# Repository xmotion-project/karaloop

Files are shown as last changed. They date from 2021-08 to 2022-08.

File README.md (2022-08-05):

<p align="center">
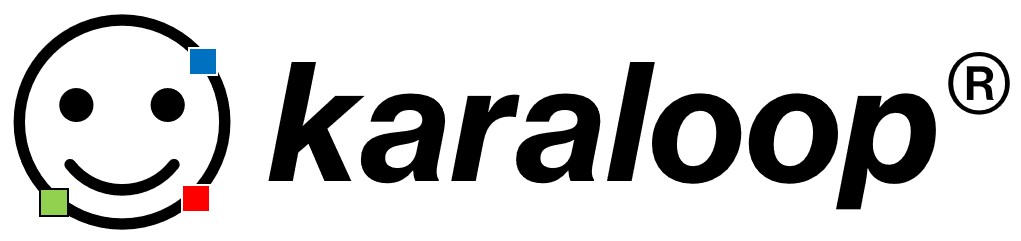
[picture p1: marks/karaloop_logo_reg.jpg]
	
</p>  

<p align="center">	
	 
</p>

Can you imagine yourself interacting with phones, tablets, computers and other devices without hands? 

***karaloop*** is an initiative to advance the development of accessible and inclusive wearable hands-free interfaces, so in the future, anyone will be able to interact with any device, from anywhere, *without hands*, simply by performing movements of the face :relaxed:

The primary goal is to enable ubiquitous human-device interaction to all, regardless of physical abilities, environmental and socioeconomical constrains.     

## Contents

This repository contains a collection of wearable prototypes which measure voluntary movements of the face and translate them 
into mouse or keyboard commands sent via Bluetooth Low Energy (BLE) to any PC, iOS or Android device.

* [***karaloop*** P1.0](https://github.com/xmotion-project/karaloop/wiki/karaloop-P1.0)
* [***karaloop*** P2.0](https://github.com/xmotion-project/karaloop/wiki/karaloop-P2.0)
* [***karaloop*** P3.0](https://github.com/xmotion-project/karaloop/wiki/karaloop-P3.0)

Each prototype incorporates/explores different contact (C) and contactless (CL) sensing technology to capture facial movements: strain gauges ([***karaloop*** P1.0](https://github.com/xmotion-project/karaloop/wiki/karaloop-P1.0), C), potentiometers and microswitches ([***karaloop*** P2.0](https://github.com/xmotion-project/karaloop/wiki/karaloop-P2.0), C), and magnetomers and optical flow sensors ([***karaloop*** P3.0](https://github.com/xmotion-project/karaloop/wiki/karaloop-P3.0), c and CL). 

The ***karaloop*** wearables are not finished products. The Technology Readiness Level ([TRL](https://en.wikipedia.org/wiki/Technology_readiness_level)) varies across prototypes. While [***karaloop*** P1.0](https://github.com/xmotion-project/karaloop/wiki/karaloop-P1.0) and [P2.0](https://github.com/xmotion-project/karaloop/wiki/karaloop-P2.0) are still in feasibility evaluation and development phases (TRL 3-5), [***karaloop*** P3.0](https://github.com/xmotion-project/karaloop/wiki/karaloop-P3.0) has been preliminary evaluated in operational environments (TRL 7).       

[***karaloop*** P1.0](https://github.com/xmotion-project/karaloop/wiki/karaloop-P1.0), [P2.0](https://github.com/xmotion-project/karaloop/wiki/karaloop-P2.0) and [P3.0](https://github.com/xmotion-project/karaloop/wiki/karaloop-P3.0) use the [Adafruit Feather nRF52 Bluefruit](https://learn.adafruit.com/bluefruit-nrf52-feather-learning-guide?view=all). 

## Licenses

We believe that the open source movement can foster mass technological inclusivity, accessibility and education. 

All (i.e. software, firmware, circuit schematics, CAD designs, assembly guides) source and documentation files in this repository are licensed under open source licenses [approved by the Open Source Initiative (OSI)](https://opensource.org/licenses/alphabetical). Software and firmware are licensed under [Apache License, Version 2.0](https://www.apache.org/licenses/LICENSE-2.0) or [GNU General Public License version 3 (GPLv3)](https://www.gnu.org/licenses/gpl-3.0.en.html), hardware schematics and design files under [CERN Open Hardware Licence Version 2 - Permissive (CERN OHL-P-V2)](https://ohwr.org/cern_ohl_p_v2.pdf), and contents in README, /src, wiki and assembly guides under [Creative Commons Attribution 4.0 International (CC BY 4.0)](https://creativecommons.org/licenses/by/4.0/).

[***karaloop*** P1.0](https://github.com/xmotion-project/karaloop/wiki/karaloop-P1.0) [CH000014], [P2.0](https://github.com/xmotion-project/karaloop/wiki/karaloop-P2.0) [CH000015] and [P3.0](https://github.com/xmotion-project/karaloop/wiki/karaloop-P3.0) [CH000016] are [certified](https://certification.oshwa.org/) open source hardware by the [Open Source Hardware Association (OSHWA)](https://www.oshwa.org/). 

<p align="left">
	
	
	
</p> 

## Trademark

***karaloop*** is a registered trademark. Find the ***karaloop*** trademark guidelines [here](https://github.com/xmotion-project/karaloop/blob/main/karaloop%20TRADEMARK%20GUIDELINES.md).

## Contributing to ***karaloop***

:relaxed::+1::tada: First of all, thank you for taking the time to contribute! :tada::+1::relaxed:

This repository and everyone participating in it is governed by the [***karaloop*** Code of Conduct](CODE_OF_CONDUCT.md). By participating, you are expected to uphold this code. 

#### **Do you have questions?**

We have the *Q&A message board* where *karaloopers* will do their best to address any questions that you may have:

* [***karaloop*** Discussions: Q&A](https://github.com/xmotion-project/karaloop/discussions/categories/q-a)

#### **Do you have ideas about new features on existing prototypes or new designs?**

Let's discuss your ideas in the *Ideas message board*. Please do not open an issue on GitHub until you and the *maintainers* come up with a roadmap.

* [***karaloop*** Discussions: Ideas](https://github.com/xmotion-project/karaloop/discussions/categories/ideas)

#### **Do you want to contribute improving the documentation, wiki or the project workflows/tooling?**

Tell us what do you want to improve in the *Improvements message board*. Please do not open an issue on GitHub until you and the *maintainers* come up with a roadmap.

* [***karaloop*** Discussions: Improvements](https://github.com/xmotion-project/karaloop/discussions/categories/improvements-documentation-wiki-workflow-tooling)

#### **Do you want to share or showcase your work?**

Leave your messages at the *General message board*: 

* [***karaloop*** Discussions: General](https://github.com/xmotion-project/karaloop/discussions/categories/general)

## Credits

The karaloop initiative was inspired by [Ferran Galán](https://scholar.google.com/citations?user=XTcJiLwAAAAJ)'s previous work [ChinMotion](https://arxiv.org/abs/1606.02711). 

The prototype development work of [***karaloop*** P1.0](https://github.com/xmotion-project/karaloop/wiki/karaloop-P1.0), [P2.0](https://github.com/xmotion-project/karaloop/wiki/karaloop-P2.0) and [P3.0](https://github.com/xmotion-project/karaloop/wiki/karaloop-P3.0) was partially sponsored by [Fondation Privée des HUG](https://www.fondationhug.org/) and [Wyss Center](https://wysscenter.ch/) through grants/support awarded to Ferran Galán at [University of Geneva](https://www.unige.ch/en/university/presentation/).

Quentin Praz, Ahmad Jaafar, Spiros Schoinas and Philippe Passeraub from [HEPIA](https://www.hesge.ch/hepia/), and Ferran Galán from [University of Geneva](https://www.unige.ch/en/university/presentation/) contributed to the conception and development of [***karaloop*** P1.0](https://github.com/xmotion-project/karaloop/wiki/karaloop-P1.0), [P2.0](https://github.com/xmotion-project/karaloop/wiki/karaloop-P2.0) and [P3.0](https://github.com/xmotion-project/karaloop/wiki/karaloop-P3.0).

## Contact

For any other inquiries beyond the topics covered in [***karaloop*** Discussions](https://github.com/xmotion-project/karaloop/discussions/categories), please reach to us at [karaloop@protonmail.com](mailto:karaloop@protonmail.com).

<p align="center">
		
</p>

<a rel="license" href="http://creativecommons.org/licenses/by/4.0/">

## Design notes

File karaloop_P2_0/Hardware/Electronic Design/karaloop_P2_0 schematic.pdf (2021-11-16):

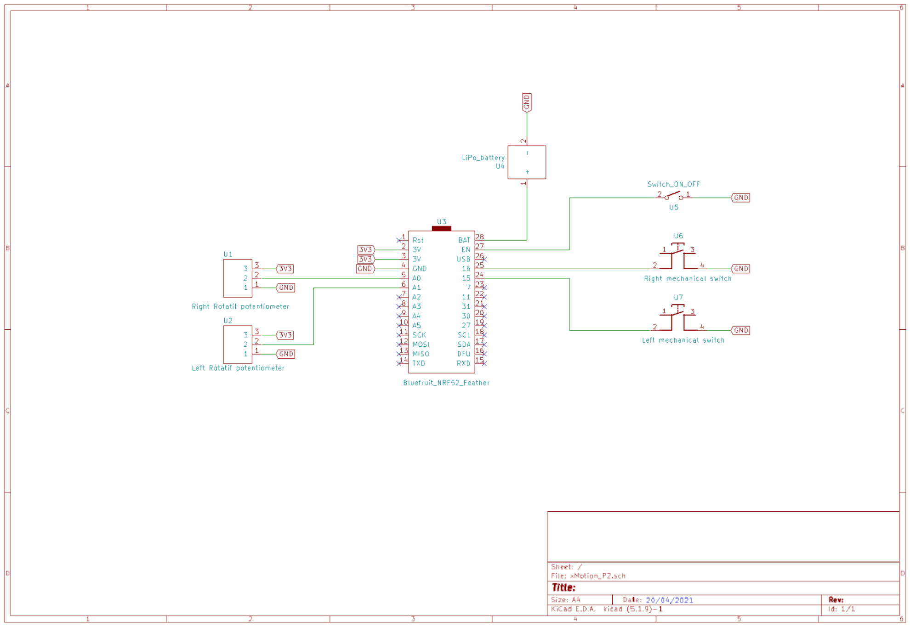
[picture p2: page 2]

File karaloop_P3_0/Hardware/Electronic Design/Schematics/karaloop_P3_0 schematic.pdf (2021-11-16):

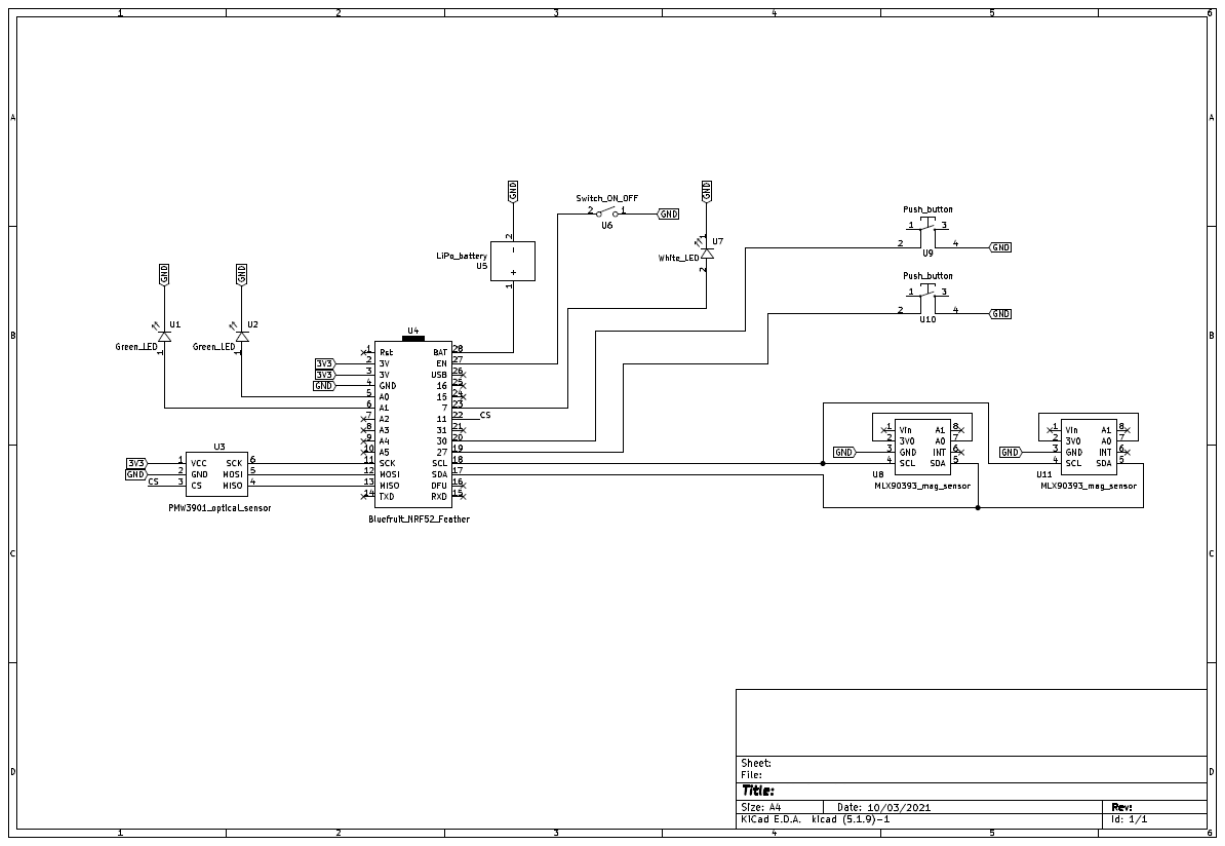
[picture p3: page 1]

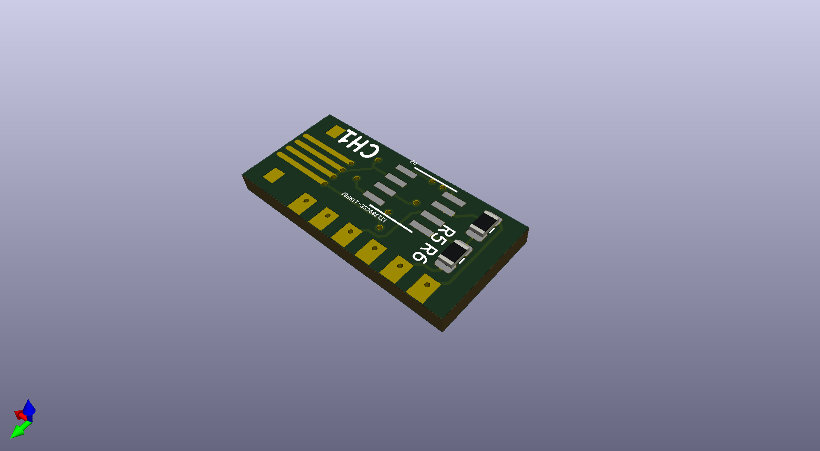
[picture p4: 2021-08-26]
karaloop_P1_0/Hardware/Electronic Design/PCBs/PCB channel 1/first_channel_half_bridge.png

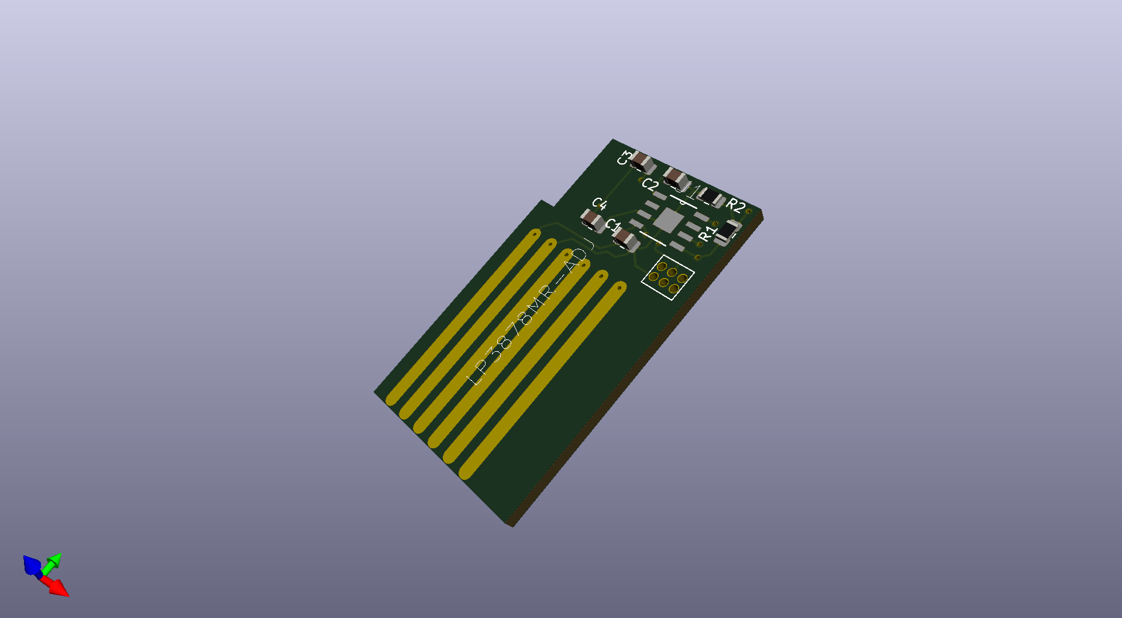
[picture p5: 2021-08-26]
karaloop_P1_0/Hardware/Electronic Design/PCBs/Perpendicular PCB/perpendicular_pcb_2.png

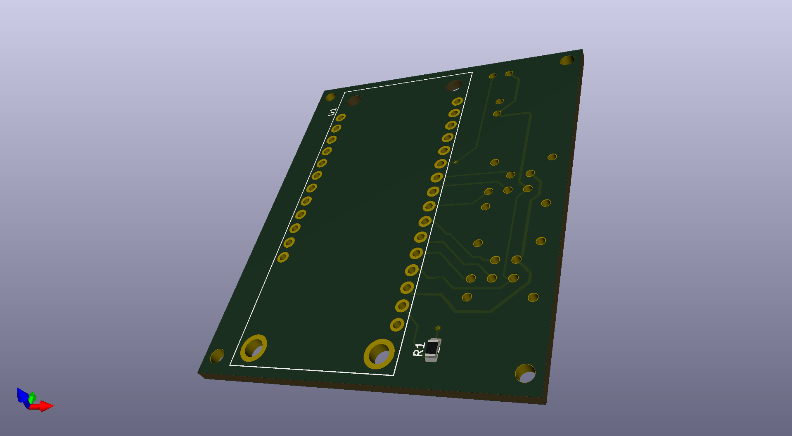
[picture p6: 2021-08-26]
karaloop_P1_0/Hardware/Electronic Design/PCBs/Main PCB/main_PCB_3.png

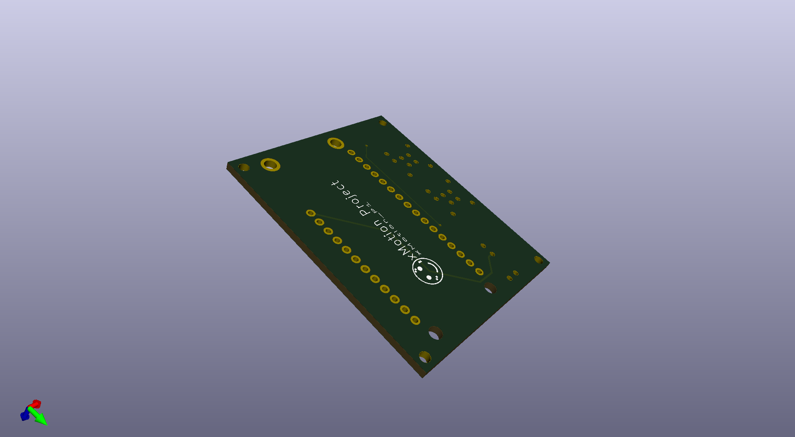
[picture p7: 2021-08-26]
karaloop_P1_0/Hardware/Electronic Design/PCBs/Main PCB/main_PCB_3_dessous.png

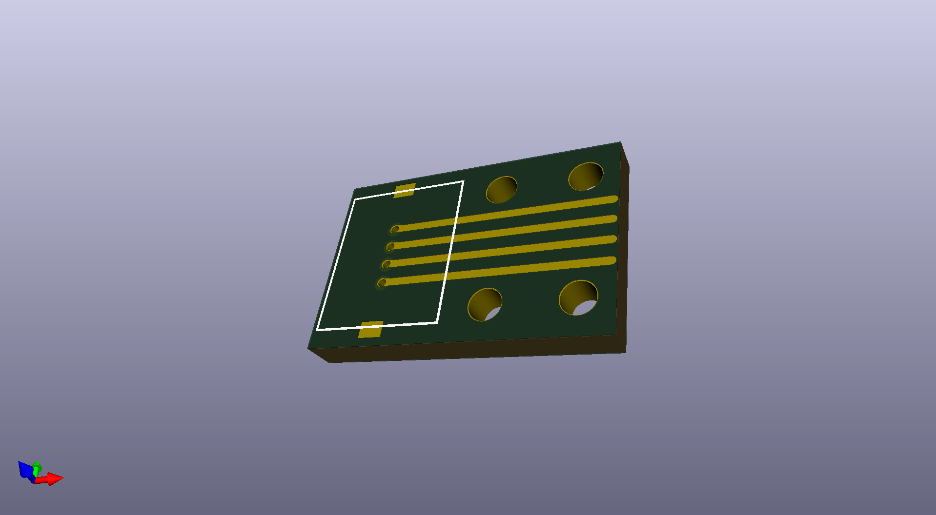
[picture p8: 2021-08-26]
karaloop_P1_0/Hardware/Electronic Design/PCBs/PCB probe connection/pcb connexion_3.png

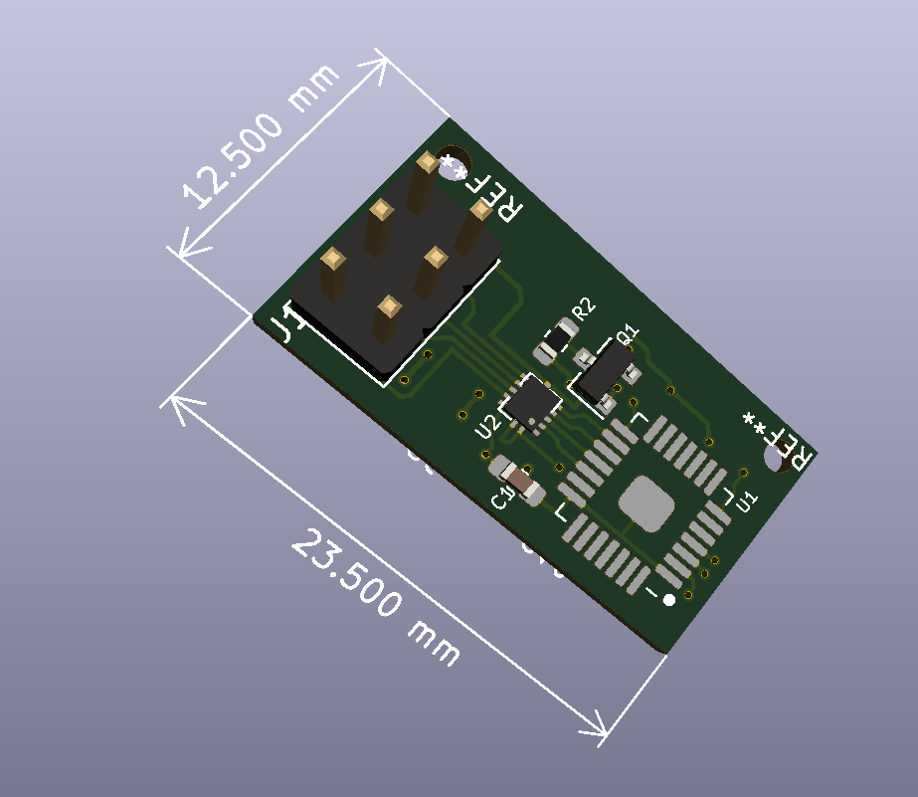
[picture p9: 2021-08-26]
karaloop_P3_0/Hardware/Electronic Design/PCB/PCB_optical_sensors_2_PMW/Capture.PNG

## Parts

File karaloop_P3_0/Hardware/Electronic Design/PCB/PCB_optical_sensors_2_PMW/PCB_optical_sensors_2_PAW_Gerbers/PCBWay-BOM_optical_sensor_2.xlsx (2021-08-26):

 |  |  | xxxx xxxx xxxxx xxPCS BOM (Sample Bill of Materials)
Item # | *Designator | *Qty | Manufacturer | *Mfg Part # | Description / Value | *Package/Footprint | Type | Your Instructions / Notes
1 | C1 | 1 | KEMET | C0603C105K9RAC7411 | Multilayer Ceramic Capacitors MLCC - SMD/SMT 6.3V 1uF X7R 0603 0.1 | 0603 | SMD | ok
2 | C2 | 1 | KEMET | C0603C104K5RECAUTO7411 | Multilayer Ceramic Capacitors MLCC - SMD/SMT 50V 0.1uF 0603 X7R 10% AEC-Q200 | 0603 | SMD | ok
3 | C3 | 1 | KEMET | C0603C106M8PACTU | Multilayer Ceramic Capacitors MLCC - SMD/SMT 10V 10uF 0603 X5R 20% | 0603 | SMD | ok
4 | C4 | 1 | KEMET | C0603C104K5RECAUTO7411 | Multilayer Ceramic Capacitors MLCC - SMD/SMT 50V 0.1uF 0603 X7R 10% AEC-Q200 | 0603 | SMD | ok
5 | C5 | 1 | KEMET | C0603C475M9PAC7411 | Multilayer Ceramic Capacitors MLCC - SMD/SMT 6.3V 4.7uF 0603 X5R 20% | 0603 | SMD | ok
6 | C6 | 1 | KEMET | C0603C105K9RAC7411 | Multilayer Ceramic Capacitors MLCC - SMD/SMT 6.3V 1uF X7R 0603 0.1 | 0603 | SMD | ok
7 | C7 | 1 | KEMET | C0603C104K5RECAUTO7411 | Multilayer Ceramic Capacitors MLCC - SMD/SMT 50V 0.1uF 0603 X7R 10% AEC-Q200 | 0603 | SMD | ok
8 | C8 | 1 | KEMET | C0603C105K9RAC7411 | Multilayer Ceramic Capacitors MLCC - SMD/SMT 6.3V 1uF X7R 0603 0.1 | 0603 | SMD | ok
9 | C9 | 1 | KEMET | C0603C105K9RAC7411 | Multilayer Ceramic Capacitors MLCC - SMD/SMT 6.3V 1uF X7R 0603 0.1 | 0603 | SMD | ok
10 | C10 | 1 | KEMET | C0603C104K5RECAUTO7411 | Multilayer Ceramic Capacitors MLCC - SMD/SMT 50V 0.1uF 0603 X7R 10% AEC-Q200 | 0603 | SMD | ok
11 | C11 | 1 | KEMET | C0603C104K5RECAUTO7411 | Multilayer Ceramic Capacitors MLCC - SMD/SMT 50V 0.1uF 0603 X7R 10% AEC-Q200 | 0603 | SMD | ok
12 | Q1 | 1 | ON Semiconductor / Fairchild | BSS138 | LOGIQUE MOSFET SOT-23 N-CH | SOT-23-3 | SMD | ok
13 | Q2 | 1 | ON Semiconductor / Fairchild | BSS138 | LOGIQUE MOSFET SOT-23 N-CH | SOT-23-3 | SMD | ok
14 | R1 | 1 | Semi-conducteur ROHM | SFR03EZPJ472 | Thick Film Resistors - SMD 0603 4.7Kohms 5% Anti-Sulfur AEC-Q200 | 0603 | SMD | ok
15 | R2 | 1 | Semi-conducteur ROHM | SFR03EZPJ472 | Thick Film Resistors - SMD 0603 4.7Kohms 5% Anti-Sulfur AEC-Q200 | 0603 | SMD | ok
16 | R3 | 1 | Semi-conducteur ROHM | SFR03EZPJ472 | Thick Film Resistors - SMD 0603 4.7Kohms 5% Anti-Sulfur AEC-Q200 | 0603 | SMD | ok
17 | R4 | 1 | Semi-conducteur ROHM | SFR03EZPJ472 | Thick Film Resistors - SMD 0603 4.7Kohms 5% Anti-Sulfur AEC-Q200 | 0603 | SMD | ok
18 | U1 | 1 | PixArt Imaging Inc. | PAW3903E1-TXQT | Optical Motion Tracking Chip | 28-pin COB | COB | ok
19 | U2 | 1 | Texas Instruments | TXB0104RUTR | Translation - Voltage Levels 4B Bidir Vltg-Level Translator | UQFN-12 | SMD | ok
20 | U3 | 1 | Texas Instruments | TLV70218DBVR | LDO 1.8V Voltage Regulators 300mALow IQLDO Reg | SOT-23-5 | SMD | ok
21 | U4 | 1 | Texas Instruments | TLV70228DBVR | LDO 2.8V Voltage Regulators 300mALow IQLDO Reg | SOT-23-5 | SMD | ok
 |  |  |  |  |  |  |  |  | 24-SSOP
 |  |  |  |  |  |  |  |  | 8-SOIC
 |  |  |  |  |  |  |  |  | DPAK
 |  |  |  |  |  |  |  |  | 20SSOP
 |  |  |  |  |  |  |  |  | GBJ
Need a quick and accurante quote? Need an efficient production? Please read SMT Ordering Necessary Files & Info in 1 minute. Thank you very much! (https://www.pcbway.com/smt_ordering_guide.html) |  |  |  |  |  |  |  |  | 0805
 |  |  |  |  |  |  |  |  | 0815
Click for Instructions on How to Create a BOM (https://www.pcbway.com/blog/PCB_Assembly/How_to_Build_a_BOM__Bill_Of_Materials_.html) |  |  |  |  |  |  |  |  | 0805
 |  |  |  |  |  |  |  |  | 0805
 |  |  |  |  |  |  |  |  | 0805
 |  |  |  |  |  |  |  |  | 0805
 |  |  |  |  |  |  |  |  | SMT 6P
 |  |  |  |  |  |  |  |  | SMD
 |  |  |  |  |  |  |  |  | SMD
 |  |  |  |  |  |  |  |  | 5POS
 |  |  |  |  |  |  |  |  | 5POS
 |  |  |  |  |  |  |  |  | 5POS
 |  |  |  |  |  |  |  |  | 5POS
 |  |  |  |  |  |  |  |  | 5POS
 |  |  |  |  |  |  |  |  | 5POS
 |  |  |  |  |  |  |  |  | 5POS

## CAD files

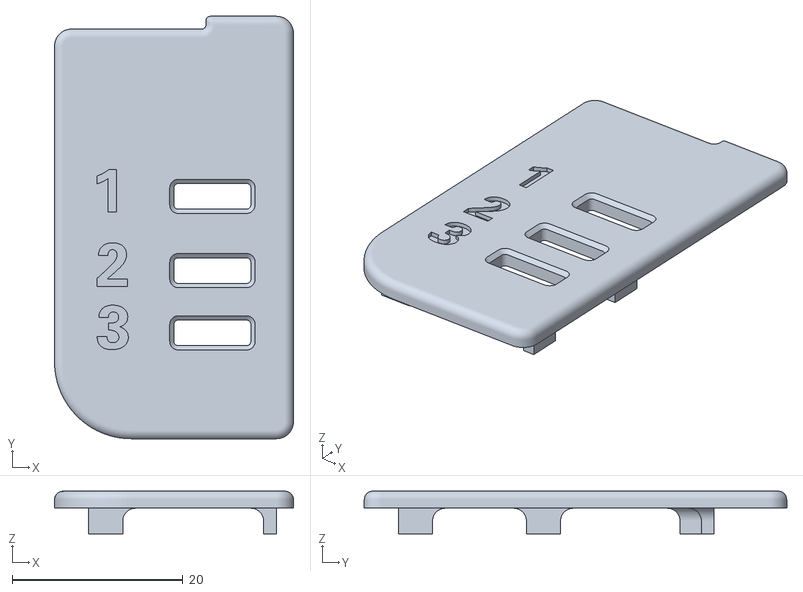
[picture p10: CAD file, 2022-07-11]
karaloop_P1_0/Hardware/Mechanical Design/STL/hub_cover_box_left.stl
28.0 x 49.5 x 5.00

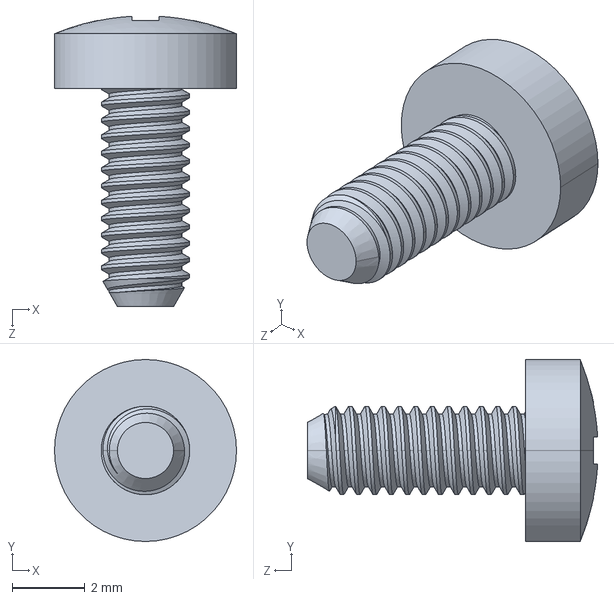
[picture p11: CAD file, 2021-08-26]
karaloop_P2_0/Hardware/Mechanical Design/Sub-assembly/Headset band/STEP/Philips_head_m2_5_6mm.step
5.00 x 5.00 x 7.98 mm

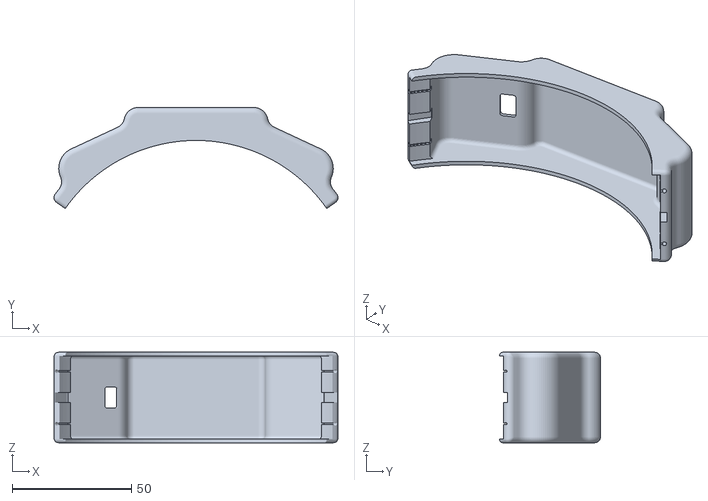
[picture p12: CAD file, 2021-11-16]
karaloop_P2_0/Hardware/Mechanical Design/Sub-assembly/Headset band/STL/flexible_top_cover.stl
119.2 x 42.4 x 38.0

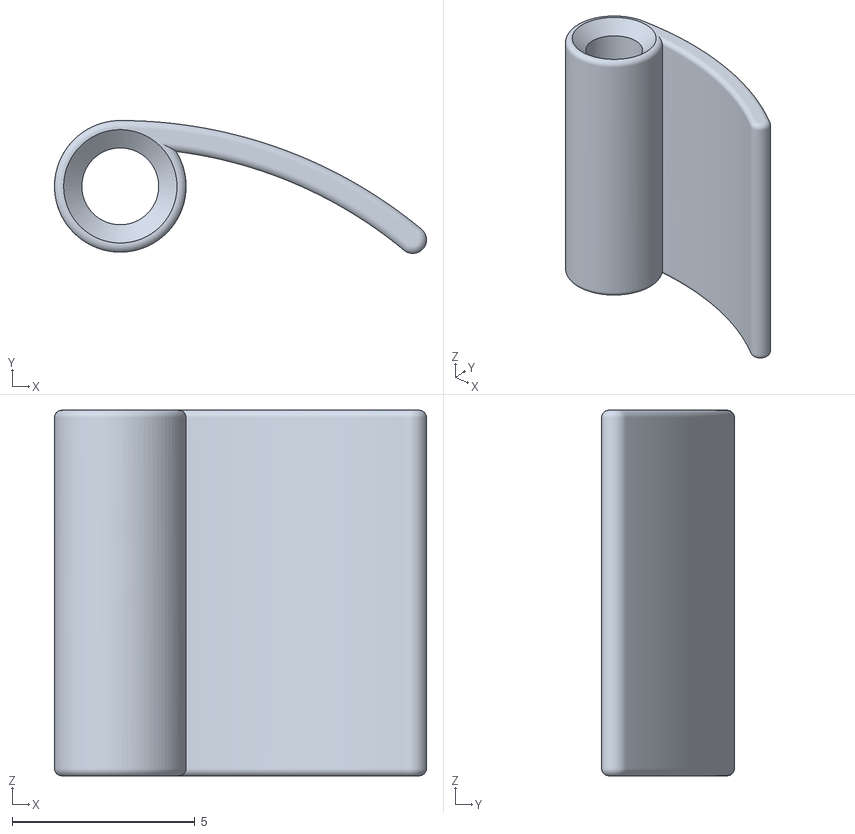
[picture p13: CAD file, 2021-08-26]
karaloop_P2_0/Hardware/Mechanical Design/Sub-assembly/Potentiometric probes/STL/flexible_torsion_spring.stl
10.2 x 3.64 x 10.0

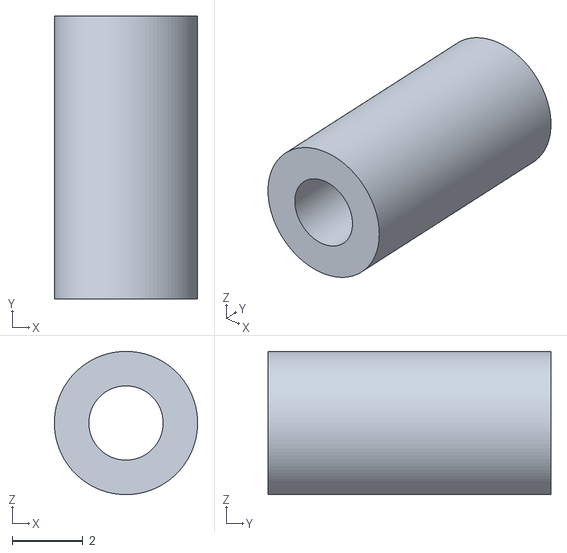
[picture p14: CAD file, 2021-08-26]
karaloop_P2_0/Hardware/Mechanical Design/Sub-assembly/Switch probe/STL/switch_housing_axe.stl
4.05 x 8.00 x 4.05

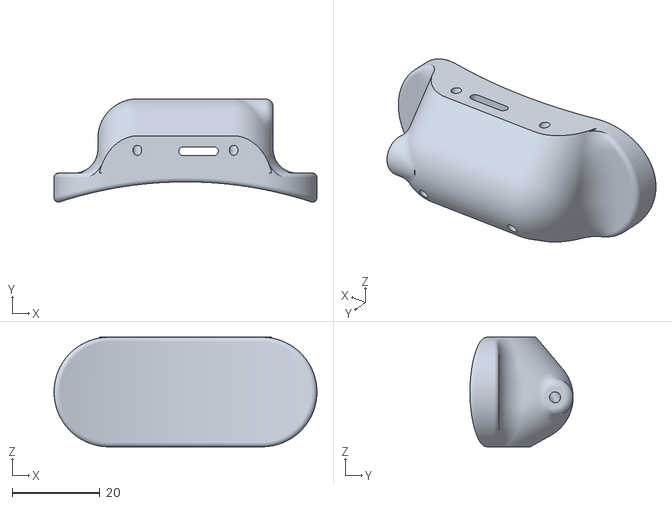
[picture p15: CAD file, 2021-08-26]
karaloop_P3_0/Hardware/Mechanical Design/Sub-assembly/Headset band/STL/left_side_node.stl
60.0 x 23.6 x 25.0

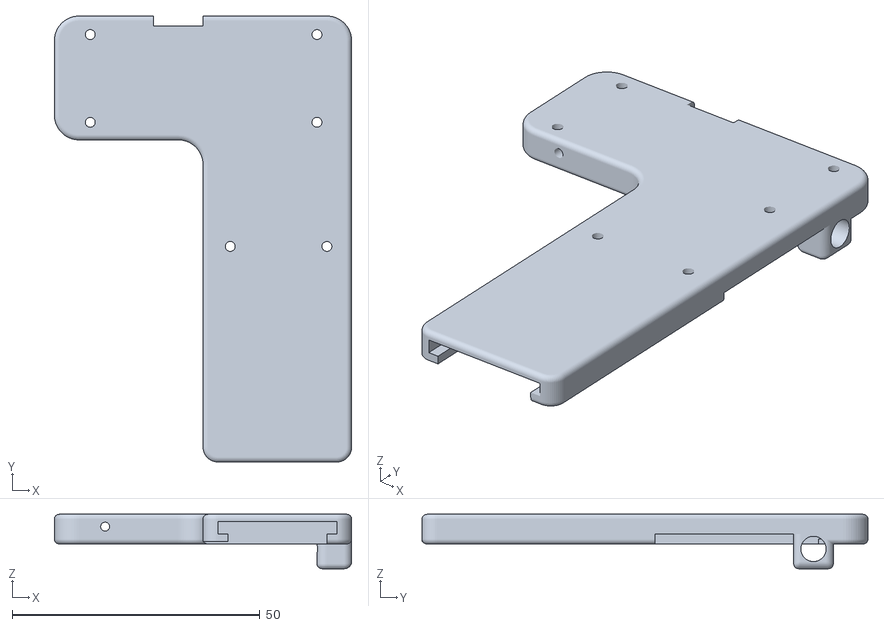
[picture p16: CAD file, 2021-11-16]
karaloop_P3_0/Hardware/Mechanical Design/Sub-assembly/Left hub/STL/left_hub_holder.stl
60.0 x 90.0 x 11.0

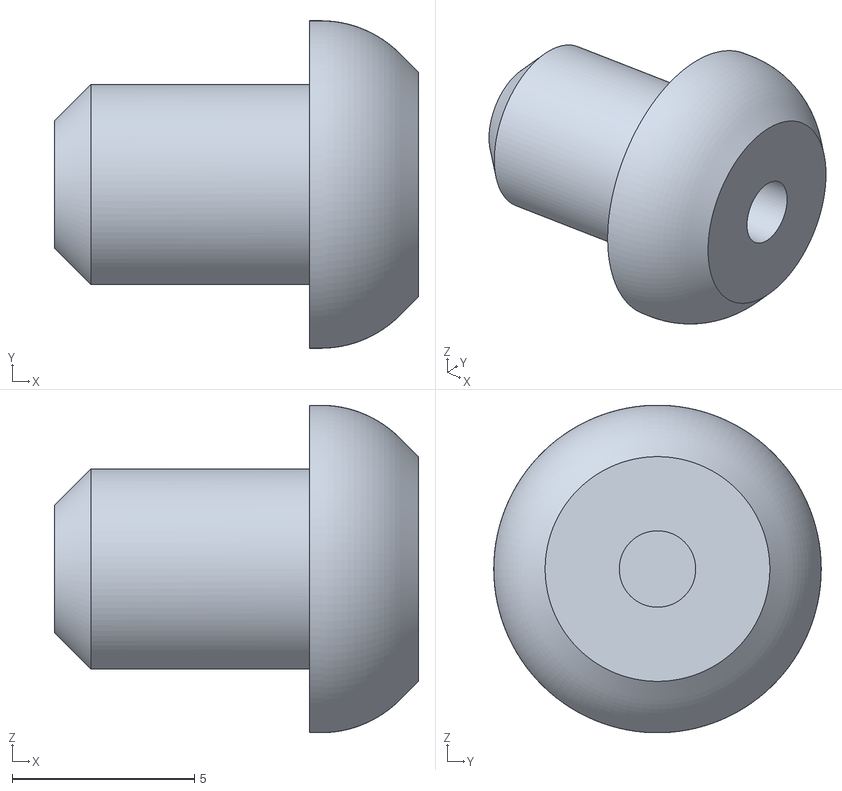
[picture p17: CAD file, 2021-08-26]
karaloop_P3_0/Hardware/Mechanical Design/Sub-assembly/Magnetic probe/STL/end_part_holder.stl
10.0 x 9.00 x 9.00

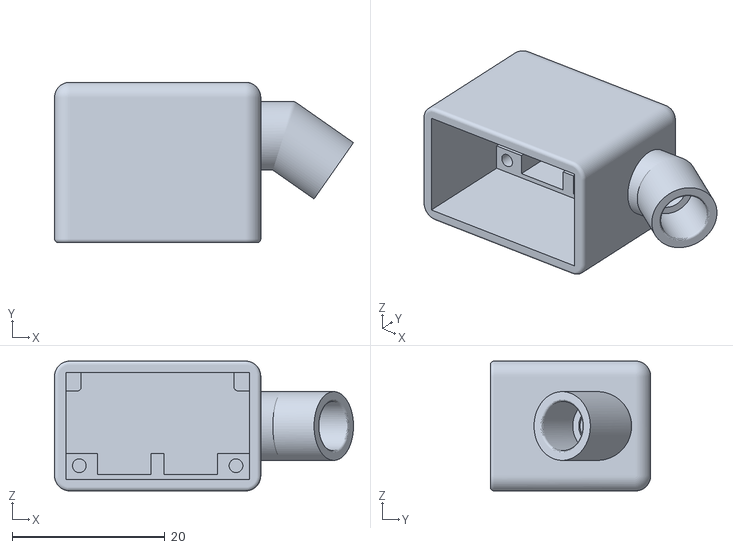
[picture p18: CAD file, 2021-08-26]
karaloop_P3_0/Hardware/Mechanical Design/Sub-assembly/Optical probe/STL/optical_sensor_case.stl
39.1 x 21.0 x 17.0

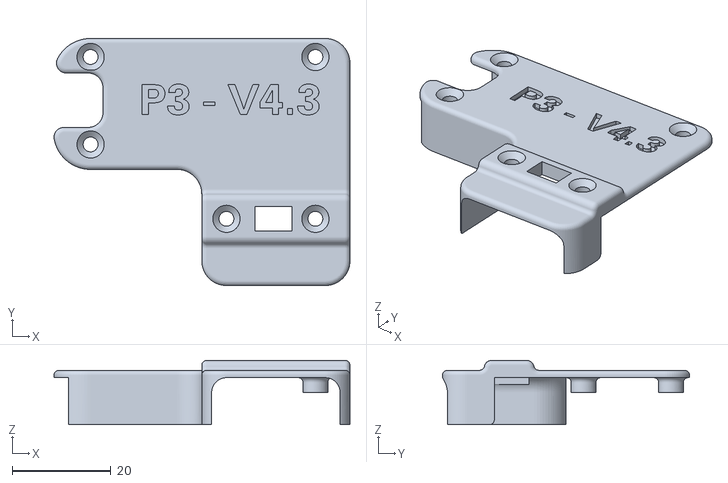
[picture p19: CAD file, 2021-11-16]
karaloop_P3_0/Hardware/Mechanical Design/Sub-assembly/Right hub/STL/right_hub_cover.stl
59.9 x 50.0 x 13.0

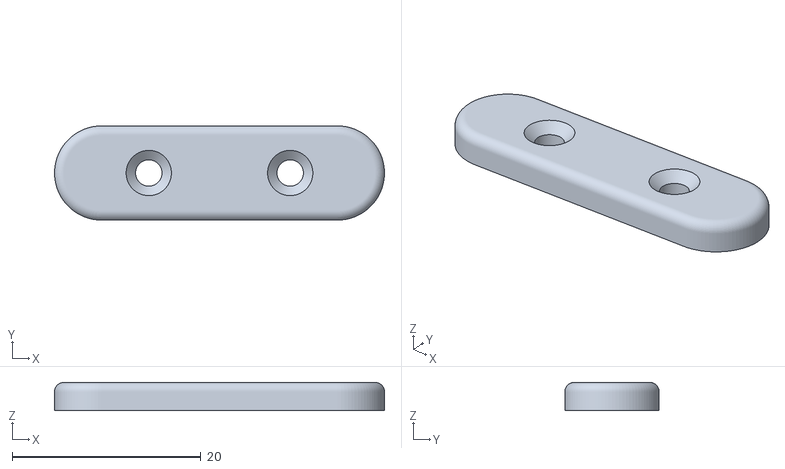
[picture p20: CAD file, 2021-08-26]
karaloop_P2_0/Hardware/Mechanical Design/Sub-assembly/Headset band/STL/top_flex_side_pad.stl
35.0 x 10.0 x 3.00

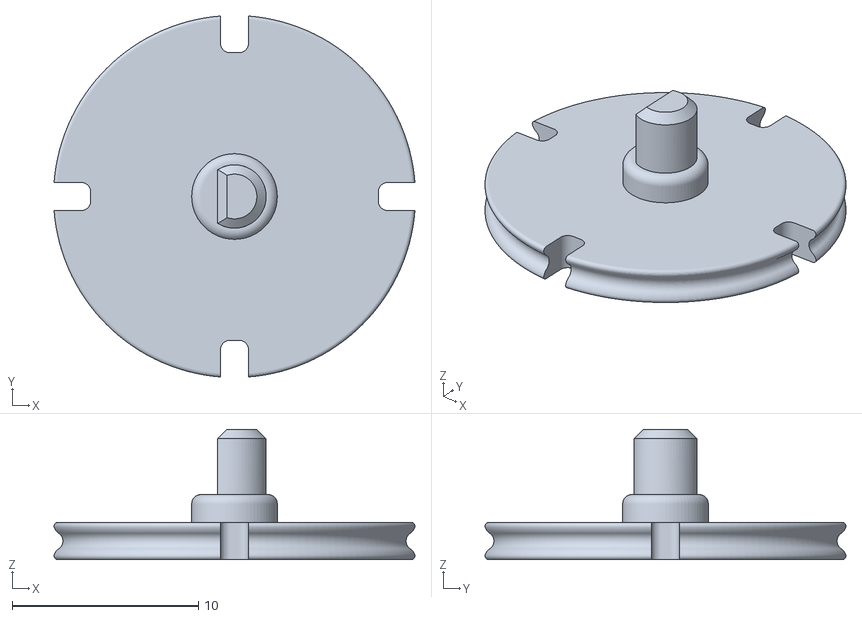
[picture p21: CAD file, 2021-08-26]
karaloop_P2_0/Hardware/Mechanical Design/Sub-assembly/Potentiometric probes/STL/potentiometer_wheel.stl
19.4 x 19.4 x 7.00

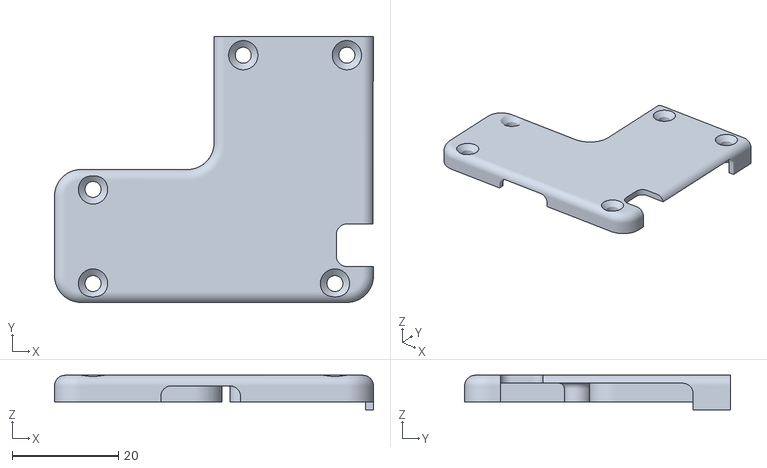
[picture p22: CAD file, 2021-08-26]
karaloop_P3_0/Hardware/Mechanical Design/Sub-assembly/Left hub/STL/left_hub_cover.stl
60.0 x 50.0 x 6.50

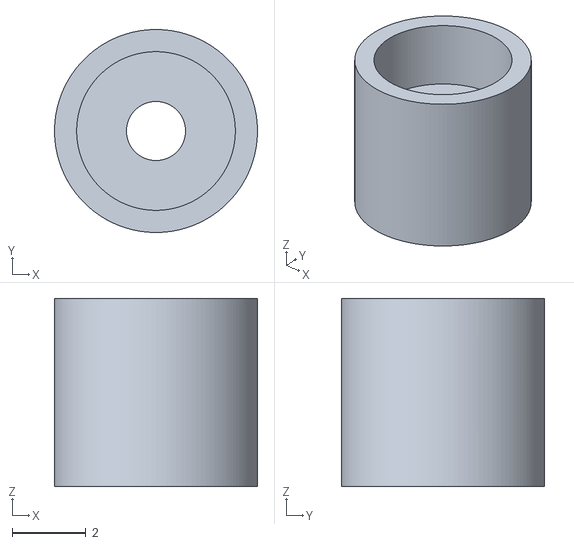
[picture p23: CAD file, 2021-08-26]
karaloop_P3_0/Hardware/Mechanical Design/Sub-assembly/Magnetic probe/STL/magnet_holder.stl
5.50 x 5.50 x 5.10

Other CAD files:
karaloop_P1_0/Hardware/Mechanical Design/STL/hub_cover_box_right.stl
karaloop_P3_0/Hardware/Mechanical Design/Sub-assembly/Headset band/STL/right_side_node.stl
karaloop_P3_0/Hardware/Mechanical Design/Sub-assembly/Optical probe/STL/sliding_join_female.stl
karaloop_P1_0/Hardware/Mechanical Design/STL/ball_joint_connector_12.stl
karaloop_P1_0/Hardware/Mechanical Design/STL/ball_joint_connector_3.stl
karaloop_P1_0/Hardware/Mechanical Design/STL/ball_joints.stl
karaloop_P1_0/Hardware/Mechanical Design/STL/ball_joints_left.stl
karaloop_P1_0/Hardware/Mechanical Design/STL/ball_joints_right.stl
karaloop_P1_0/Hardware/Mechanical Design/STL/bottom_cover_control_box.stl
karaloop_P1_0/Hardware/Mechanical Design/STL/hub_box_left.stl
karaloop_P1_0/Hardware/Mechanical Design/STL/hub_box_right.stl
karaloop_P1_0/Hardware/Mechanical Design/STL/hub_support_cover_left.stl
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

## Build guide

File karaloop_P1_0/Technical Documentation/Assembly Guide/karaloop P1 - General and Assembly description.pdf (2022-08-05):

# GENERAL DESCRIPTION

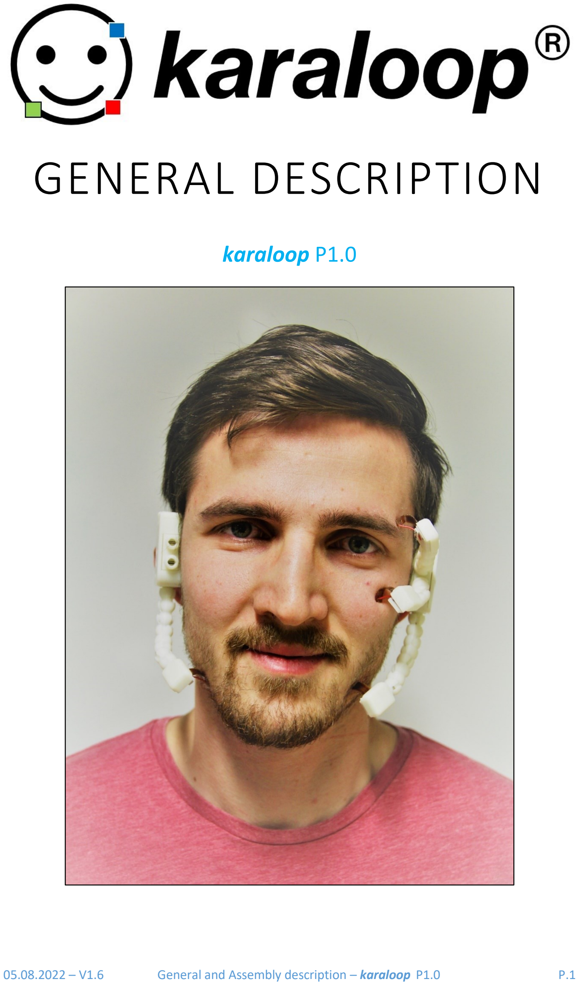
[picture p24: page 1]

05.08.2022 – V1.6 | General and Assembly description – karaloop P1.0 | P.1

# karaloop P1.0

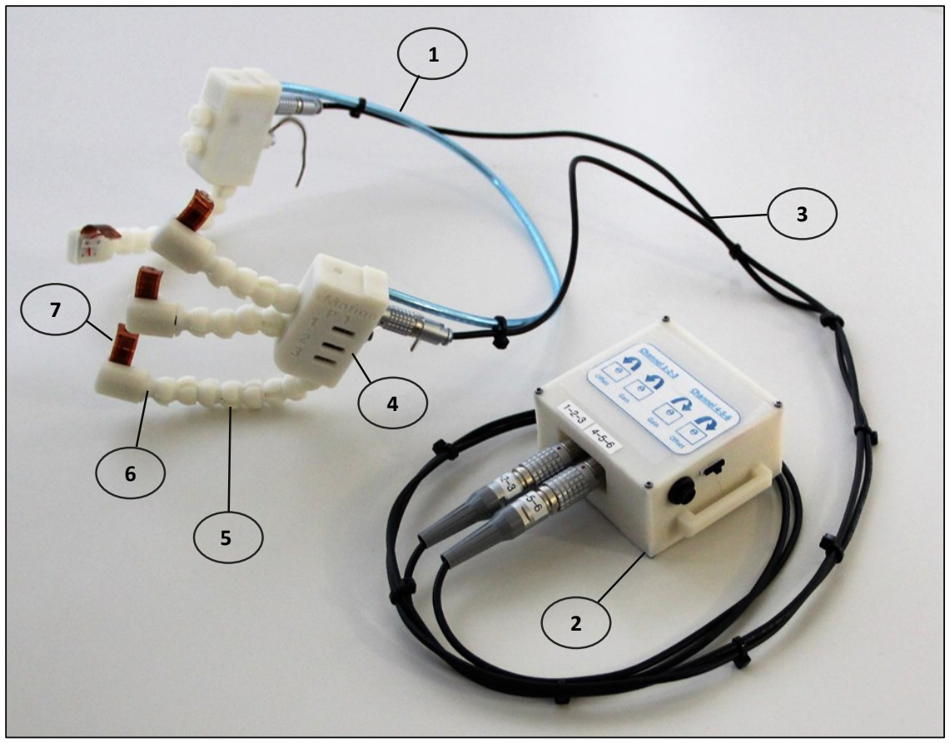
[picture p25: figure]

05.08.2022 – V1.6 | General and Assembly description – karaloop P1.0 | P.2

karaloop – Prototype 1.0 (P1.0)

P1.0 measures voluntary movements of the face and translates them into mouse or keyboard commands sent via Bluetooth Low Energy (BLE) to wirelessly communicate with any PC, iOS or Android device.
P1.0 consists of a light headset which incorporates up-to six articulated legs (three legs per side) that can conform the contour of any face and capture voluntary movements from any muscle, and a control box housing an open-source Arduino-compatible Bluefruit nRF52 Feather board that is automatically recognized as a human-interface device (HID). P1.0 transmits wirelessly preprogramed keyboard or mouse HID commands to any PC, iOS or Android device via BLE. The headset and the control box are connected via two cables relaying sensor signals from both sides of the face to the Bluefruit nR52 board.
The articulated headset legs are made of 3D printed modular Lego-like pieces with ball joints allowing the required adjustments of length and direction to fit any face contour. The modular design further facilitates replacements if needed. At the end of each leg, a probe incorporates a flexible sensorthat, when in contact with the face, captures voluntary movements. The signals from the probes are relayed to an electronic hub (one per side) which amplifies and conditions the signals before sending them to the controller box.

P1.0 components. (1) Headset; (2) Control box; (3) Cables connecting headset and control box (two, left and right); (4) Electronic hubs (two, left - right); (5) Legs (up-to six, three left - three right); (6) Probes (up-to six); (7) Flexible sensors (up-to six).

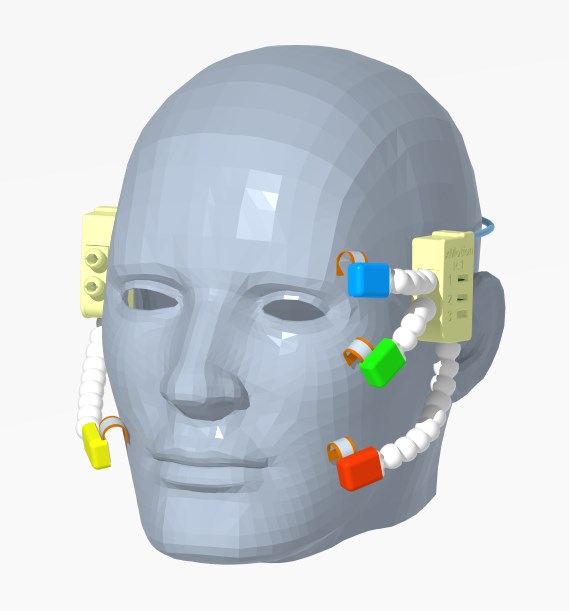
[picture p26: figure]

05.08.2022 – V1.6 | General and Assembly description – karaloop P1.0 | P.3

# ASSEMBLY DESCRIPTION

# karaloop P1.0

05.08.2022 – V1.6 | General and Assembly description – karaloop P1.0 | P.4

# CONTENTS

# General assembly

1

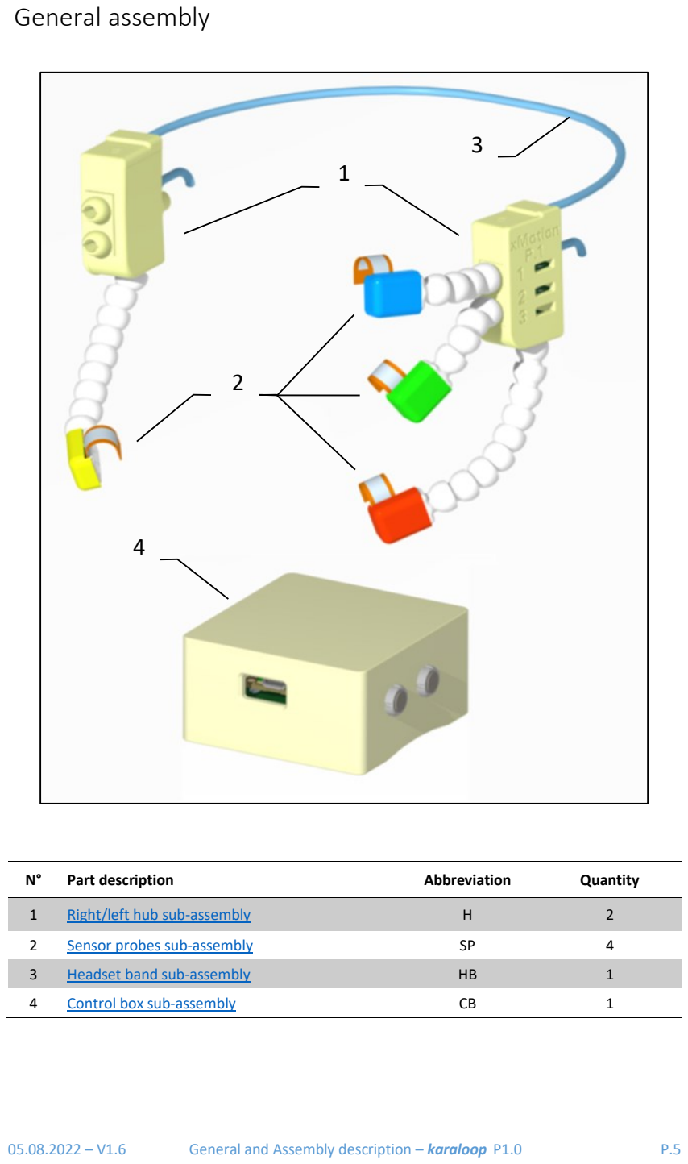
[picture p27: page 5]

05.08.2022 – V1.6 | General and Assembly description – karaloop P1.0 | P.5
N° | Part description | Abbreviation | Quantity
1 | Right/left hub sub-assembly | H | 2
2 | Sensor probes sub-assembly | SP | 4
3 | Headset band sub-assembly | HB | 1
4 | Control box sub-assembly | CB | 1

4

2

3

# 1. Right/left hub sub-assembly

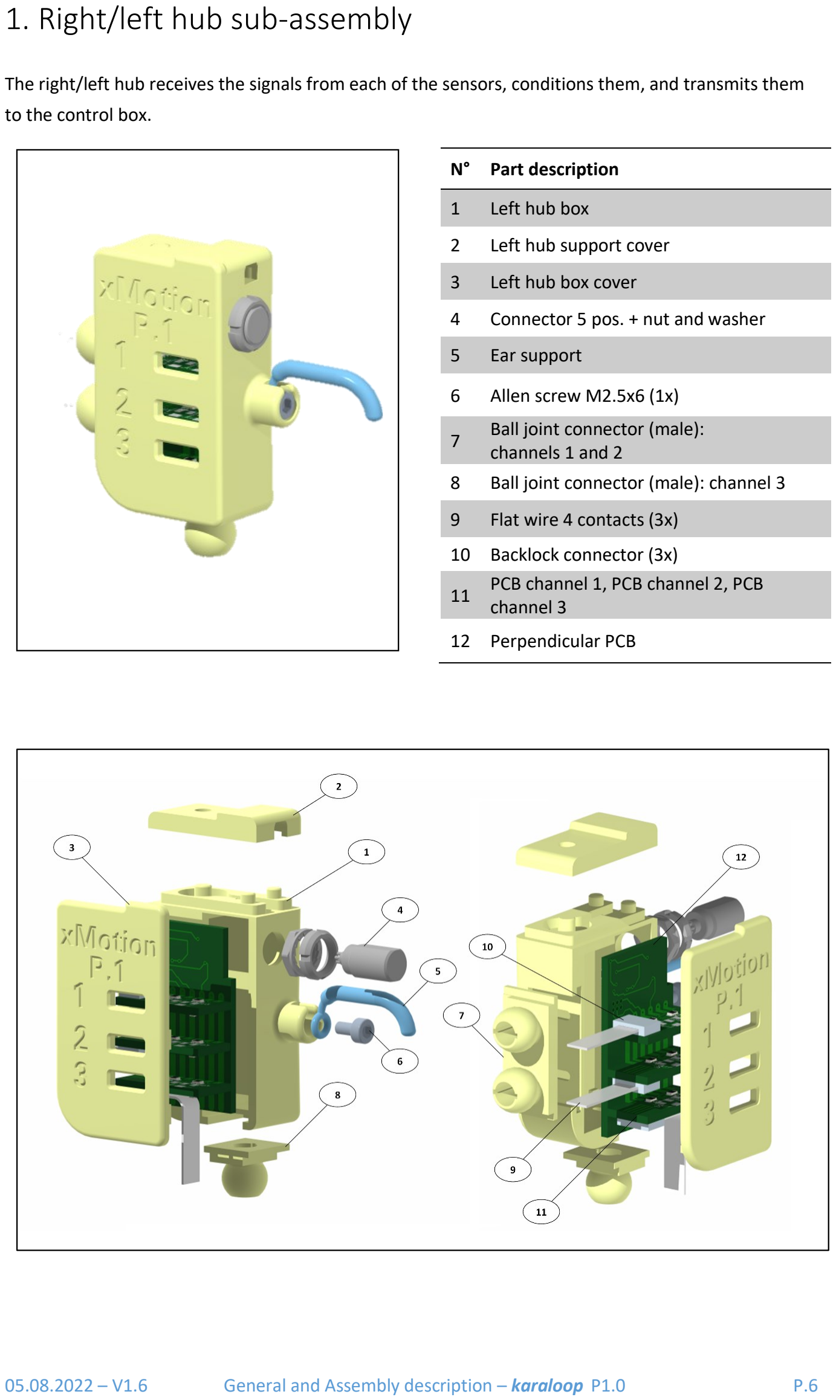
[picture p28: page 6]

05.08.2022 – V1.6 | General and Assembly description – karaloop P1.0 | P.6

The right/left hub receives the signals from each of the sensors, conditions them, and transmits them to the control box.

N° Part description

1 | Left hub box
2 | Left hub support cover
3 | Left hub box cover
4 | Connector 5 pos. + nut and washer
5 | Ear support
6 | Allen screw M2.5x6 (1x)
7 | Ball joint connector (male): channels 1 and 2
8 | Ball joint connector (male): channel 3
9 | Flat wire 4 contacts (3x)

10 Backlock connector (3x)
11 PCB channel 1, PCB channel 2, PCB channel 3

12 Perpendicular PCB

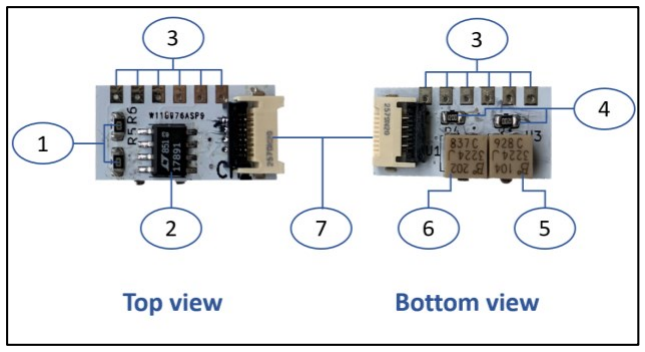
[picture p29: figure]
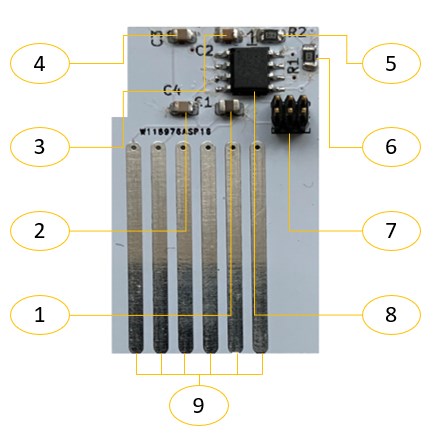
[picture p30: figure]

05.08.2022 – V1.6 | General and Assembly description – karaloop P1.0 | P.7

N° 11: PCB channels 1 – 3

N° | Part description
1 | 10kΩ resistors (2x)
2 | Operational amplifier
3 | Welding tracks
4 | 120Ω resistors (2x)
5 | Trimmer 100 kΩ 250 mW
6 | Trimmer 2 kΩ 250 mW
7 | Backlock connector

N° 12: Perpendicular PCB

N° | Part description
1 | 4.7µF capacitor
2 | 0.15µF capacitor
3 | 10nF capacitor
4 | 0.15µF Capacitor
5 | 100kΩ resistor
6 | 1kΩ resistor
7 | Headers 1.27x1.27mm
8 | Linear voltage regulator 1-5.5 V SOIC-8
9 | Welding tracks

# 2. Sensor probes sub-assembly

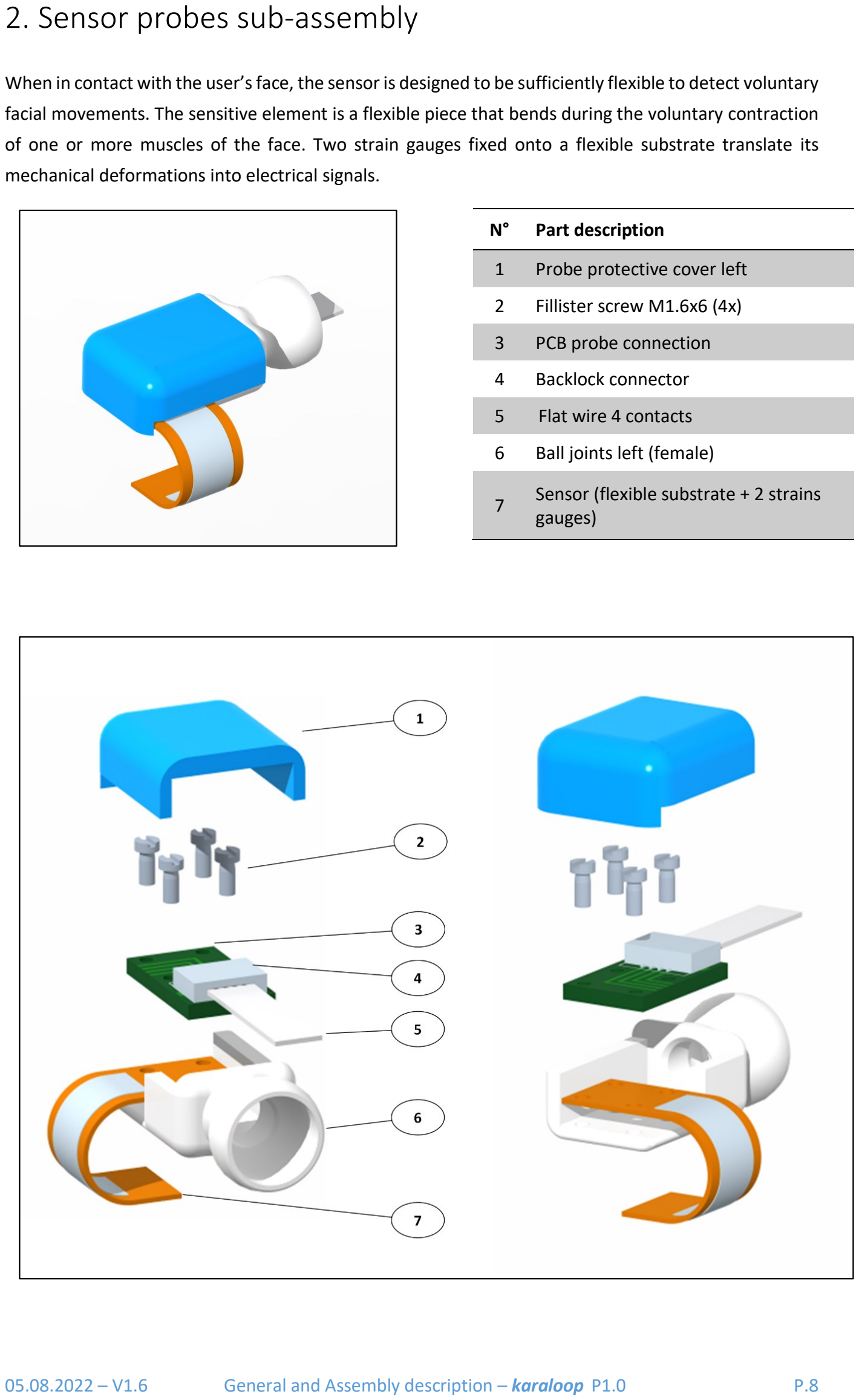
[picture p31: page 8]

05.08.2022 – V1.6 | General and Assembly description – karaloop P1.0 | P.8

When in contact with the user’s face, the sensor is designed to be sufficiently flexible to detect voluntary facial movements. The sensitive element is a flexible piece that bends during the voluntary contraction of one or more muscles of the face. Two strain gauges fixed onto a flexible substrate translate its mechanical deformations into electrical signals.

N° | Part description
1 | Probe protective cover left
2 | Fillister screw M1.6x6 (4x)
3 | PCB probe connection
4 | Backlock connector
5 | Flat wire 4 contacts
6 | Ball joints left (female)
7 | Sensor (flexible substrate + 2 strains gauges)

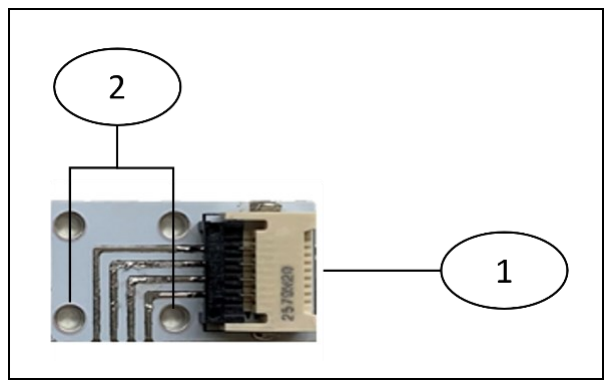
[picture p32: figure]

05.08.2022 – V1.6 | General and Assembly description – karaloop P1.0 | P.9

N° 3: Probe connection

N° | Part description
1 | Backlock connector
2 | Fillister screw M1.6x6 (4x)

## FABRICATION PROCESS

MATERIALS NEEDED can be found in Mechanical Part List (MPL, page 15), Printed Parts List (PPL, page 17) and Electronical part list (EPL, page 16)

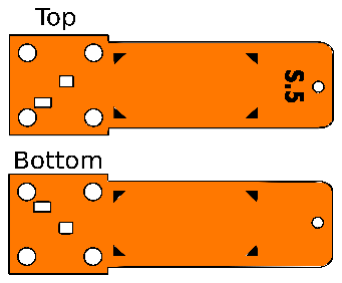
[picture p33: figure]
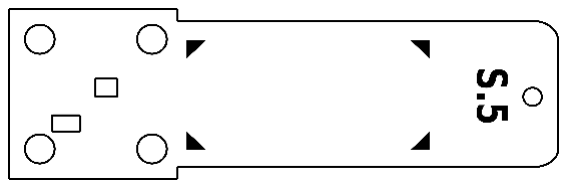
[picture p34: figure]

Step | Description | Materials needed

### 1 Cutting the substrate

| Laser cutting the Kapton substrate design. | • Laser cutter machine • Kapton sheet of 125 µm thickness (MPL

N°10)
| | • Substrate’s design (MPL N°17)

### 2 Cleaning-up the substrate

Sand the surface with at least a P400 micro-grain sandpaper from step 2.1. Clean both sides of the substrate with Isopropanol.

- P400 sandpaper (MPL N°12)
- Bottle of Isopropanol

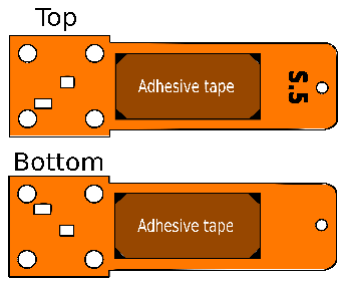
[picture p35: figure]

### 3 Placing the adhesive double-tape

Place the adhesive double-sided tape on each side of the substrate from step 2.2 in the designated rectangle below.

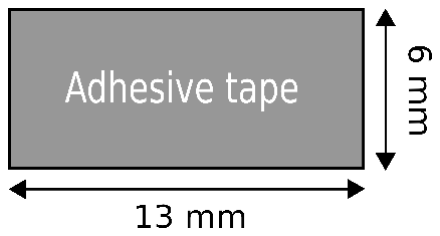
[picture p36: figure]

- Double tape Spandex of 50 µm thickness (MPL N°13)
- Scalpel or fine cutter

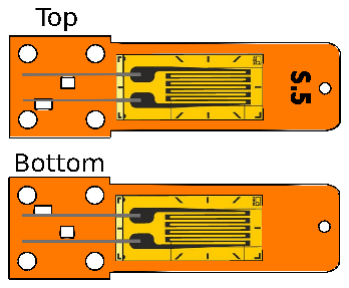
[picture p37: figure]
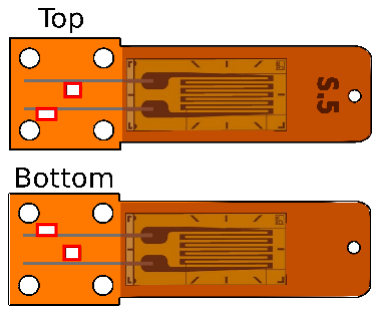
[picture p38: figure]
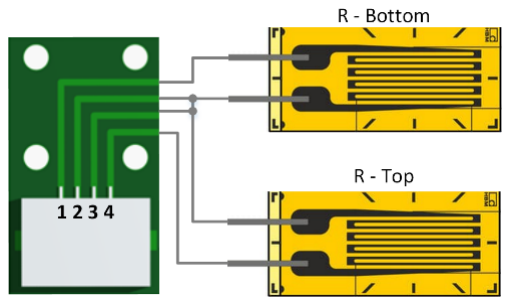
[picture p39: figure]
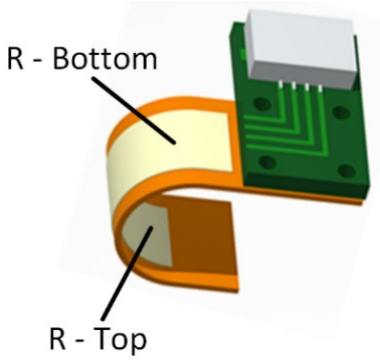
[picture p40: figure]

05.08.2022 – V1.6 | General and Assembly description – karaloop P1.0 | P.10
4 | Bonding of gauges Attach the strain gauges on top of the two adhesive tapes from step 2.3 and put a weight on it, for at least 1 hour, until the adhesive has bonded well.
- 2 Strain gauges HBM of 120 Ω (EPL N°16)
- A tweezer to manipulate the strain gauges
- Weight of ≥ 5 Kg

### 5 Electrical and mechanical protection

Recover each side of the substrate and strain gauges from step 2.4 with Kapton tape as shown below:

- Kapton tape of 25 µm thickness (MPL N°11)
- Scalpel or fine cutter

### 6 Electrical wiring

Place the substrate from step 2.5 on the bottom of the PCB probe connection. Route the strain gauges contacts through the substrate two little rectangular openings, which are highlighted in red in step 2.5. Then, solder the contacts as illustrated below:

- PCB probe connection with the zero-force connector mounted (Part N°2.3)
- Soldering station with tin wire
- A tweezer to manipulate the strain gauges

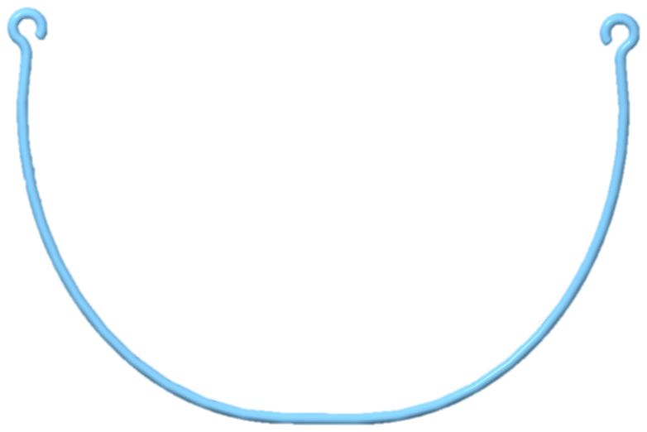
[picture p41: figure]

05.08.2022 – V1.6 | General and Assembly description – karaloop P1.0 | P.11

# 3. Headband sub-assembly

The headband is made of steel wire of 2 mm diameter. The steel wire is shaped using pliers to adapt to the head contour. Then, the steel wire is inserted into a flexible silicone-based tubing to improve the comfort of the wearable headset.

## FABRICATION PROCESS

MATERIALS NEEDED can be found in Mechanical Part List (MPL, page 15), Printed Parts List (PPL, page 17) and Electronical part list (EPL, page 16)

Step | Description | Materials needed

### 1 Curve the wire

| Curve the 30 cm long wire so that it follows the contour of
the head.
| | • Wires of Ø1.6 mm (MPL N°14)

### 2 Assembly with the silicone tube

Slide the curved wire from step 3.1 into the silicone tube.

- Silicone tube of Ø2 mm (MPL N°15)

### 3 Curve both ends of the wire and assembly with right/left

hub (Part N°1)
Curve each end of the wire from step 3.2, so that it can be attached to the left/right hubs (Part N°1).
- Right/left hub sub-assembly (Part N°1)

# 4. Control box sub-assembly

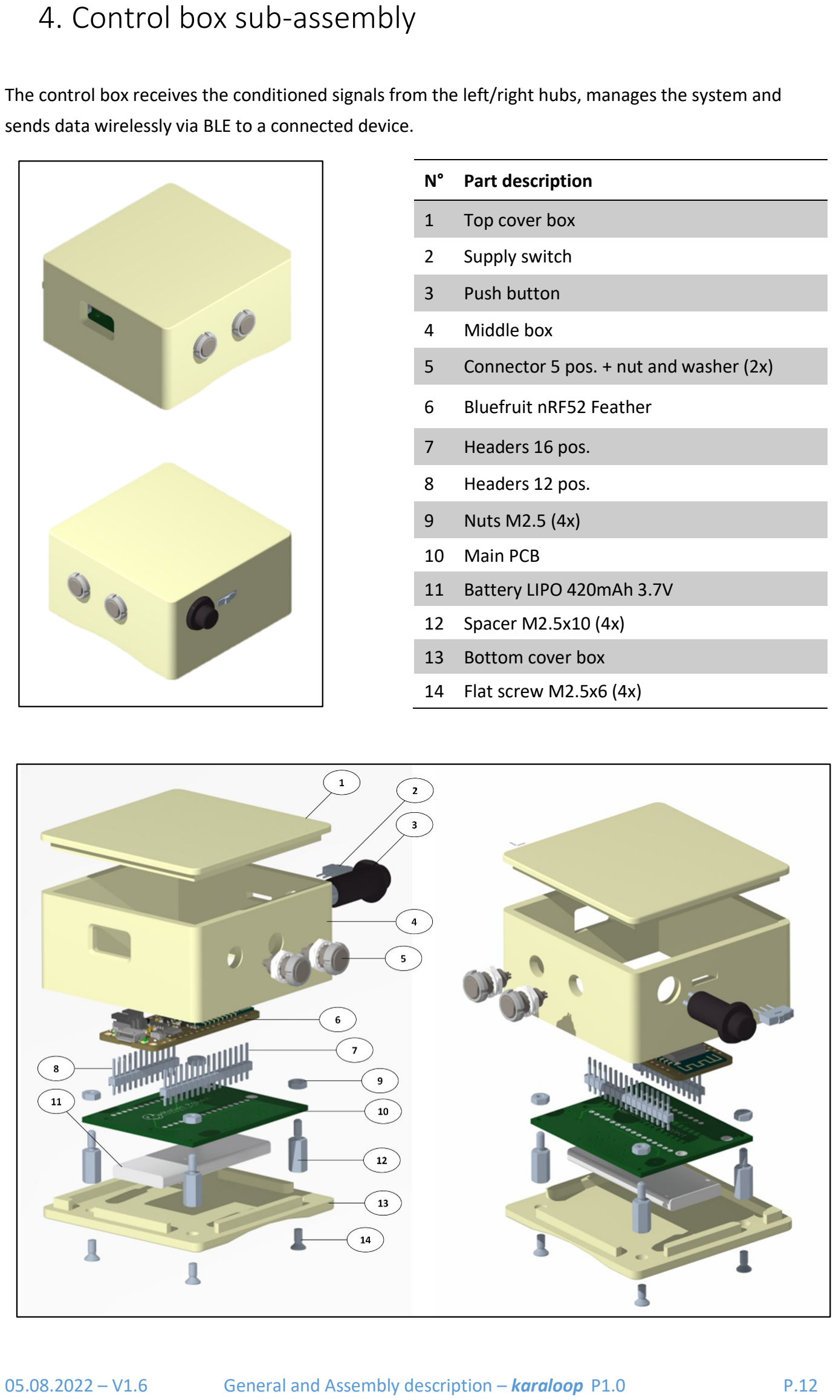
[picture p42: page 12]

05.08.2022 – V1.6 | General and Assembly description – karaloop P1.0 | P.12

The control box receives the conditioned signals from the left/right hubs, manages the system and sends data wirelessly via BLE to a connected device.

N° Part description

1 | Top cover box
2 | Supply switch
3 | Push button
4 | Middle box
5 | Connector 5 pos. + nut and washer (2x)
6 | Bluefruit nRF52 Feather
7 | Headers 16 pos.
8 | Headers 12 pos.
9 | Nuts M2.5 (4x)

10 Main PCB
11 Battery LIPO 420mAh 3.7V 12 Spacer M2.5x10 (4x)
13 Bottom cover box
14 Flat screw M2.5x6 (4x)

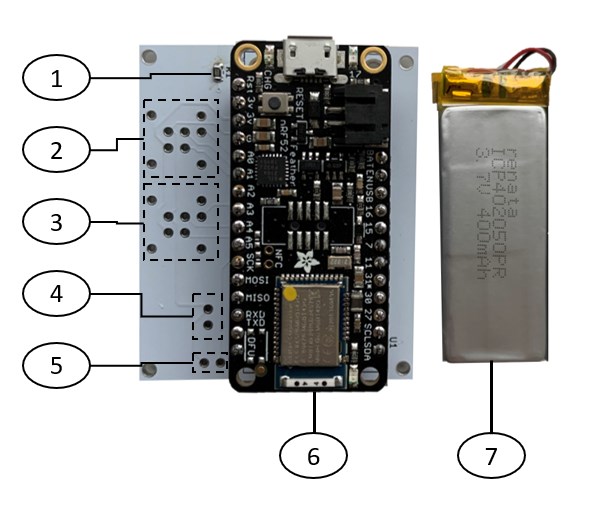
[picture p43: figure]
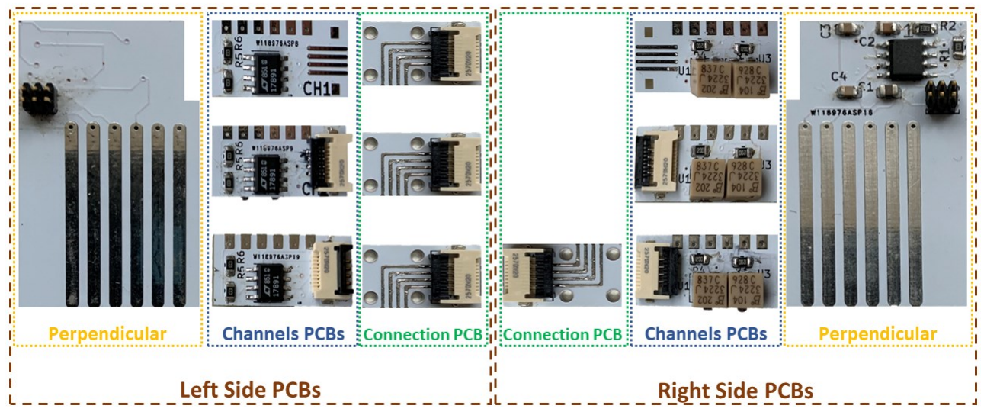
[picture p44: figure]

05.08.2022 – V1.6 | General and Assembly description – karaloop P1.0 | P.13

N° 10: Main PCB

N° | Part description
1 | 10kΩ resistor
2 | Connector pins for right side
3 | Connector pins for left side
4 | Connector pins for battery
5 | Connector pins for push button
6 | Bluefruit nRF52 Feather
7 | Battery LIPO 420mAh 3.7V

# PCBs Overview

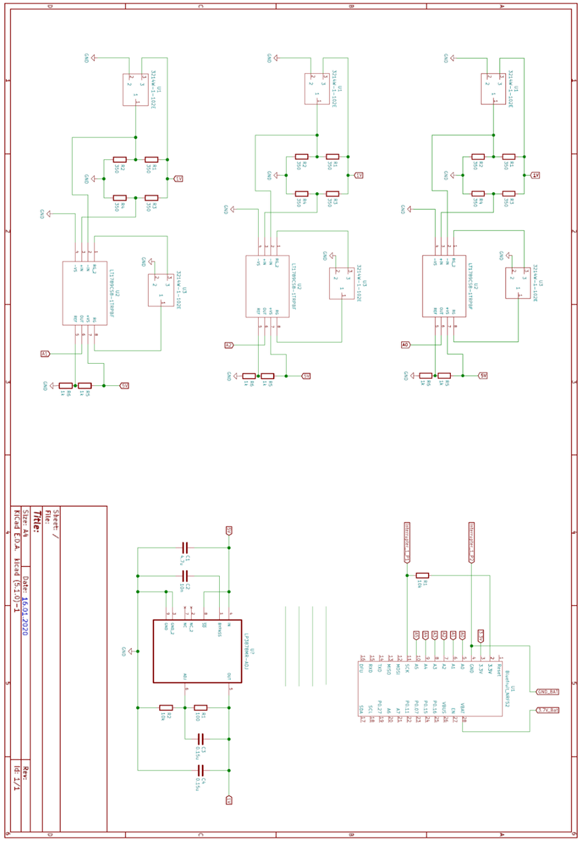
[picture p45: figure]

05.08.2022 – V1.6 | General and Assembly description – karaloop P1.0 | P.14

# Control box circuit schematic

05.08.2022 – V1.6 | General and Assembly description – karaloop P1.0 | P.15

# Electronic parts list (EPL)

N° | Part description | PCB | Quantity | Link
1 | Operational amplifier | PCB channel 1,2 and 3 | 3 | LT1789-1 (https://www.analog.com/media/en/technical-documentation/data-sheets/1789fc.pdf)
2 | Trimmer 2 kΩ 250 mW | PCB channel 1,2 and 3 | 3 | 3224J-1-202E (https://www.distrelec.ch/Web/Downloads/_t/ds/3224-series_eng_tds.pdf?pid=16400642)
3 | Trimmer 100 kΩ 250
| mW | PCB channel 1,2 and 3 | 3 | 3224J-1-104E (https://www.distrelec.ch/Web/Downloads/_t/ds/3224-series_eng_tds.pdf?pid=16400641)
4 | 10 kΩ resistors | PCB channel 1,2 and 3 | 6 | SMD resistors (https://www.distrelec.ch/Web/Downloads/_t/ds/rnd_smd_resistors_eng_tds.pdf?pid=30069020)
5 | 120 Ω resistors | PCB channel 1,2 and 3 | 6 | SMD resistors (https://www.distrelec.ch/Web/Downloads/_t/ds/rnd_smd_resistors_eng_tds.pdf?pid=30069020)
6 | Backlock Connector
| (1.0 pitch, 4 pins, Dual
| Contact) | PCB channel 1,2 and 3+
| | PCB probe connection | 12 | XF3M (https://www.mouser.ch/datasheet/2/307/XF3M_0813-1190174.pdf)
7 | Linear voltage regulator
| 1-5.5 V SOIC-8 | Perpendicular PCB | 1 | LP3878MR-ADJ/NOPB (http://www.ti.com/lit/ds/symlink/lp3878-adj.pdf)
8 | 0.15 µF Capacitors | Perpendicular PCB | 2 | SMD capacitors (https://www.distrelec.ch/Web/Downloads/_t/ds/CER_ENG_KIT_30_eng_tds.pdf?pid=30016803)
9 | 10 nF capacitor | Perpendicular PCB | 1 | SMD capacitor (https://www.distrelec.ch/Web/Downloads/_t/ds/CER_ENG_KIT_30_eng_tds.pdf?pid=30016803)
10 | 4.7 µF capacitor | Perpendicular PCB | 1 | SMD capacitor (https://www.distrelec.ch/Web/Downloads/_t/ds/CER_ENG_KIT_30_eng_tds.pdf?pid=30016803)
11 | 1 kΩ resistor | Perpendicular PCB | 1 | SMD resistors (https://www.distrelec.ch/Web/Downloads/_t/ds/rnd_smd_resistors_eng_tds.pdf?pid=30069020)
12 | 100 kΩ resistor | Perpendicular PCB | 1 | SMD resistors (https://www.distrelec.ch/Web/Downloads/_t/ds/rnd_smd_resistors_eng_tds.pdf?pid=30069020)
13 | Headers 1.27x1.27mm | Perpendicular PCB | 1 | 20021111-00006T4LF (https://www.farnell.com/cad/2562126.pdf)
14 | Wire housings
| 1.27x1.27mm | Perpendicular PCB | 1 | 20021311-00006T4LF (http://www.farnell.com/datasheets/2374175.pdf)
15 | Bluefruit nRF52 Feather | Main PCB | 1 | nRF52 (https://www.adafruit.com/product/3406)
16 | 10 kΩ resistors | Main PCB | 1 | SMD resistors (https://www.distrelec.ch/Web/Downloads/_t/ds/rnd_smd_resistors_eng_tds.pdf?pid=30069020)
17 | Batteries LIPO 420mAh
| 3.7V | Main PCB | 1 | Rechargable battery (https://www.distrelec.ch/Web/Downloads/_t/ds/ICP402050PR_eng_tds.pdf?pid=30158711)
18 | Push button opaque | Main PCB | 1 | Push button (https://www.distrelec.ch/Web/Downloads/he/et/110107_eng_datasheet.pdf?pid=13552218)
19 | Supply switch | Main PCB | 1 | NK236 (https://www.mouser.ch/datasheet/2/26/APPM_S_A0000239063_1-2538228.pdf)

05.08.2022 – V1.6 | General and Assembly description – karaloop P1.0 | P.16

# Mechanical parts list (MPL)

N° | Part description | Assembly | Quantity | Link
1 | Fillister screw M1.6x6 | SP | 24 | M1.6x6 (https://www.tme.eu/mt/en/details/b1.6x6_bn384/bolts/bossard/1945130/)
2 | Flat wire 4 contacts - 30 mm | SP | 4 | 98267-0701 (https://www.mouser.fr/ProductDetail/Molex/98267-0701)
3 | Flat wire 4 contacts - 50 mm | SP | 4 | 686704050001 (https://www.mouser.fr/ProductDetail/Wurth-Elektronik/686704050001)
4 | Flat wire 4 contacts - 76 mm | SP | 2 | 15167-0704 (https://www.mouser.fr/ProductDetail/Molex/15167-0704)
5 | Allen screw M2.5x6 | H | 2 | M2.5x6 (https://www.tme.eu/mt/en/details/b2.5x6_bn11/bolts/bossard/1011871/)
6 | Connector 5 pos. + nut and washer | H + CB | 4 | EGG.00.305.CLL (https://ch.farnell.com/fr-CH/lemo/egg-00-305-cll/connecteur-circulaire-embase-5pos/dp/2442842)
7 | Nuts M2.5 | CB | 4 | Nuts (https://www.tme.eu/mt/en/details/b2.5_bn124/nuts/bossard/m2-5-bn124/)
8 | Spacer M2.5x10 | CB | 4 | Spacer (https://www.tme.eu/mt/en/details/tff-m2.5x10_dr1212/metal-spacers/dremec/1212x10/)
9 | Flat screw M2.5x6 | CB | 4 | M2.5x6 (https://www.tme.eu/mt/en/details/b2.5x6_bn20/bolts/bossard/1480278/)
10 | Kapton sheet of 125 µm thickness | SP | 1 | Kapton (https://www.dupont.com/content/dam/dupont/products-and-services/membranes-and-films/polyimde-films/documents/DEC-Kapton-general-specs.pdf)
11 | Kapton tape of 25 µm thickness | SP | 1 | Kapton tape (https://fr.farnell.com/pro-power/ppc220/ruban-kapton-marron-25mmx33m/dp/2061299)
12 | P400 sandpaper | SP | 1 | A02010 (https://fr.farnell.com/3m/a02010/sheet-230x280mm-p400/dp/1495822?st=papier%20de%20verre%20p400)
13 | Double tape Spandex of 50 µm
| thickness | SP | 1 | Spandex (https://shop.spandex.com/fr_CH/outils-de-masquage-et-accessoires-adhesive-tapes-fasteners-rubans-adhesifs-double-face-rubans-adhesifs-double-face/scotch-8132-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)
14 | Steel wire – 2 mm of diameter | HB | 30 cm | Steel wire (https://www.jumbo.ch/fr/fil-de-fer-galvanise-15597?sku=1344551)
15 | Silicone pipe – 2.5 mm of internal
| diameter and 4 mm of outside
| diameter | HB | 30 cm | Silicone pipe (https://www.amazon.in/SLB-Works-Resistant-Silicone-Rubber/dp/B07G81HRD3)
16 | Strain gauges HBM of 120 Ω | SP | 4 | Strain gauges (https://www.hbm.com/fr/4550/jauges-pre-cablees-rapides-sures-et-pratiques/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)
17 | Substrate’s design | SP | - | Substrate’s design (https://github.com/xmotion-project/karaloop/blob/main/karaloop_P1_0/Hardware/Mechanical%20Design/Sub-assembly/Sensor%20probes/Probe%20substrate.svg)

05.08.2022 – V1.6 | General and Assembly description – karaloop P1.0 | P.17

# Printed parts list (PPL)

Each piece has been printed with ABS or tough PLA

N° | Part description | Assembly | Quantity | Part name
1 | Ball joints | SP | min. 25 | ball_joints.stl (https://github.com/xmotion-project/karaloop/blob/main/karaloop_P1_0/Hardware/Mechanical%20Design/STL/ball_joints.stl)
2 | Protective cover
| probe left | SP | 4 | protective_cover_probe_left.stl (https://github.com/xmotion-project/karaloop/blob/main/karaloop_P1_0/Hardware/Mechanical%20Design/STL/ball_joints.stl)
3 | Protective cover
| probe right | SP | 4 | protective_cover_probe_right.stl
4 | Ball joints left
| (female) | SP | 3 | ball_joints_left.stl (https://github.com/xmotion-project/karaloop/blob/main/karaloop_P1_0/Hardware/Mechanical%20Design/STL/ball_joints_left.stl)
5 | Ball joints right
| (female) | SP | 3 | ball_joints_right.stl (https://github.com/xmotion-project/karaloop/blob/main/karaloop_P1_0/Hardware/Mechanical%20Design/STL/ball_joints_right.stl)
6 | Left hub box | H | 1 | hub_box_left.stl (https://github.com/xmotion-project/karaloop/blob/main/karaloop_P1_0/Hardware/Mechanical%20Design/STL/hub_box_left.stl)
7 | Left hub box cover | H | 1 | hub_cover_box_left.stl (https://github.com/xmotion-project/karaloop/blob/main/karaloop_P1_0/Hardware/Mechanical%20Design/STL/hub_cover_box_left.stl)
8 | Left hub support
| cover | H | 1 | hub_support_cover_left.stl (https://github.com/xmotion-project/karaloop/blob/main/karaloop_P1_0/Hardware/Mechanical%20Design/STL/hub_support_cover_left.stl)
9 | Right hub box | H | 1 | hub_box_right.stl (https://github.com/xmotion-project/karaloop/blob/main/karaloop_P1_0/Hardware/Mechanical%20Design/STL/hub_box_right.stl)
10 | Right hub box
| cover | H | 1 | hub_cover_box_right.stl (https://github.com/xmotion-project/karaloop/blob/main/karaloop_P1_0/Hardware/Mechanical%20Design/STL/hub_cover_box_right.stl)
11 | Right hub support
| cover | H | 1 | hub_support_cover_right.stl (https://github.com/xmotion-project/karaloop/blob/main/karaloop_P1_0/Hardware/Mechanical%20Design/STL/hub_support_cover_right.stl)
12 | Ball joint
| connector (male):
| channel 1 and 2 | H | 2 | ball_joint_connector_12.stl (https://github.com/xmotion-project/karaloop/blob/main/karaloop_P1_0/Hardware/Mechanical%20Design/STL/ball_joint_connector_12.stl)

13

Ball joint
connector (male):
channel 3
| | H | 2 | ball_joint_connector_3.stl (https://github.com/xmotion-project/karaloop/blob/main/karaloop_P1_0/Hardware/Mechanical%20Design/STL/ball_joint_connector_3.stl)
14 | Top cover box | CB | 1 | top_cover_control_box.stl (https://github.com/xmotion-project/karaloop/blob/main/karaloop_P1_0/Hardware/Mechanical%20Design/STL/top_cover_control_box.stl)
15 | Middle box | CB | 1 | middle_control_box.stl (https://github.com/xmotion-project/karaloop/blob/main/karaloop_P1_0/Hardware/Mechanical%20Design/STL/middle_control_box.stl)
16 | Bottom cover box | CB | 1 | bottom_cover_control_box.stl (https://github.com/xmotion-project/karaloop/blob/main/karaloop_P1_0/Hardware/Mechanical%20Design/STL/bottom_cover_control_box.stl)

05.08.2022 – V1.6 | General and Assembly description – karaloop P1.0 | P.18

This work was partially sponsored by Fondation Privée des HUG (https://www.fondationhug.org/) and Wyss Center (https://wysscenter.ch/) through support awarded to Ferran Galán at University of Geneva. (https://www.unige.ch/en/university/presentation/)

Quentin Praz, Ahmad Jaafar, Spiros Schoinas and Philippe Passeraub from HEPIA, (https://www.hesge.ch/hepia/) and Ferran Galán from University of Geneva (https://www.unige.ch/en/university/presentation/) contributed to the conception and development of karaloop P1.0, (https://github.com/xmotion-project/xMotion/wiki/karaloop-P1.0) P2.0 (https://github.com/xmotion-project/xMotion/wiki/karaloop-P2.0) and P3.0. (https://github.com/xmotion-project/xMotion/wiki/karaloop-P3.0)

karaloop P1.0 (https://github.com/xmotion-project/xMotion/wiki/karaloop-P1.0) is OSHWA-certified (https://certification.oshwa.org/) open source hardware [CH00014]. (https://certification.oshwa.org/list.html)

This document is licensed under Creative Commons Attribution 4.0 International (CC BY 4.0). (https://creativecommons.org/licenses/by/4.0/)

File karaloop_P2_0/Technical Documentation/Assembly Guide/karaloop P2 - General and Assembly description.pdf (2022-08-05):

# GENERAL DESCRIPTION

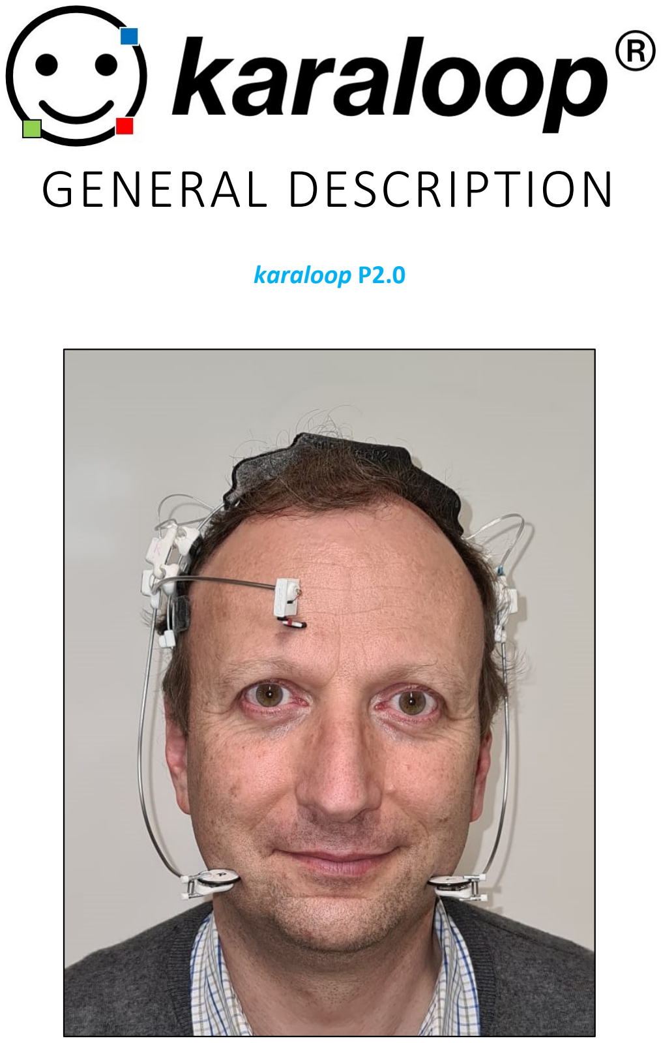
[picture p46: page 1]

# karaloop P2.0

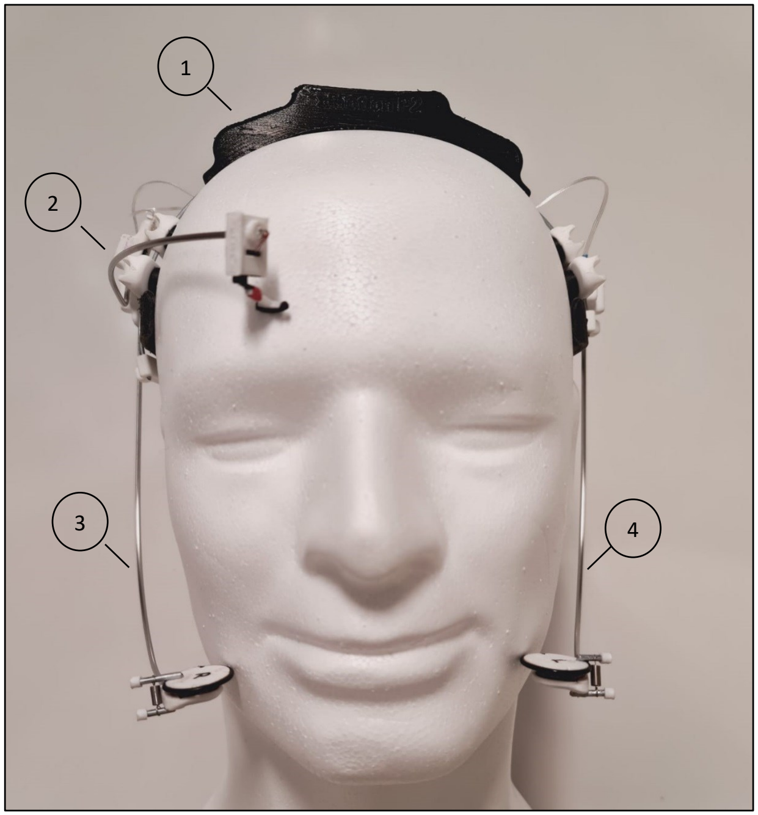
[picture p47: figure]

05.08.2022 – V1.3 | General and Assembly description – karaloop P2.0 | P.2

karaloop – Prototype 2.0 (P2.0)

P2.0 is a light headset that measures voluntary movements of the face and translates them into mouse or keyboard commands sent via Bluetooth Low Energy (BLE) to wirelessly communicate with any PC, iOS or Android device. Unlike P1.0, P2.0 integrates headset and control box in a single unit.
P2.0 incorporates a headset band (1) that houses a rechargeable built-in battery and an Arduino-compatible Bluefruit nRF52 Feather board which is automatically recognized via BLE as a human-interface device (HID) by any PC, iOS or Android device. The headset further integrates three mechanical contact probes (2, 3, 4) that detect voluntary movements of the face; a switch-based probe
(2) that captures forehead movements, and two potentiometric probes (3, 4) that capture orofacial movements bilaterally. Several headset probe holders (5) allow the adjustment of the mechanical contact probes (2, 3, 4) to fit different face contours. P2.0’s modular design further facilitates the easy replacement of probes and the rapid testing of new probe designs.

5

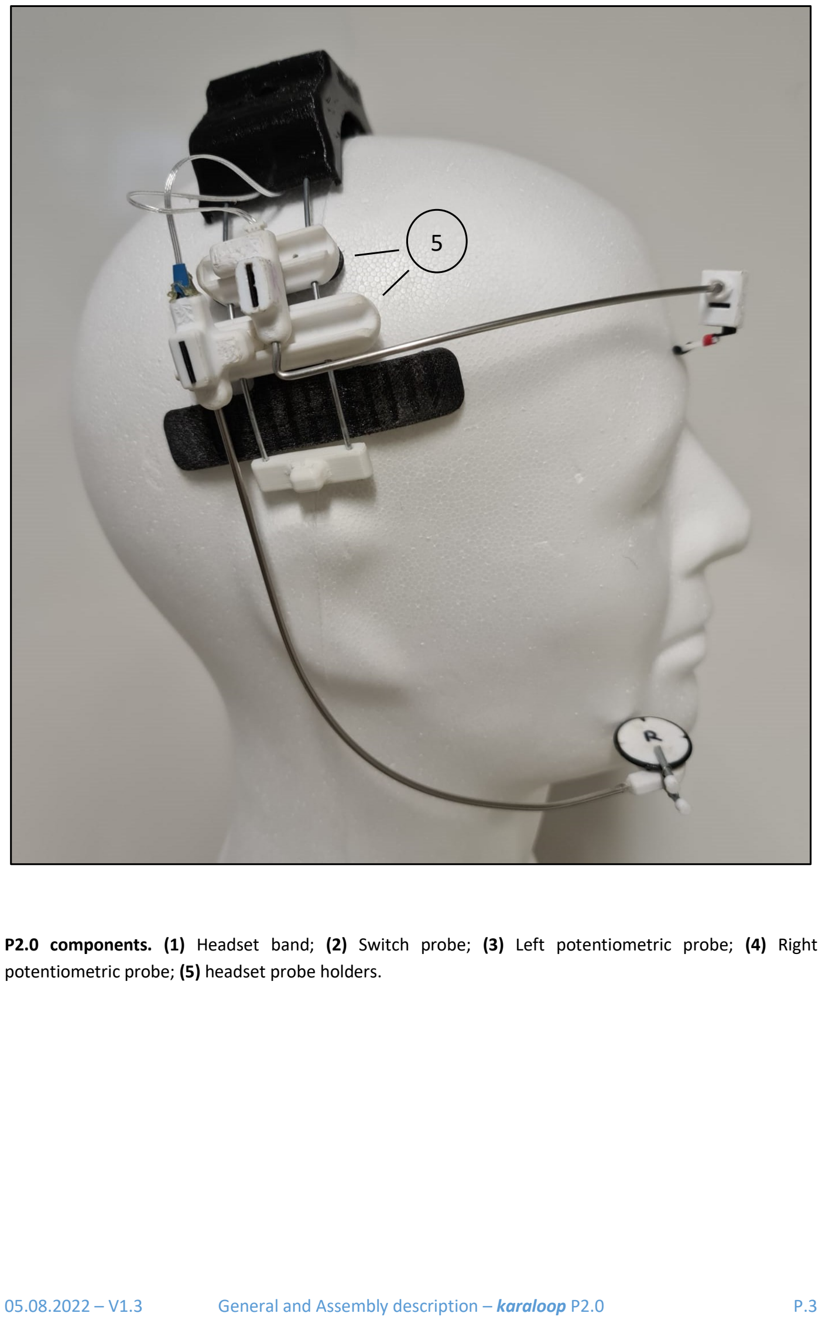
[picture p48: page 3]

05.08.2022 – V1.3 | General and Assembly description – karaloop P2.0 | P.3

P2.0 components. (1) Headset band; (2) Switch probe; (3) Left potentiometric probe; (4) Right potentiometric probe; (5) headset probe holders.

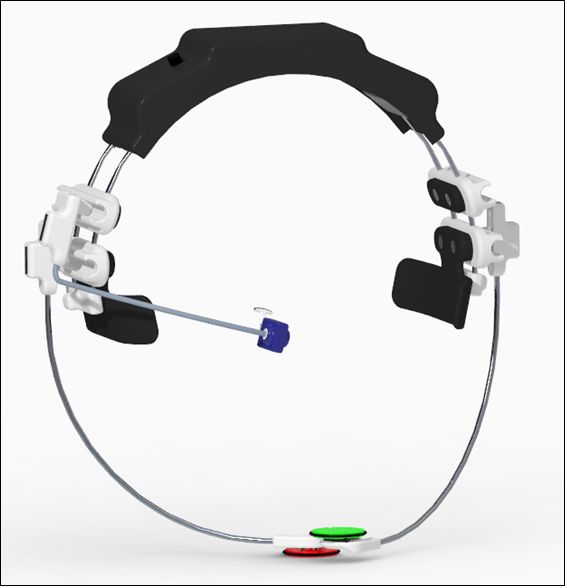
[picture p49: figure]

05.08.2022 – V1.3 | General and Assembly description – karaloop P2.0 | P.4

# ASSEMBLY DESCRIPTION

# karaloop P2.0

05.08.2022 – V1.3 | General and Assembly description – karaloop P2.0 | P.5

# CONTENTS

# General assembly

1

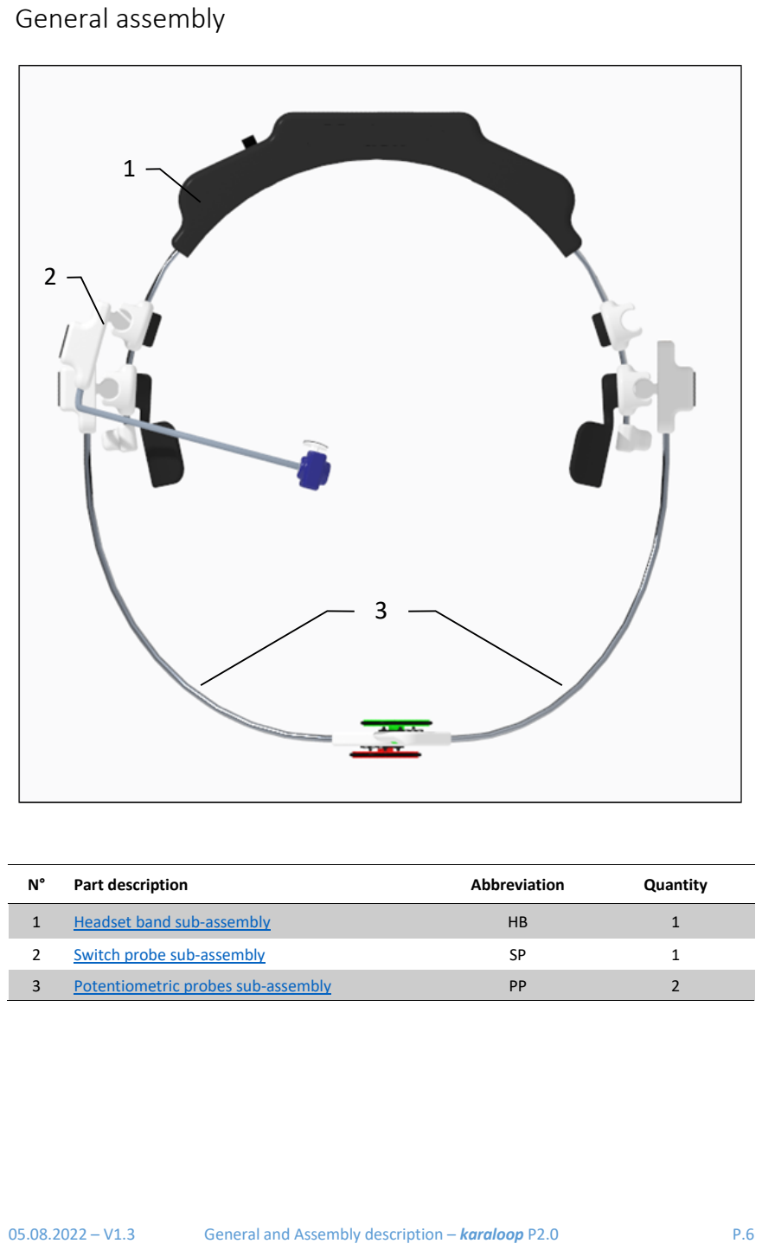
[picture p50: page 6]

05.08.2022 – V1.3 | General and Assembly description – karaloop P2.0 | P.6
N° | Part description | Abbreviation | Quantity
1 | Headset band sub-assembly | HB | 1
2 | Switch probe sub-assembly | SP | 1
3 | Potentiometric probes sub-assembly | PP | 2

2

3

# 1. Headset band sub-assembly

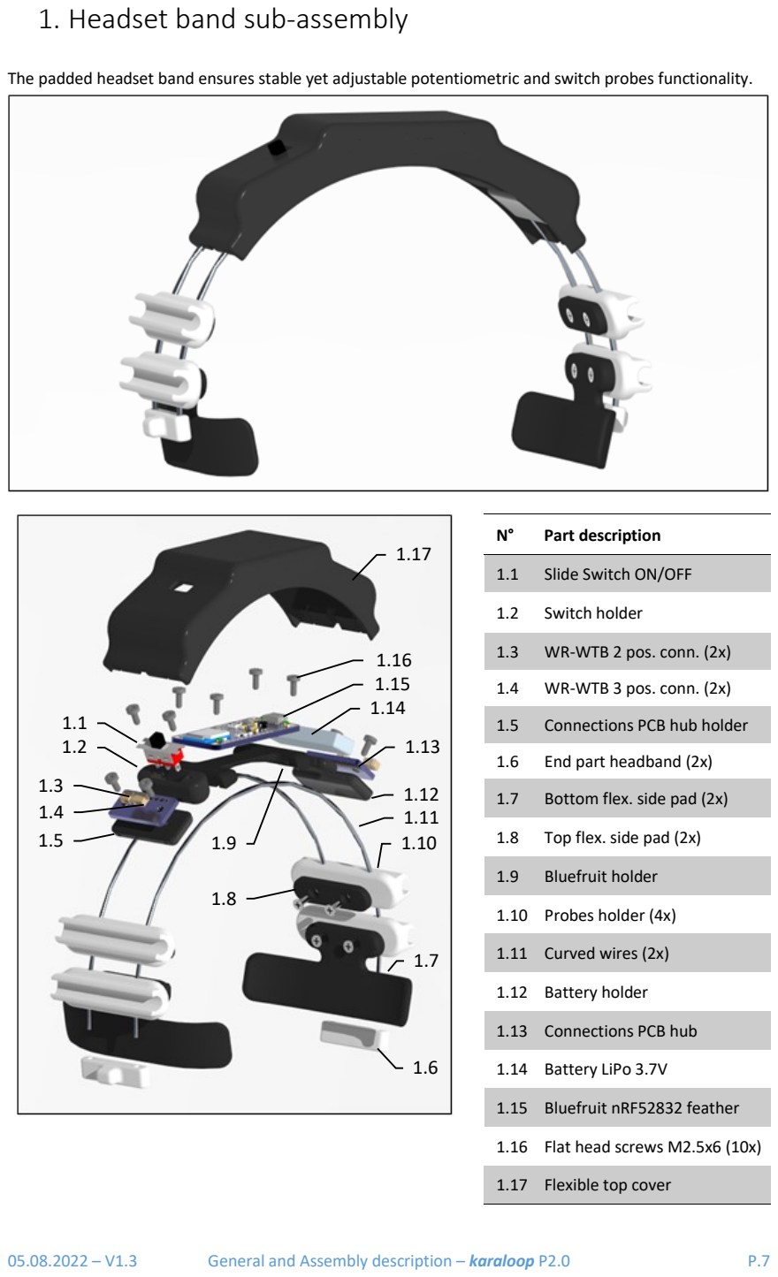
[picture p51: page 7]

05.08.2022 – V1.3 | General and Assembly description – karaloop P2.0 | P.7

The padded headset band ensures stable yet adjustable potentiometric and switch probes functionality.

N° | Part description
1.1 | Slide Switch ON/OFF
1.2 | Switch holder
1.3 | WR-WTB 2 pos. conn. (2x)
1.4 | WR-WTB 3 pos. conn. (2x)
1.5 | Connections PCB hub holder
1.6 | End part headband (2x)
1.7 | Bottom flex. side pad (2x)
1.8 | Top flex. side pad (2x)
1.9 | Bluefruit holder

1.10 Probes holder (4x)

1.11 Curved wires (2x)

1.12 Battery holder

1.13 Connections PCB hub

1.14 Battery LiPo 3.7V

1.15 Bluefruit nRF52832 feather

1.16 Flat head screws M2.5x6 (10x)

1.17 Flexible top cover

1.17

1.16
1.15

1.1
1.13

1.10

1.14

1.7

1.6

1.3
1.4
1.5

1.12

1.2

1.8

1.9

1.11

05.08.2022 – V1.3 | General and Assembly description – karaloop P2.0 | P.8

## FABRICATION PROCESS

MATERIALS NEEDED can be found in Electronical part list (EPL, page 15), Mechanical Part List (MPL, page 17) and Printed Parts List (PPL, page 18).

Step | Description | Materials needed

### 1.1 Curved wires (Part N°1.11)

| Bend two wires as illustrated with a bending radius of 80 mm and cut them to an angle of 140°. | • Wires of Ø1.6 mm (MPL N°2) • Pattern for each curved wire:

### 1.2 Connections PCB Hub (Parts N°1.3, 1.4, 1.13)

1. Shorten (2x) the Connections PCB hub (Part N°1.13) to a length of 30 mm.
2. Solder (2x) the two connectors (Parts N°1.3, 1.4) to the Connections PCB hub (Part N°1.13) following the Connections PCB
3. hub pinout on the right.
- WR-WTB 2 pos. conn (EPL N°8)
- WR-WTB 3 pos. conn (EPL N°5)
- Connections PCB hub (EPL N°4)
- Connections PCB hub pinout:

1.3 Headset band assembly (Parts N°1.1, 1.2, 1.5, 1.6, 1.7, 1.8, 1.9, 1.10, 1.12, 1.15, 1.16 – Step N°1.1, 1.2)
1. Slide the Bluefruit holder (Part N°1.9), the switch holder (Part N°1.2) and the battery holder (Part N°1.12) through the two curved wires (Part N°1.11; Step N°1.1).
2. Slide the two PCB conn. holders (Part N°1.5; 1x side), the four probe holders (Part N°1.10; 2x side) and the two-end parts headband (Part N°1.6; 1x side) through the two curved wires.
3. Screw with flat head screws (Part N°1.16):
- the connections PCB hubs (Part N°1.13; Step N°1.2; 1x side) to the PCB conn. holders (Part N°1.5; 1x side).
- the slide switch (Part N°1.1) to the switch holder (Part N°1.2).
- the Bluefruit nRF52832 feather (Part N°1.15) to the bluefruit holder (Part N°1.9).
- the top flex. side pads (Part N°1.8; 1x side) to the top probe holders (Part N°1.10; 1x side).
- bottom flex. side pad (Part N°1.7; 1x side) to the bottom probes holders (Part N°1.10; 1x side).
4. Attach the LiPo battery 3.7V (Part N°1.14) to the battery holder (Part N°1.12) with double tape.
- Bluefruit holder (PPL N°7)
- Switch holder (PPL N°3)
- Battery holder (PPL N°9)
- PCB conn. holder (PPL N°4)
- Probe holder (PPL N°8)
- Top flex. side pad (PPL N°6)
- Bottom flex. side pad (PPL N°5)
- End part headband (PPL N°2)
- Bluefruit nRF52832 feather (EPL N°1)
- Slide Switch ON/OFF (EPL N°3)
- Battery LiPo 3.7V (EPL N°2)
- Flat head screws M2.5x6 (MPL N°1)
- Connections PCB hub (EPL N°4)
- Double tape

30 mm

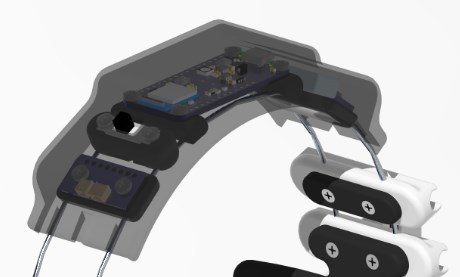
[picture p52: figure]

05.08.2022 – V1.3 | General and Assembly description – karaloop P2.0 | P.9

### 1.4 Electrical wiring (Parts N°1.1, 1.13, 1.14, 1.15 – Step

N°1.2)
Connect the slide switch (Part N°1.1), the Connections PCB hubs (Part N°1.13; Step N°1.2), and the battery (Part N°1.14) with the Bluefruit nRF52832 feather (Part N°1.15) following the electrical schematic (Pag. 16).

Use electrical wires within the range of 16 to 28 AWG.

- Bluefruit nRF52832 feather (EPL N°1)
- Slide Switch ON/OFF (EPL N°3)
- Battery LiPo 3.7V (EPL N°2)
- Connections PCB hub (EPL N°4)
- Electrical wires (from 16 to 28 AWG)

### 1.5 Top cover assembly (Parts N°1.17)

Cover everything up attaching the flexible top cover (Part N°1.17) to the curved wires (Part N°1.11).

- Flexible top cover (PPL N°1)

# 2. Switch probe sub-assembly

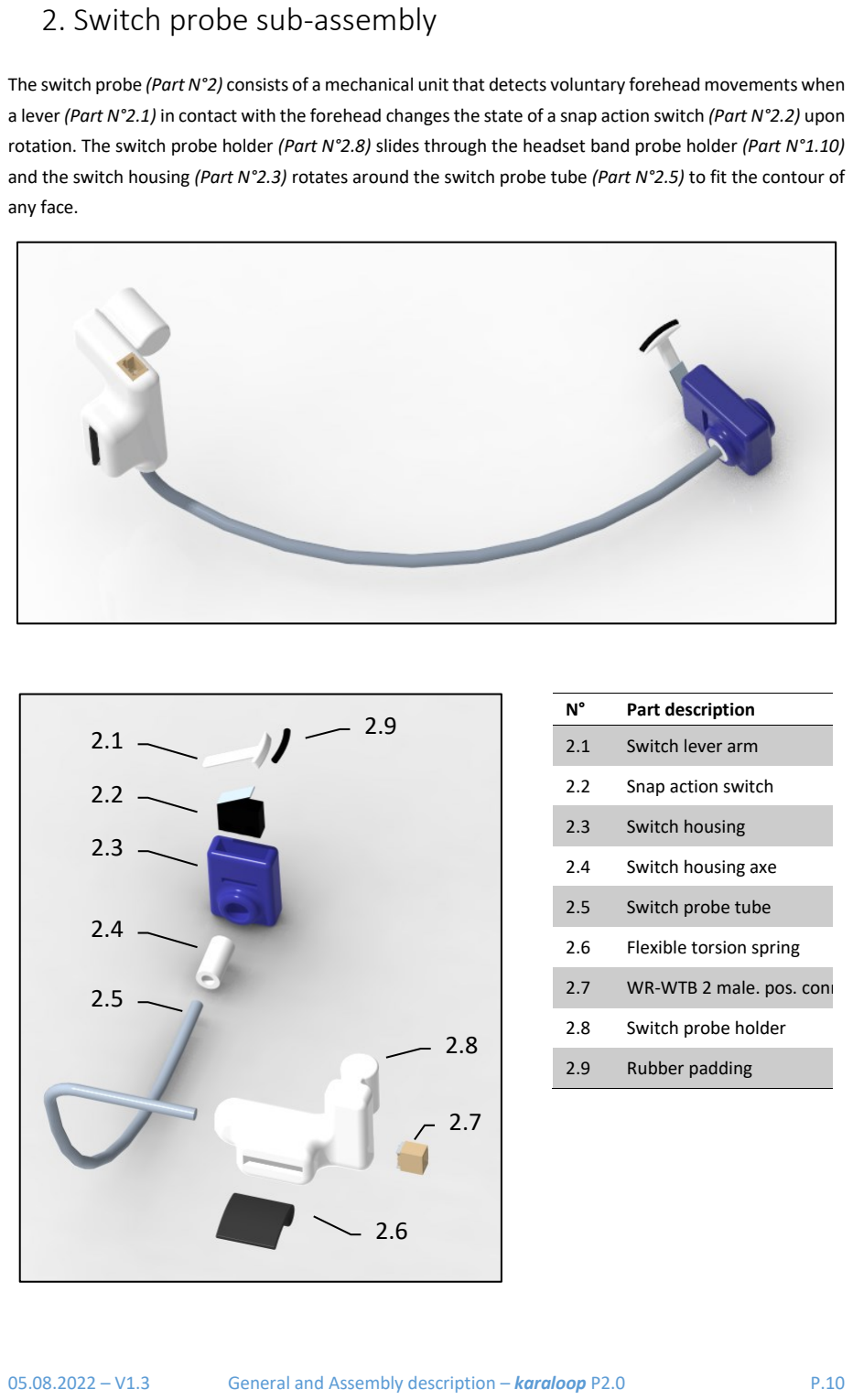
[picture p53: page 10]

05.08.2022 – V1.3 | General and Assembly description – karaloop P2.0 | P.10

The switch probe (Part N°2) consists of a mechanical unit that detects voluntary forehead movements when a lever (Part N°2.1) in contact with the forehead changesthe state of a snap action switch (Part N°2.2) upon rotation. The switch probe holder (Part N°2.8) slides through the headset band probe holder (Part N°1.10) and the switch housing (Part N°2.3) rotates around the switch probe tube (Part N°2.5) to fit the contour of any face.

N° | Part description
2.1 | Switch lever arm
2.2 | Snap action switch
2.3 | Switch housing
2.4 | Switch housing axe
2.5 | Switch probe tube
2.6 | Flexible torsion spring
2.7 | WR-WTB 2 male. pos. conn
2.8 | Switch probe holder
2.9 | Rubber padding

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
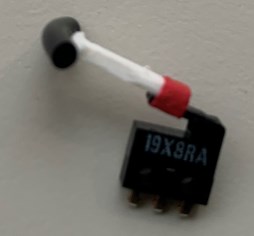
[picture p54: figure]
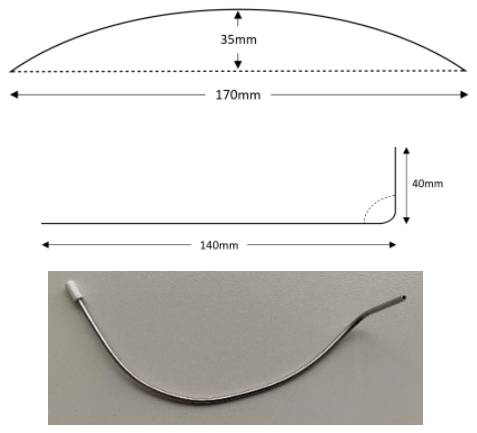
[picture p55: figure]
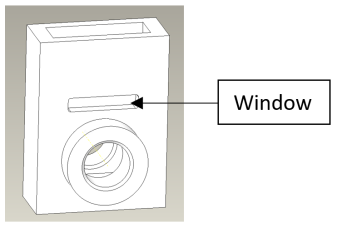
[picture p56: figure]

05.08.2022 – V1.3 | General and Assembly description – karaloop P2.0 | P.11

## FABRICATION PROCESS

MATERIALS NEEDED can be found in Electronical part list (EPL, page 15), Mechanical Part List (MPL, page 17) and Printed Parts List (PPL, page 18).

Step | Description | Materials needed

### 2.1 Switch assembly (Parts N°2.1, 2.2, 2.9)

1. Cut an 8mm piece of Ø 20 mm rubber (Part
| N°2.9) for padding the lever arm (Part N°2.1).
2. Glue the rubber padding (Part N°2.9) onto the
| switch lever arm (Part N°2.1) as indicated in the figure on the right.
3. Let the glue dry before continuing.
4. Glue the Switch lever arm (Part N°2.1) onto the
| metallic lever of the switch (Part N°2.2).
5. Let the glue dry before continuing.
6. Further secure the switch lever arm (Part
| N°2.1) onto the metallic lever of the switch (Part N°2.2) with tape as illustrated in the figure on the right (in red).
- Rubber O-ring of Ø 20 mm (MPL N°4)
- Snap action switch (EPL N°10)
- Metal glue: CYANOACRYLATE INSTANT ADHESIVES such as Ergo®5011 or Ergo®5901.
- Tape

### 2.2 Metal conduit (Parts N°2.4, 2.5)

1. Cut a 170mm piece long of the Inox tube (Part N°2.5).
2. Bend the tube in a plane as illustrated in the top figure on the right.
3. Bend the tube a second time in a plane perpendicular to the curved tube as illustrated in the mid/bottom figures on the right.
4. Insert the cut tube (Part N°2.5) into the switch housing tube (Part N°2.4) as indicated in the bottom figure on the right.
5. Secure the assembly applying metal glue at around the contours interfacing the tube (Part N°2.5) with the switch housing tube (Part N°2.4).
6. Let the glue dry before continuing.
- Switch probe tube (MPL N°3)
- Switch housing tube (PPL N°12)
- Metal glue: CYANOACRYLATE INSTANT ADHESIVES such as Ergo®5011 or Ergo®5901

### 2.3 Switch housing assembly (Parts N°2.3, 2.4, Step

N°2.2)
1. Route two 180mm long insulated wires through the metal conduit (Step N°2).
2. Insert the switch housing tube (Part N°2.4) of the metal conduit (Step N°2.2) and the wires (Step N°2.3.1) into the switch housing (Part N°2.3).
3. Route in the wires through the window above the cylindrical opening of the switch housing (Part N°2.3) as indicated in the figure on the right.
- Insulated wire of 30 AWG (EPL N°12)
- Switch housing (PPL N°11)

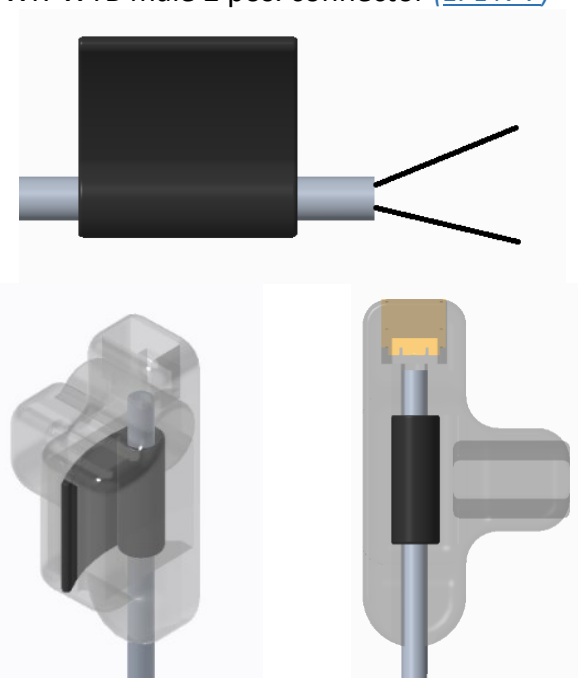
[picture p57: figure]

05.08.2022 – V1.3 | General and Assembly description – karaloop P2.0 | P.12

2.4 Switch probe holder assembly (Parts N°2.6, 2.7, 2.8)
1. Route the wires coming out from the other end of the Metal conduit through the Flexible torsion spring (Part N°2.6).
2. Insert the WR-WTB 2 male pos. connector (Part N°2.7), the Flexible torsion spring (Part N°2.6) and the switch housing assembly from Step N°2.3 into the switch probe holder part (Part N°2.8).
3. Solder the wires coming out from the metal conduit (Part N°2.5) into the WR-WTB 2 male pos. connector (Part N°2.7) following the wiring schematic (P. 15).
- Switch probe holder (PPL N°13)
- Flexible torsion spring (PPL N°14)
- WR-WTB male 2 pos. connector (EPL N°7)

### 2.5 Electrical wiring (Parts N°2.2, 2.3, 2.5, 2.7)

1. Solder the two wires routed through the window of the switch housing (Part N°2.3), from the Step N°2.3, with the pins of the switch (Part N°2.2) following the wiring schematic (P. 15).
2. Insert the switch (Part N°2.2) into the switch housing (Part N°2.3).
3. Solder the two wires coming out from the Headset band side of the Inox tube (Part N°2.5) with the with the WR-WTB 2 male 2 pos. connector (Part N°2.7) following the wiring schematic (P. 15).
- Snap action switch (EPL N°10)
- WR-WTB male 2 pos. connector (EPL N°7)
- Switch housing (PPL N°11)

### 2.6 Switch probe cable

1. Make a 3-contacts cable of 50 mm length from the 6-contacts flat cable.
2. Use a crimper tool to crimp female terminals in all contacts (3x crimped terminals in each end of the cable).
3. Insert the crimped contacts into a WR-WTB female 3 pos. connector (1x connector in each end of the cable).
- WR-WTB female 2 pos. connector (EPL N°7)
- 6-contacts flat cable (EPL N°13)
- Female crimp terminal (EPL N°11)
- Crimper for 28 to 32 AWG wires (tools)

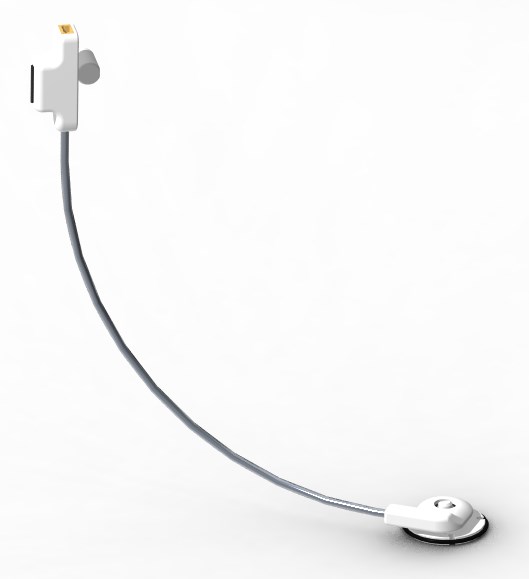
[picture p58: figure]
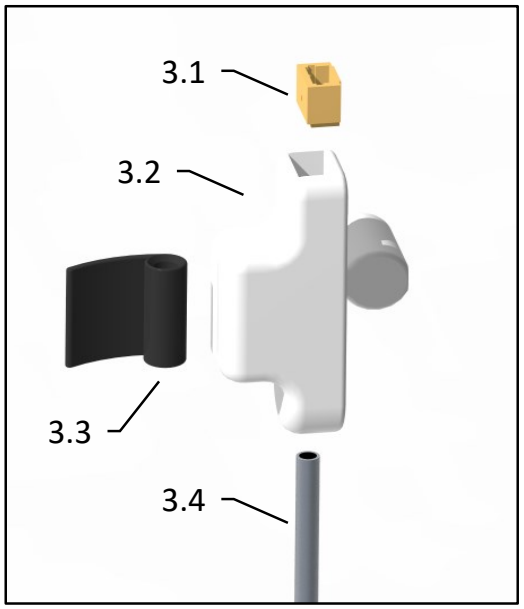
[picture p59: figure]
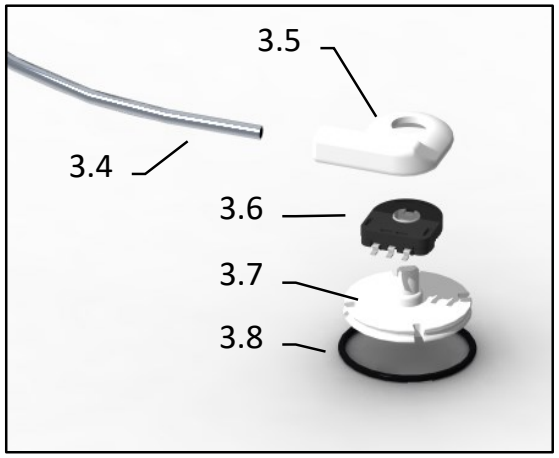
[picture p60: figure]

05.08.2022 – V1.3 | General and Assembly description – karaloop P2.0 | P.13

# 3. Potentiometric probe sub-assembly

Both potentiometric probes (Part N°3) consist of a mechanical unit that translates orofacial movements into a rotating wheel (mobile unit), and a potentiometer (Part N°3.6) sensing unit that measures the voltage corresponding to the wheel rotation. The probes slide through the headset band probe holders (Part N°1.10) to fit the contour of any face.

N° | Part description
3.1 | WR-WTB 3 pos. conn.
3.2 | Potentiometric probe holder
3.3 | Flexible torsion spring
3.4 | Potentiometric probe tube
3.5 | Potentiometer holder
3.6 | Flat shaftless potentiometer
3.7 | Potentiometric wheel
3.8 | Rubber O-ring

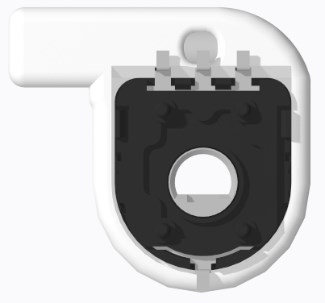
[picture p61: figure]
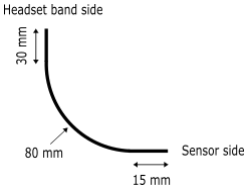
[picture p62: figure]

05.08.2022 – V1.3 | General and Assembly description – karaloop P2.0 | P.14

## FABRICATION PROCESS

Both (left/right) potentiometric probes share the same process except step 3.5 which involve different (left/right) potentiometric probe holder (Part N°3.2).

MATERIALS NEEDED can be found in Electronical part list (EPL, page 15), Mechanical Part List (MPL, page 17) and Printed Parts List (PPL, page 18).

Step | Description | Materials needed

### 3.1 Electrical wiring (Part N°3.6)

| Cut 3x 200 mm length insulated wires of 30 AWG and connect them to each pin of the flat shaftless potentiometer (Part N°3.6) | • Insulated wire of 30 AWG (EPL N°12) • Flat shaftless potentiometer (EPL

N°9)

3.2 Potentiometer housing assembly (Part N°3.5, 3.6, 3.7, 3.8)
1. Insert the flat shaftless potentiometer (Part N°3.6) into the potentiometer holder (Part N°3.5).
2. Insert the shaft of the potentiometric wheel (Part N°3.7) into the flat shaftless potentiometer (Part N°3.6).
3. Cover the potentiometric wheel (Part N°3.7) contour with the rubber O-ring (Part N°3.8).
- Flat shaftless potentiometer (EPL N°9)
- Potentiometric wheel (PPL N°17)
- Potentiometer holder (PPL N°16)
- Rubber O’ring (MPL N°4)

### 3.3 Potentiometric probe tube (Part N°3.4)

1. Shape the potentiometric probe tube (Part N°3.4, 2x) as illustrated in the pattern on the right using an inox tube of Ø2x1.5 mm.
2. Deburr and polish the ends of the tube with a hand-held milling machine.
- Inox tube of Ø2x1.5 mm (MPL N°3)
- Hand-held milling machine
- Pattern for the potentiometric probe tube:

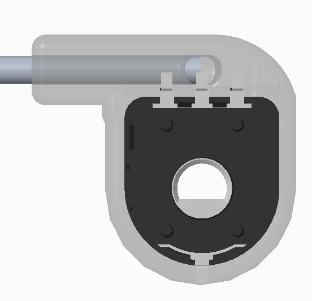
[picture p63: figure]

05.08.2022 – V1.3 | General and Assembly description – karaloop P2.0 | P.15

### 3.4 Potentiometric probe assembly – Sensor side (Part N°3.5

– Steps N°3.1, 3.3)
1. Route the potentiometer wires (Step N°3.1) inside the potentiometric probes tube (Step N°3.3) from the sensor to the headset band side.
2. Apply metal glue on the sensor side of the potentiometric probe tube (Step N°3.3) and insert the tube into the potentiometer holder (Part N°3.5).
3. Let the glue dry for 2 hours before continuing.
- Metal glue: CYANOACRYLATE INSTANT ADHESIVES such as
Ergo®5011 or Ergo®5901

### 3.5 Potentiometric probe assembly – Headset band side

(Parts N°3.1, 3.2, 3.3 – Step N°3.4)
1. Route the wires coming out from the other end of the potentiometric probe tube (Part N°3.4) through the Flexible torsion spring (Part N°3.3).
2. Insert the WR-WTB male connector (Part N°3.1), the flexible torsion spring (Part N°3.3) and the potentiometric probe assembly from Step N°3.4 into the Potentiometric probe holder (Part N°3.2).
3. Solder the wires coming out from the potentiometric probe tube (Part N°3.4) into the WR-WTB 3 male pos. connector (Part N°3.1) following the wiring schematic
(P. 15).
- Flexible torsion spring (PPL N°14)
- WR-WTB male connector (EPL N°5)
- Potentiometric probe holder (PPL N°15)

### 3.6 Electrical wiring (Part N°3.1, 3.4 – Step N°3.5)

Connect the 3 wires coming out from the headset band side of the potentiometric probe tube (Part N°3.4; Step N°3.5) with the WR-WTB male connector (Part N°3.1) following the electrical schematic (Pag. 16).

- WR-WTB male 3 pos. connector (EPL N°5)

### 3.7 Potentiometric probe cable

1. Make a 3-contacts cable of 50 mm length from the 6-contacts flat cable.
2. Use a crimper tool to crimp female terminals in all contacts (3x crimped terminals in each end of the cable).
3. Insert the crimped contacts into a WR-WTB female 3 pos. connector (1x connector in each end of the cable).
- WR-WTB female 3 pos. connector (EPL N°6)
- 6-contacts flat cable (EPL N°13)
- Female crimp terminal (EPL N°11)
- Crimper for 28 to 32 AWG wires (tools)


05.08.2022 – V1.3 | General and Assembly description – karaloop P2.0 | P.16

# Electronic parts list (EPL)

N° | Part description | Quantity | Datasheet | Supplier Link
1 | Bluefruit nRF52 feather | 1 | | Nrf52 (https://www.adafruit.com/product/3406)
2 | Rechargeable battery Li-Po 3.7V
| 350mAh | 1 | | ICP602823PA (https://www.distrelec.ch/fr/batterie-accumulateurs-rechargeable-li-po-7v-350mah-renata-icp602823pa-01/p/30158722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)
3 | Slide Switch ON/OFF | 1 | | RND 210-00581 (https://www.distrelec.ch/en/miniature-slide-switch-1co-on-on-soldering-lugs-rnd-components-rnd-210-00581/p/30152605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)
4 | Connections PCB hub | 2 | | Adafruit FPC Stick (https://www.adafruit.com/product/1325)
5 | WR-WTB male 3 pos. connector | 2 | | 665303124022 (https://www.mouser.fr/ProductDetail/Wurth-Elektronik/665303124022?qs=a9WhcLg8qCyV5ri9HU4hCQ%3D%3D)
6 | WR-WTB female 3 pos. connector | 2 | | 665003113322 (https://www.mouser.fr/ProductDetail/?qs=a9WhcLg8qCx0Aj2fgOQ3BQ%3D%3D)
7 | WR-WTB female 2 pos. connector | 2 | | 665002113322 (https://www.mouser.fr/ProductDetail/?qs=a9WhcLg8qCy4BTanb8zFpg%3D%3D)
8 | WR-WTB male 2 pos. connector | 2 | | 665302124022 (https://www.mouser.fr/ProductDetail/Wurth-Elektronik/665302124022?qs=a9WhcLg8qCx0IT99cXBqTA==)
9 | Flat shaftless potentiometer | 2 | | RDC503052A (https://www.mouser.fr/ProductDetail/Alps-Alpine/RDC503052A?qs=j%252B1pi9TdxUaVD4zRKg%252Bh9Q%3D%3D)
10 | Snap action switches | 2 | | D2MQ-4L-105-1 (https://www.mouser.fr/ProductDetail/Omron-Electronics/D2MQ-4L-105-1)
11 | Female crimp terminal | 50 | | 66510113722 (https://www.mouser.fr/ProductDetail/?qs=a9WhcLg8qCzz4scZZBnxZw%3D%3D)
12 | Insulated wire of 30 AWG | 2 m | | 5851 BK005 (https://www.alphawire.com/en/OnlineTools/~/media/Files/MasterCatalog2011/HookUpWire.pdf)
13 | 6-contacts flat cable | 30 mm | | HF625/06-30 (https://www.mouser.fr/ProductDetail/3M-Electronic-Solutions-Division/HF625-06-30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)
- Remark : The red dotted rectangle illustrates a second switch which could be added to capture voluntary forehead movements from the other side of the face.


05.08.2022 – V1.3 | General and Assembly description – karaloop P2.0 | P.17

# General circuit schematic

05.08.2022 – V1.3 | General and Assembly description – karaloop P2.0 | P.18

# Mechanical parts list (MPL)

ASSEMBLY: Headset band (HB), Switch probe (SP), Potentiometric probe (PP)

N° | Part description | Assembly | Quantity | Link
1 | Flat head screw M2.5x6 | HB | 10 | [M2.5x6] (https://www.bossard.com/eshop/fr-fr/vis-s-a-entrainement-interieur/vis-a-tete-cylindrique-a-six-pans-creux-entierement-filetees/p/3/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)
2 | Wire of Ø1.6 mm | HB | 1 (m) | [Wire] (https://www.durovis.ch/index.php/fr/shop-ressorts-normalises/fil-ressort-standard-disponible.html)
3 | Inox tube of Ø2x1.5 mm | SP, PP | 1 (m) | [Tube] (https://www.interalloy.ch/fr/produkte/lagerliste.php)
4 | Rubber O-ring of Ø 20 mm | SP, PP | 3 | [Oring] (https://www.conrad.fr/p/basetech-bt-1697192-50-pcs-assortiment-de-joints-toriques-5-20-mm-contenu-1-pcs-1697192)

05.08.2022 – V1.3 | General and Assembly description – karaloop P2.0 | P.19

# Printed parts list (PPL)

ASSEMBLY: Headset band (HB), Switch probe (SP), Potentiometric probe (PP)

N° | Part description Assembly Quantity Part name | Printing material

1

Flexible top
cover
| | HB | 1 | flexible_top_cover.stl (https://github.com/xmotion-project/karaloop/blob/main/karaloop_P2_0/Hardware/Mechanical%20Design/Sub-assembly/Headset%20band/STL/flexible_top_cover.stl) | TPU
2 | End part
| headband | HB | 2 | end_part_headband.stl (https://github.com/xmotion-project/karaloop/blob/main/karaloop_P2_0/Hardware/Mechanical%20Design/Sub-assembly/Headset%20band/STL/end_part_headband.stl) | Tough PLA or ABS
3 | Switch holder | HB | 1 | switch_holder.stl (https://github.com/xmotion-project/karaloop/blob/main/karaloop_P2_0/Hardware/Mechanical%20Design/Sub-assembly/Headset%20band/STL/switch_holder.stl) | TPU
4 | PCB conn.
| holder | HB | 2 | PCB_conn_holder.stl (https://github.com/xmotion-project/karaloop/blob/main/karaloop_P2_0/Hardware/Mechanical%20Design/Sub-assembly/Headset%20band/STL/pcb_conn_holder.stl) | TPU
5 | Bottom flex.
| side pad | HB | 2 | bottom_flex_side_pad.stl (https://github.com/xmotion-project/karaloop/blob/main/karaloop_P2_0/Hardware/Mechanical%20Design/Sub-assembly/Headset%20band/STL/bottom_flex_side_pad.stl) | TPU
6 | Top flex. side
| pad | HB | 2 | top_flex_side_pad.stl (https://github.com/xmotion-project/karaloop/blob/main/karaloop_P2_0/Hardware/Mechanical%20Design/Sub-assembly/Headset%20band/STL/top_flex_side_pad.stl) | TPU
7 | Bluefruit holder | HB | 1 | bluefruit_holder.stl (https://github.com/xmotion-project/karaloop/blob/main/karaloop_P2_0/Hardware/Mechanical%20Design/Sub-assembly/Headset%20band/STL/bluefruit_holder.stl) | TPU
8 | Probes’ holder | HB | 3 | probe_holder.stl (https://github.com/xmotion-project/karaloop/blob/main/karaloop_P2_0/Hardware/Mechanical%20Design/Sub-assembly/Headset%20band/STL/proble_holder.stl) | Tough PLA or ABS
9 | Battery holder | HB | 1 | battery_holder.stl (https://github.com/xmotion-project/karaloop/blob/main/karaloop_P2_0/Hardware/Mechanical%20Design/Sub-assembly/Headset%20band/STL/battery_holder.stl) | TPU
10 | Switch lever
| arm | SP | 1 | switch_lever_arm.stl (https://github.com/xmotion-project/karaloop/blob/main/karaloop_P2_0/Hardware/Mechanical%20Design/Sub-assembly/Switch%20probe/STL/switch_lever_arm.stl) | Tough PLA or ABS
11 | Switch housing | SP | 1 | switch_housing.stl (https://github.com/xmotion-project/karaloop/blob/main/karaloop_P2_0/Hardware/Mechanical%20Design/Sub-assembly/Switch%20probe/STL/switch_housing.stl) | Tough PLA or ABS
12 | Switch housing
| axe | SP | 1 | switch_housing_axe.stl (https://github.com/xmotion-project/karaloop/blob/main/karaloop_P2_0/Hardware/Mechanical%20Design/Sub-assembly/Switch%20probe/STL/switch_housing_axe.stl) | Tough PLA or ABS
13 | Switch probe
| holder | SP | 1 | switch_probe_holder.stl (https://github.com/xmotion-project/karaloop/blob/main/karaloop_P2_0/Hardware/Mechanical%20Design/Sub-assembly/Switch%20probe/STL/switch_probe_holder.stl) | Tough PLA or ABS
14 | Flexible torsion
| spring | SP, PP | 3 | flexible_torsion_spring.stl (https://github.com/xmotion-project/karaloop/blob/main/karaloop_P2_0/Hardware/Mechanical%20Design/Sub-assembly/Switch%20probe/STL/flexible_torsion_spring.stl) | TPU
15 | Potentiometric
| probe's holder
| right | PP | 1 | potentiometric_probe_hold
| | | | er_r.stl (https://github.com/xmotion-project/karaloop/blob/main/karaloop_P2_0/Hardware/Mechanical%20Design/Sub-assembly/Potentiometric%20probes/STL/potentiometric_probe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) | Tough PLA or ABS

16

Potentiometric
probe's holder
left
| PP | 1 | potentiometric_probe_hold
| | | er_l.stl (https://github.com/xmotion-project/karaloop/blob/main/karaloop_P2_0/Hardware/Mechanical%20Design/Sub-assembly/Potentiometric%20probes/STL/potentiometric_probe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) | Tough PLA or ABS
17 | Potentiometer
holder | PP | 2 | potentiometer_holder.stl (https://github.com/xmotion-project/karaloop/blob/main/karaloop_P2_0/Hardware/Mechanical%20Design/Sub-assembly/Potentiometric%20probes/STL/potentiometer_holder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) | Tough PLA or ABS
18 | Potentiometric
wheel | PP | 2 | potentiometric_wheel.stl (https://github.com/xmotion-project/karaloop/blob/main/karaloop_P2_0/Hardware/Mechanical%20Design/Sub-assembly/Potentiometric%20probes/STL/potentiometer_wheel.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) | Tough PLA or ABS

05.08.2022 – V1.3 | General and Assembly description – karaloop P2.0 | P.20

This work was partially sponsored by Fondation Privée des HUG (https://www.fondationhug.org/) and Wyss Center (https://wysscenter.ch/) through support awarded to Ferran Galán at University of Geneva. (https://www.unige.ch/en/university/presentation/)

Quentin Praz, Ahmad Jaafar, Spiros Schoinas and Philippe Passeraub from HEPIA, (https://www.hesge.ch/hepia/) and Ferran Galán from University of Geneva (https://www.unige.ch/en/university/presentation/) contributed to the conception and development of karaloop P1.0, (https://github.com/xmotion-project/xMotion/wiki/karaloop-P1.0) P2.0 (https://github.com/xmotion-project/xMotion/wiki/karaloop-P2.0) and P3.0. (https://github.com/xmotion-project/xMotion/wiki/karaloop-P3.0)

karaloop P2.0 (https://github.com/xmotion-project/xMotion/wiki/karaloop-P2.0) is OSHWA-certified (https://certification.oshwa.org/) open source hardware [CH00015]. (https://certification.oshwa.org/list.html)

This document is licensed under Creative Commons Attribution 4.0 International (CC BY 4.0). (https://creativecommons.org/licenses/by/4.0/)

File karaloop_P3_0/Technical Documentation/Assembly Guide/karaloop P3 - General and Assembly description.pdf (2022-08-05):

# GENERAL DESCRIPTION


# karaloop P3.0


05.08.2022 – V1.4 | General and Assembly description – karaloop P3.0 | P.2

karaloop – Prototype 3.0 (P3.0)

P3.0 is a fully adjustable light-weight wireless headset that measures voluntary movements of the face and translates them into mouse/keyboard commands sent via Bluetooth Low Energy (BLE) to any PC, iOS or Android device.
P3.0 consists of a padded headband (1) designed to provide extensive-use comfort; two hubs (2, 4) housing an Arduino-compatible Bluefruit nRF52 Feather board that is automatically recognized via BLE as a human-interface device (HID) by any PC, iOS or Android device, and a rechargeable built-in battery that delivers hours of wireless use in a single charge; and three probes (3, 4, 6) that detect voluntary movements of the face. Two mechanical contact probes (3, 4) capture orofacial movements bilaterally via magnetic-based sensing, and a contactless probe (6) captures forehead movements via optical sensing.
Designed for easy setup, P3.0 is calibration-free and only requires an initial mechanical adjustment to ensure a stable and comfortable fit for all-day use of mainstream devices without hands.

P3.0 components. (1) Head band; (2) Left hub; (3) Left magnetic probe; (4) Right magnetic probe; (5) Right hub; (6) Optical probe.


05.08.2022 – V1.4 | General and Assembly description – karaloop P3.0 | P.3

# ASSEMBLY DESCRIPTION

# karaloop P3.0

05.08.2022 – V1.4 | General and Assembly description – karaloop P3.0 | P.4

# CONTENTS

# General assembly

1


05.08.2022 – V1.4 | General and Assembly description – karaloop P3.0 | P.5
N° | Part description | Abbreviation | Quantity
1 | Headset band sub-assembly | HB | 1
2 | Right hub sub-assembly | RH | 1
3 | Left hub sub-assembly | LH | 1
4 | Magnetic probe sub-assembly | MP | 2
5 | Optical probe sub-assembly | OP | 1

3

4

2

5

# 1. Headset band sub-assembly


05.08.2022 – V1.4 | General and Assembly description – karaloop P3.0 | P.6

The padded headset band ensures stable yet adjustable (Right and Left hubs) functionality for all-day comfort.

N° | Part description
1.1 | Flexible top cover
1.2 | Curved spring wires (3x)
1.3 | Right side node
1.4 | Allen screw M3x10 (2x)
1.5 | Side padding (2x)
1.6 | Left side node
1.7 | Locking wheel (2x)
1.8 | Flexible headband
1.9 | Top padding

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
05.08.2022 – V1.4 | General and Assembly description – karaloop P3.0 | P.7

## FABRICATION PROCESS

MATERIALS NEEDED can be found in Mechanical Part List (MPL, page 24), Printed Parts List (PPL, page 25) and Electronical part list (EPL, page 22)

Step | Description | Materials needed

### 1 Curved spring wires (Part N°1.2)

| Bend the three spring wires as illustrated with a bending radius of 80 mm and cut them to an angle of 140°. | • Spring wires of Ø1.6 mm (MPL N°2) • Pattern for each wire:

### 2 Headband assembly (Parts N°1.1, 1.2, 1.3, 1.6, 1.8)

1. Insert two of the three curved spring wires (Part N°1.2) into the flexible headband.
2. Slide them into the two side nodes (right/left) (Parts N°1.3, 1.6) connecting the nodes with the flexible headband (Part N°1.7).
3. Insert the third spring wire (Part N°1.2) into each side node (Parts N°1.3, 1.6) and cover up with the flexible top cover (Part N°1.1). A pair of pliers may be helpful.
- Curved spring wires (3x) (Step 1.1)
- Flexible headband (PPL N°5)
- Flexible top cover (PPL N°1)
- Right side node (PPL N°2)
- Left side node (PPL N°3)
- Flat pliers (Tool)

### 3 Padding (Parts N°1.5, 1.9)

1. Side padding (Part N°1.5): Cut (2x) memory foam pieces of 12 mm thickness as illustrated.
2. Top padding (Part N°1.9): Cut (1x) thin foam of 3 mm thickness with the pattern of the top foam as illustrated.
3. Cover the foams from steps 1.3.1 and 1.3.2 with thin tissue using a sew machine.
4. Attach the covered foams from step 1.3.3 to the side nodes (Parts N°1.3, 1.6) and the flexible headband (Part N°1.7) with double tape.
- Memory foam (MPL N°3)
- Side padding pattern:
- Thin Foam (MPL N°4)
- Top padding pattern:
- Thin tissue for covering (MPL N°6)
- Sew machine (Tool)
- Pair of scissors/cutter (Tool)
- Headband assembly (Step 1.2)
- Double tape

### 4 Locking screws (Parts N°1.4, 1.7)

1. Assemble the locking screws (2x) by fixing the locking wheel (Part N°1.7) on the head of the Allen screw (Part N°1.4).
2. Screw them on each side node (Parts N°1.3, 1.6). When fully screwed, they will lock the sliding straight wires from the right/left hubs sub-assembly (Parts N°2, 3) into the desired position.
- Allen screw M3x10 (MPL N°1)
- Locking wheel (PPL N°4)
- Headband assembly (Step 1.2)
- Right hub (Part N°2)
- Left hub (Part N°3)

### 5 Electrical wiring

Insert and slide the flat cable through both side nodes (Parts N°1.3, 1.4) and the flexible headband (Part N°1.8). The flat cable will connect both hubs (Parts N°2, 3).

- 6-contacts flat cable (EPL N°13)
- Headband assembly (Step 1.2)

# 2. Right Hub sub-assembly


05.08.2022 – V1.4 | General and Assembly description – karaloop P3.0 | P.8

The right hub is topped with two straight spring wires (Part N°2.5) that slide within the corresponding righ side node (Part N°1.3). The sliding range allows fine adjustement for stable and comfortable fit. The right hub houses a microcontroler Bluefruit nRF52832 feather (Part N°2.4), a sliding ON/OFF switch (Part N°2.11), two push-buttons (Part N°2.7), a green LED (Part N°2.6), a QWIIC I2C (Part N°2.12) adapter and wired connections.

N° | Part description
2.1 | Right hub cover
2.2 | Flat head screw M2.5x8 (5x)
2.3 | Hub end part
2.4 | Bluefruit nRF52832 feather
2.5 | Straight spring wire (2x)
2.6 | Green LED
2.7 | Push-button (2x)
2.8 | Right hub holder
2.9 | Bottom padding

2.10 Top padding

2.11 Slide switch ON/OFF

2.12 QWIIC I2C ADAPTER

2.3

2.1 2.2

2.4

2.6

2.8 2.7

2.9

2.1 | 2.5

2.11
2.10


05.08.2022 – V1.4 | General and Assembly description – karaloop P3.0 | P.9

## FABRICATION PROCESS

MATERIALS NEEDED can be found in Mechanical Part List (MPL, page 24), Printed Parts List (PPL, page 25) and Electronical part list (EPL, page 22)

Step | Description | Materials needed

### 1 Straight spring wires (Part N°2.5)

1. Cut (4x) 90 mm long straight spring wires
| (Another pair for the left hub).
2. Insert (2x) the bottom end of the straight
| spring wires (Part N°2.5) into the right hub holder (Part N°2.8).
| A pair of pliers may be helpful. | • Spring wire of Ø1.6 mm (MPL N°2) • Right hub holder (PPL N°6) • Flat pliers (Tool)

### 2 Padding (Parts N°2.9, 2.10)

1. Top padding (Part N°2.10):
Cut (2x) memory foam of 12 mm thickness as illustrated (one for the Left hub).
2. Bottom padding (Part N°2.9):
Cut (2x) memory foam of 12 mm thickness as illustrated aside (one for the Left hub).
3. Cover the foams from step 2.2.1 and 2.2.2 with thin tissue using a sew machine.
4. Attach one pair of the covered foams from
step 2.2.3 to the back side of the right hub holder (Part N°2.8) with double tape within the specified areas.
- Memory foam (MPL N°3)
- Top padding pattern:
- Bottom padding pattern:
- Thin tissue for covering (MPL N°6)
- Sew machine (Tool)
- Pair of scissors or cutter (Tool)
- Double tape

3 Electrical wiring (Parts N°1, 2.4, 2.6, 2.7, 2.11, 2.12)
1. Connect the Green LED (Part N°2.6), the two Push-button (Part N°2.7), the ON/OFF switch (Part N°2.11) and the QWIIC I2C ADAPTER (Part N°2.12) with the Bluefruit nRF52832 feather (Part N°2.4) following the electrical schematic (Pag. 23).
2. Connect the right hub (Part N°2) with the headband’s flat cable (Part N°1) following the flat cable’s pinout.
- Green LED (EPL N°8)
- Push-button (EPL N°6)
- QWIIC I2C ADAPTER (EPL N°9)
- Slide Switch ON/OFF (EPL N°5)
- Bluefruit nRF52832 feather (EPL N°1)
- Headset band (Part N°1)
- Flat cable pinout (right side):

05.08.2022 – V1.4 | General and Assembly description – karaloop P3.0 | P.10

4 Assembly with the Right hub cover (Part N°2.1, 2.2 – Step 2.3)
Attach the right hub cover (Part N°2.1) to the assembly from step 2.3 by adding (5x) Flat head screw M2.5x8 (Part N°2.2).
- Flat head screw M2.5x8 (MPL N°5)
- Right hub cover (PPL N°6)

### 5 Assembly with headset band (Parts N°1, 2)

1. Slide the top end of the straight spring wires (Part N°2.5) through the right node (Part N°1.3).
2. Insert the top end of the straight spring wires (Part N°2.5) into the hub end-part (Part N°2.3).
3. Use the locking screw (Step 1.4) to lock both together into the desired sliding position.
- Straight spring wires (Step 2.1)
- Headset band (Part N°1)
- Hub end-part (PPL N°7)

# 3. Left Hub sub-assembly


05.08.2022 – V1.4 | General and Assembly description – karaloop P3.0 | P.11

Like the right hub, the left hub is topped with two straight spring wires that slide within the corresponding (left) side node (Part N°1.3). The sliding range allows fine adjustement for stable and comfortable fit. The left hub houses a QWIIC I2C adapter (Part N°3.3), a green LED (Part N°3.7), a battery (Part N°3.8) and wired connections.

N° | Part description
3.1 | Flat head screw M2.5x8 (5x)
3.2 | Left hub cover
3.3 | QWIIC I2C ADAPTER
3.4 | Left hub holder
3.5 | Top padding
3.6 | Bottom padding
3.7 | Green LED
3.8 | Battery Li-Po 3.7V – 350mA
3.9 | Straight spring wire (2x)

3.10 Hub end-part

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
3.10


05.08.2022 – V1.4 | General and Assembly description – karaloop P3.0 | P.12

## FABRICATION PROCESS

MATERIALS NEEDED can be found in Mechanical Part List (MPL, page 24), Printed Parts List (PPL, page 25) and Electronical part list (EPL, page 22)

Step | Description | Materials needed

### 1 Straight spring wires (Part N°3.9)

| Insert (2x) the bottom end of the straight spring wires (Step 2.1) into the left hub holder (Part N°3. 4).
| A pair of pliers may be helpful. | • Straight spring wires (Step 2.1) • Left hub holder (PPL N°9) • Flat pliers (Tool)

### 2 Padding (Parts N°3.5, 3-6)

Attach the top and bottom padding (Step
2.2) covered foams to the back side of the left hub holder (Part N°3.4) with double tape within the specified areas.
- Top padding (1x) (Step 2.2)
- Bottom padding (1x) (Step 2.2)
- Double tape

### 3 Electrical wiring (Parts N°1, 3.3, 3.7, 3.8)

Connect the battery (Part N°3.8), the Green LED (Part N°3.7) and the QWIIC I2C ADAPTER (Part N°3.3) with the headband’s flat cable (Part N°1) following the flat cable‘s pinout and the electrical schematic (Pag. 23).

- Green LED (EPL N°8)
- Battery Li-Po 3.7V – 350mA (EPL N°2)
- QWIIC I2C ADAPTER (EPL N°9)
- Headset band (Part N°1)
- Flat cable pinout (left side):

4 Assembly with the Left hub cover (Part N°3.1, 3.2 – Step 3.3) Attach the left hub cover (Part N°3.2) to the assembly from step 2.3 by adding (5x) Flat head screw M2.5x8 (Part N°3.1).

- Flat head screw M2.5x8 (MPL N°5)
- Left hub cover (PPL N°10)

### 5 Assembly with headset band (Parts N°1, 3)

1. Slide the top end of the straight spring wires (Part N°3.9) through the left node (Part N°1.6).
2. Insert the top end of the straight spring wires (Part N°3.9) into the hub end-part (Part N°3.10).
3. Use the locking screw (Step 1.4) to lock both together into the desired sliding position.
- Straight spring wires (Step 2.1)
- Headset band (Part N°1)
- Hub end-part (PPL N°7)

# 4. Magnetic probe sub-assembly


05.08.2022 – V1.4 | General and Assembly description – karaloop P3.0 | P.13

Both magnetic probes (Part N°4) consist of a mechanical unit that translates orofacial movements into a moving magnet (mobile unit), and a magnetometer Adafruit MLX90393 (Part N°4.4) sensing unit that measures the magnet’s magnetic field (fixed unit). The probes slide vertically through the corresponding (right/left) hub (Parts N° 2, 3) to fit the contour of any face.

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
4.10 4.11 | 4.12
| 4.13

4.14

4.15

4.1

Step; Description; Materials needed; • Steel wire of Ø2 mm (MPL N°10) • Pattern for the top beam:; • Pattern for the bottom beam:

05.08.2022 – V1.4 | General and Assembly description – karaloop P3.0 | P.14

## FABRICATION PROCESS

Both (left/right) probes share the same process except step 4.5 which involve different (left/right) tubes (Part N°4.8).

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

### 1 Top and bottom Beams (Parts N°4.7, 4.13)

Make the top (Part N°4.7) and bottom (Part N°4.13) beams as illustrated with a steel wire of

N° | Mechanical part description
4.1 | Magnetometer top cover
4.2 | Cylindrical head screw M2.5x6 (2x)
4.3 | Magnetometer support
4.4 | Adafruit MLX90393
4.5 | Axial disc magnet
4.6 | Magnet holder
4.7 | Top beam
4.8 | Right or Left tube
4.9 | Spring holder part 1
4.10 | Traction spring of 13 mm long
4.11 | Spring holder part 2
4.12 | Spherical socket
4.13 | Bottom beam
4.14 | End part holder
4.15 | Rubber end part

05.08.2022 – V1.4 | General and Assembly description – karaloop P3.0 | P.15

2 Elastic coupling assembly (Parts N°4.9, 4.10, 4.11)
1. Cut the traction spring of 1m long to have (2x) a 13 mm piece (Part N°4.10).
2. Apply metal glue inside of each spring holder (Part N°4.9, 4.11) and fix them to each side of the 13mm long traction spring (Part N°4.10).
3. Let the glue dry during 2 hours before continuing.
- Traction spring of 1m long (MPL N°11)
- Spring holder part 1 (PPL N°18)
- Spring holder part 2 (PPL N°19)
- Metal glue: CYANOACRYLATE INSTANT ADHESIVES such as
Ergo®5011 or Ergo®5901

### 3 Top beam and elastic coupling assembly (Part

N°4.7 – Step 4.2)

1. Fill the central hole in the spring holder part 2 (Part N°4.11) with metal glue.
2. Insert the spring side of the top beam (Part N°4.7) into the elastic coupling (Step 4.2) and guide it through the glued central hole (step 4.3.1) in the spring holder part.
- Top beam (Step 4.1)
- Elastic coupling (Step 4.2)
- Metal glue: CYANOACRYLATE INSTANT ADHESIVES such as
Ergo®5011 or Ergo®5901

4 Bottom beam assembly (Parts N°4.13, 4.12, 4.14, 4.15)

1. Apply metal glue on both ends of the bottom beam (Part N°4.13).
2. Insert the spring side of the bottom beam (step 4.1.2) through the spherical socket central hole (Part N°4.12).
3. Insert the rubber side of the bottom beam (step 4.1.2) through the end-part holder (Part N°4.14) central hole.
4. Insert the end-part holder (Part N°4.14) into the rubber end-part (Part N°4.15).
5. Let the glue dry before continuing.
- Bottom beam (Step 4.1)
- Spherical socket (PPL N°20)
- End-part holder (PPL N°21)
- Rubber end-part (MPL N°13)
- Metal glue: CYANOACRYLATE INSTANT ADHESIVES such as
Ergo®5011 or Ergo®5901

### 5 Mobile unit assembly (Parts N°4.5, 4.6 – Step

4.3, 4.4)
1. Assemble the resulting parts from steps 4.3 and 4.4 by inserting the spring holder part 2 (Part N°4.11) into the spherical socket (Part N°4.12).
2. Insert the resulting part from step 4.5.1 through the tube (left/right) (Part N°4.8).
3. Insert the magnet side of the top beam (step
4.1.1) into the magnet holder.
4. Place the axial disc magnet into the magnet holder (Part N°4.6).
- Top beam and elastic coupling assembly (Step 4.3)
- Bottom beam assembly (Step 4.4)
- Magnet holder (PPL N°15)
- Axial disc magnet (MPL N°12)
- Right/left tube (PPL N°16, 17)

05.08.2022 – V1.4 | General and Assembly description – karaloop P3.0 | P.16

6 Fixed and mobile unit assembly (Parts N°4.1, 4.2, 4.3, 4.4 – Step 4.5)
1. Fix the Adafruit MLX90393 (Part N°4.4) between the magnetometer support (Part N°4.3) and the magnetometer top cover (Part N°4.1) using (2x) cylindrical head screws M2.5x6 (Part N°4.2).
2. Slide the mobile unit (Step 4.5) into the magnetometer support (Part N°4.3).
- Adafruit MLX90393 (EPL N°3)
- Magnetometer support
(PPL N°14)
- Magnetometer top cover
(PPL N°13)
- Cylindrical head screw
M2.5x6 (MPL N°9)
- Mobile unit assembly (Step 4.5)

### 7 Electrical wiring (Parts N°2, 3, 4.4)

1. Insert the JST SH 4-PIN cable (connector side) in the right side of the QWIIC I2C ADAPTER (Part N°2.12, 3.3).
2. Connect the JST SH 4-PIN cable (wires side) to the Adafruit MLX90393 (Part N°4.1) following the electrical schematic (Pag. 23).
- Adafruit MLX90393 (EPL N°3)
- JST SH 4-PIN cable (EPL N°12)
- QWIIC I2C ADAPTER (EPL N°9)

### 8 Assembly with the right or left hub (Parts N° 2, 3

– Step 4.7)
Slide the assembly from step 4.7 into the bottom part of the right/left hub following the general assembly (Pag. 5).
- Right hub (Part N°2)
- Left hub (Part N°3)


05.08.2022 – V1.4 | General and Assembly description – karaloop P3.0 | P.17

# 5. Optical probe sub-assembly

The optical probe (Part N°5) measures voluntary forehead movements. A flexible metal conduit (Part N°5.5) and a sliding join (Parts N°5.6, 5.7) allow to finely adjusting the position and orientation of the optical sensing unit (Parts N°5.1, 5.4) respect the forehead.

N° | Mechanical part description
5.1 | Optical sensor case
5.2 | White LED L3-W36N-BVW (https://www.distrelec.ch/fr/led-3mm-rond-blanc-9cd-sloan-l3-w36n-bvw/p/17524118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)
5.3 | Phillips screw M2x6 (2x)
5.4 | Optical sensor PCB
5.5 | Flexible metal conduit
5.6 | Sliding join male
5.7 | Sliding join female
5.8 | 8pos 1.27mm male connector
5.9 | 8pos 1.27mm female connector

5.10 Wires cover


05.08.2022 – V1.4 | General and Assembly description – karaloop P3.0 | P.18

## FABRICATION PROCESS

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

Step | Description | Materials needed

### 1 Flexible metal conduit (Part N°5.5)

| Cut a piece 136mm long of Interlock Type-C Conduit. | • Flexible metal Conduit of 10m (MPL N°8)

### 2 Housing assembly (Parts N°5.1, 5.5, 5.6)

1. Insert one end of the flexible metal conduit (Part N°5.5) into the optical sensor case (Part N°5.1) side opening.
2. Insert the other end of the flexible metal conduit (Part N°5.5) into the sliding join male (Part N°5.6).
3. Secure the assembly applying metal glue at around the contours interfacing the flexible metal conduit (Part N°5.5) with the optical sensor case (Part N°5.1) and the sliding join male (Part N°5.6).
4. Let the glue dry before continuing.
- Optical sensor case (PPL N°9)
- Flexible metal conduit (Step 5.1)
- Sliding join male (PPL N°10)
- Metal glue: CYANOACRYLATE INSTANT ADHESIVES such as Ergo®5011 or Ergo®5901

### 3 Sensing unit assembly (Parts N°5.2, 5.4)

1. Drill the optical sensor PCB (Part N°5.4) with 2x 1mm diameter holes as indicated in the figure in yellow.
2. Insert the white LED (Part N°5.2) pins through the drilled holes in step 5.3.1.
3. Secure the white LED (Part N°5.2) on the optical sensor PCB (Part N°5.4) with hot glue.
- White LED (EPL N°7)
- Optical sensor PCB (PCB-PL P.21, EPL N°4)
- Driller (tool)
- Silicone hot gun (tool)


05.08.2022 – V1.4 | General and Assembly description – karaloop P3.0 | P.19

### 4 Electrical wiring

1. Cut 8 wires with a length of 150 mm and solder them with the pins of the optical sensor.
2. Twist the wires and pass them through the probe created at the step 2 by the side of the optical sensor case (Part N°5.1).
3. Solder the wires coming out of the sliding join male (Part N°5.6) with the female connector (Part N°5.9) according to the figure beside.
4. Cut 8 electric wires and solder them on the Male connector (Part N°5.8).
5. Insert the Male connector (Part N° 5.8) with the soldered wires inside the housing located on the Sliding join female (Part N°5.7).
6. Secure the Male connector (Part N°5.8) on the Sliding join female (Part N°5.7) with hot glue.
7. Assemble the Sliding join female (Part N°5.7) above the right hub.
8. Solder the wires coming out of the Sliding join female (Part N°5.7) with the Bluefruit NRF52 Feather (Part N°2.4) according to the electrical schematic (Pag. 23).
- 28AWG wires or 30AWG wires
- Silicone hot gun (tool)
- Sliding join female (PPL N°11)


05.08.2022 – V1.4 | General and Assembly description – karaloop P3.0 | P.20

# Optical sensor circuit schematic


05.08.2022 – V1.4 | General and Assembly description – karaloop P3.0 | P.21

# PCB optical sensor Layout

# PCB optical sensor parts list (PCB-PL)

N° PCB part description | Quantity | Datasheet | Supplier link

1

Motion tracking sensor
PMW3901 | 1 | PMW3901MB-TXQT (https://www.codico.com/de/pmk3903is-sample-kit-cdc)

2

Translation Bidirectional 4-
channel voltage levels | 1 | TXB0104RUTR (https://www.mouser.ch/ProductDetail/595-TXB0104RUTR)

3

MOSFET SOT-23 N-CH LOGIC
BSS138 | 2 | BSS138 (https://www.mouser.ch/ProductDetail/512-BSS138)
4 | SMD resistors 0603 4.7KΩ 5% | 4 | SFR03EZPJ472 (https://www.mouser.ch/ProductDetail/755-SFR03EZPJ472)

5

TLV70218 Voltage regulators
1.8V, LDO, 300mA | 1 | TLV70218DBVR (https://www.mouser.ch/ProductDetail/Texas-Instruments/TLV70218DBVR)

6

TLV70228 Voltage regulators
2.8V, LDO, 300mA | 1 | TLV70228DBVR (https://www.mouser.ch/ProductDetail/595-TLV70228DBVR)

7

Ceramic Capacitors SMD 6.3V
0.1uF 0603 10% | 3 | 0603C104K5RECAUTO7411 (https://www.mouser.ch/ProductDetail/80-C0603C104K5REAULR)

8

Ceramic Capacitors SMD 6.3V
1uF 0603 10% | 4 | C0603C105K9RAC7411 (https://www.mouser.ch/ProductDetail/80-C0603C105K9R7411)

9

Ceramic Capacitors SMD 6.3V
4.7uF 0603 10% | 1 | GMK107BBJ475KA-T (https://www.mouser.ch/ProductDetail/963-GMK107BBJ475KA-T)

10 Ceramic Capacitors SMD 6.3V
10uF 0603 10% | 1 | C0603C106M8PACTU (https://www.mouser.ch/ProductDetail/80-C0603C106M8PACTU)
Front View | Back View


05.08.2022 – V1.4 | General and Assembly description – karaloop P3.0 | P.22

# Electronic parts list (EPL)

N° | Part description | Quantity | Datasheet | Supplier Link
1 | Bluefruit nRF52 Feather | 1 | | Nrf52 (https://www.adafruit.com/product/3574)
2 | Rechargeable battery Li-Po 3.7V
| 350mAh | 1 | | ICP602823PA (https://www.distrelec.ch/fr/batterie-accumulateurs-rechargeable-li-po-7v-350mah-renata-icp602823pa-01/p/30158722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)
3 | Triple-axis Magnetic sensor | 2 | | MLX90393 (https://www.adafruit.com/product/4022)
4 | Motion tracking optical sensor | 1 | | PMW3901
5 | Slide Switch ON/OFF | 1 | | RND 210-00581 (https://www.distrelec.ch/en/miniature-slide-switch-1co-on-on-soldering-lugs-rnd-components-rnd-210-00581/p/30152605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)
6 | Push button | 2 | | PTS647SK70 (https://www.digikey.ch/product-detail/de/c-k/PTS-647-SK70-SMTR2-LFS/PTS647SK70SMTR2LFSTR-ND/9649856)
7 | White LED | 1 | | L3-W36N-BVW (https://www.distrelec.ch/fr/led-3mm-rond-blanc-9cd-sloan-l3-w36n-bvw/p/17524118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)
8 | Green LED | 2 | | WP7113LGD (https://www.digikey.com/en/products/detail/kingbright/WP7113LGD/1747664)
9 | QWIIC I2C ADAPTER | 2 | | DEV-14495 (https://www.sparkfun.com/products/14495)
10 | 8pos 1.27mm female connector | 1 | | 200213 (https://www.digikey.ch/product-detail/fr/amphenol-icc-fci/20021311-00008T4LF/609-3753-ND/2209076)
11 | 8pos 1.27mm male connector | 1 | | 20021111 (https://www.digikey.ch/product-detail/fr/amphenol-icc-fci/20021111-00008T4LF/609-3711-ND/2209071)
12 | JST SH 4-PIN cable | 2 | | 4209 (https://www.digikey.fr/product-detail/fr/4209/1528-4209-ND/10230003/?itemSeq=357957125)
13 | 6-contacts flat cable | 300 mm | | flat cable (https://www.molex.com/molex/products/part-detail/cable/1000570030)


05.08.2022 – V1.4 | General and Assembly description – karaloop P3.0 | P.23

# General circuit schematic

05.08.2022 – V1.4 | General and Assembly description – karaloop P3.0 | P.24

# Mechanical parts list (MPL)

ASSEMBLY: Headset band (HB), Right hub (RH), Left hub (LH), Magnetic probe (MP), Optical probe (OP)

N° | Part description | Assembly | Quantity | Link
1 | Allen screw M3x10 | HB | 2 | [M3x10] (https://www.bossard.com/eshop/fr-fr/vis-s-a-entrainement-interieur/vis-a-tete-cylindrique-a-six-pans-creux-entierement-filetees/p/3/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)
2 | Spring wire of Ø1.6 mm | HB, RH, LH | 1 (m) | [Spring wire] (https://www.durovis.ch/index.php/fr/shop-ressorts-normalises/fil-ressort-standard-disponible.html)
3 | Memory foam of 12mm
| thickness | HB, RH | A4 (210 x 297 mm) | [Foam 1] (https://www.digikey.fr/product-detail/fr/CFNT-EGS+12MM+A4/EAR1041-ND/6226691/?itemSeq=355418852)
4 | Thin foam of 3 mm thickness | HB | A4 (210 x 297 mm) | [Foam 2] (https://www.digikey.fr/product-detail/fr/3m-aearo-technologies-llc/CF45EG-3MM-A4/EAR1025-ND/6226675)
5 | Flat head screw M2.5x8 | RH, RL | 10 | [M2.5x8] (https://www.bossard.com/eshop/fr-fr/vis-s-a-entrainement-interieur/vis-a-tete-fraisee-avec-empreinte-cruciforme-phillips-forme-h/p/661/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)
6 | Thin tissue for covering | RH, RL | 500 mm² | [tissue] (https://www.kreando.ch/fr/similicuir-qualite-souple-nappa-noir/)
7 | Philipps screw M2x6 | OP | 2 | [M2x6] (https://www.bossard.com/eshop/fr-fr/vis-s-a-entrainement-interieur/vis-a-tete-cylindrique-avec-empreinte-cruciforme-phillips-forme-h/p/380/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)
8 | Flexible metal Conduit of 10m | OP | 10 m | IS-4N (https://www.hagitec.de/index.php/en/products/flexible-metal-conduits/flexible-metal-conduits-product-list/interlock-type-c-conduit)
9 | Cylindrical head screw M2.5x6 | MP | 4 | [M2.5x6] (https://www.bossard.com/eshop/fr-fr/vis-s-a-entrainement-interieur/vis-a-tete-cylindrique-avec-empreinte-cruciforme-phillips-forme-h/p/381/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)
10 | Steel wire of Ø2mm | MP | 500 mm | [Steel wire] (https://www.jumbo.ch/fr/bobine-de-fil-de-fer-galvanise-26505?sku=1096747)
11 | Traction spring of 1m long | MP | 1 m | [Spring] (https://www.durovis.ch/index.php/fr/shop-ressorts-normalises/ressorts-de-traction-de-1-metre-disponibles.html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)
12 | Axial disc magnet | MP | 2 | [Magnet] (https://www.supermagnete.ch/fre/aimants-disques-neodyme/disque-magnetique-4mm-2mm_S-04-02-N)
13 | Rubber end-part | MP | 2 | [Rubber] (https://www.digitec.ch/en/s1/product/sennheiser-ear-adapter-headphone-spare-parts-280598)

05.08.2022 – V1.4 | General and Assembly description – karaloop P3.0 | P.25

# Printed parts list (PPL)

ASSEMBLY: Headset band (HB), Right hub (RH), Left hub (LH), Magnetic probe (MP), Optical probe (OP)

N° | Part description Assembly | Quantity | Part name | Printing material

1

Flexible top
cover
| | HB | 1 | flexible_top_cover.stl (https://github.com/xmotion-project/karaloop/blob/main/karaloop_P3_0/Hardware/Mechanical%20Design/Sub-assembly/Headset%20band/STL/flexible_top_cover.stl) | TPU
2 | Right side node | HB | 1 | right_side_node.stl (https://github.com/xmotion-project/karaloop/blob/main/karaloop_P3_0/Hardware/Mechanical%20Design/Sub-assembly/Headset%20band/STL/right_side_node.stl) | Tough PLA or ABS
3 | Left side node | HB | 1 | left_side_node.stl (https://github.com/xmotion-project/karaloop/blob/main/karaloop_P3_0/Hardware/Mechanical%20Design/Sub-assembly/Headset%20band/STL/left_side_node.stl) | Tough PLA or ABS
4 | Locking wheel | HB | 2 | locking_wheel.stl (https://github.com/xmotion-project/karaloop/blob/main/karaloop_P3_0/Hardware/Mechanical%20Design/Sub-assembly/Headset%20band/STL/locking_wheel.stl) | TPU
5 | Flexible
| headband | HB | 1 | flexible_headband.stl (https://github.com/xmotion-project/karaloop/blob/main/karaloop_P3_0/Hardware/Mechanical%20Design/Sub-assembly/Headset%20band/STL/flexible_headband.stl) | TPU
6 | Right hub cover | RH | 1 | right_hub_cover.stl (https://github.com/xmotion-project/karaloop/blob/main/karaloop_P3_0/Hardware/Mechanical%20Design/Sub-assembly/Right%20hub/STL/right_hub_cover.stl) | Tough PLA or ABS
7 | Hub end part | RH, LH | 2 | hub_end_part.stl (https://github.com/xmotion-project/karaloop/blob/main/karaloop_P3_0/Hardware/Mechanical%20Design/Sub-assembly/Right%20hub/STL/hub_end_part.stl) | Tough PLA or ABS
8 | Right hub
| holder | RH | 1 | right_hub_holder.stl (https://github.com/xmotion-project/karaloop/blob/main/karaloop_P3_0/Hardware/Mechanical%20Design/Sub-assembly/Right%20hub/STL/right_hub_holder.stl) | Tough PLA or ABS
9 | Left hub holder | LH | 1 | left_hub_holder.stl (https://github.com/xmotion-project/karaloop/blob/main/karaloop_P3_0/Hardware/Mechanical%20Design/Sub-assembly/Left%20hub/STL/left_hub_holder.stl) | Tough PLA or ABS
10 | Left hub cover | LH | 1 | left_hub_cover.stl (https://github.com/xmotion-project/karaloop/blob/main/karaloop_P3_0/Hardware/Mechanical%20Design/Sub-assembly/Left%20hub/STL/left_hub_cover.stl) | Tough PLA or ABS
9 | Optical sensor
| case | OP | 1 | optical_sensor_case.stl (https://github.com/xmotion-project/karaloop/blob/main/karaloop_P3_0/Hardware/Mechanical%20Design/Sub-assembly/Optical%20probe/STL/optical_sensor_case.stl) | Tough PLA or ABS
10 | Sliding join male | OP | 1 | sliding_join_male.stl (https://github.com/xmotion-project/karaloop/blob/main/karaloop_P3_0/Hardware/Mechanical%20Design/Sub-assembly/Optical%20probe/STL/sliding_join_male.stl) | Tough PLA or ABS
11 | Sliding join
| female | OP | 1 | sliding_join_female.stl (https://github.com/xmotion-project/karaloop/blob/main/karaloop_P3_0/Hardware/Mechanical%20Design/Sub-assembly/Optical%20probe/STL/sliding_join_female.stl) | Tough PLA or ABS
12 | Wires cover | OP | 1 | wires_cover.stl (https://github.com/xmotion-project/karaloop/blob/main/karaloop_P3_0/Hardware/Mechanical%20Design/Sub-assembly/Optical%20probe/STL/wires_cover.stl) | Tough PLA or ABS
13 | Magnetometer
| top cover | MP | 2 | magnetometer_top_co
| | | | ver.stl (https://github.com/xmotion-project/karaloop/blob/main/karaloop_P3_0/Hardware/Mechanical%20Design/Sub-assembly/Magnetic%20probe/STL/magnetometer_top_cover.stl) | Tough PLA or ABS
14 | Magnetometer
| support | MP | 2 | magnetometer_support
| | | | .stl (https://github.com/xmotion-project/karaloop/blob/main/karaloop_P3_0/Hardware/Mechanical%20Design/Sub-assembly/Magnetic%20probe/STL/magnetometer_support.stl) | Tough PLA or ABS
15 | Magnet holder | MP | 2 | magnet_holder.stl (https://github.com/xmotion-project/karaloop/blob/main/karaloop_P3_0/Hardware/Mechanical%20Design/Sub-assembly/Magnetic%20probe/STL/magnet_holder.stl) | Tough PLA or ABS
16 | Right tube | MP | 1 | right_tube.stl (https://github.com/xmotion-project/karaloop/blob/main/karaloop_P3_0/Hardware/Mechanical%20Design/Sub-assembly/Magnetic%20probe/STL/right_tube.stl) | Tough PLA or ABS
17 | Left tube | MP | 1 | left_tube.stl (https://github.com/xmotion-project/karaloop/blob/main/karaloop_P3_0/Hardware/Mechanical%20Design/Sub-assembly/Magnetic%20probe/STL/left_tube.stl) | Tough PLA or ABS
18 | Spring holder
| part 1 | MP | 2 | spring_holder_part1.stl (https://github.com/xmotion-project/karaloop/blob/main/karaloop_P3_0/Hardware/Mechanical%20Design/Sub-assembly/Magnetic%20probe/STL/spring_holder_part1.stl) | Tough PLA or ABS
19 | Spring holder
| part 2 | MP | 2 | spring_holder_part2.stl (https://github.com/xmotion-project/karaloop/blob/main/karaloop_P3_0/Hardware/Mechanical%20Design/Sub-assembly/Magnetic%20probe/STL/spring_holder_part2.stl) | Tough PLA or ABS
20 | Spherical socket | MP | 2 | spherical_socket.stl (https://github.com/xmotion-project/karaloop/blob/main/karaloop_P3_0/Hardware/Mechanical%20Design/Sub-assembly/Magnetic%20probe/STL/spherical_socket.stl) | TPU
21 | End-part holder | MP | 2 | end_part_holder.stl (https://github.com/xmotion-project/karaloop/blob/main/karaloop_P3_0/Hardware/Mechanical%20Design/Sub-assembly/Magnetic%20probe/STL/end_part_holder.stl) | Tough PLA or ABS

05.08.2022 – V1.4 | General and Assembly description – karaloop P3.0 | P.26

This work was partially sponsored by Fondation Privée des HUG (https://www.fondationhug.org/) and Wyss Center (https://wysscenter.ch/) through support awarded to Ferran Galán at University of Geneva. (https://www.unige.ch/en/university/presentation/)

Quentin Praz, Ahmad Jaafar, Spiros Schoinas and Philippe Passeraub from HEPIA, (https://www.hesge.ch/hepia/) and Ferran Galán from University of Geneva (https://www.unige.ch/en/university/presentation/) contributed to the conception and development of karaloop P1.0, (https://github.com/xmotion-project/xMotion/wiki/karaloop-P1.0) P2.0 (https://github.com/xmotion-project/xMotion/wiki/karaloop-P2.0) and P3.0. (https://github.com/xmotion-project/xMotion/wiki/karaloop-P3.0)

karaloop P3.0 (https://github.com/xmotion-project/xMotion/wiki/karaloop-P3.0) is OSHWA-certified (https://certification.oshwa.org/) open source hardware [CH00016]. (https://certification.oshwa.org/list.html)

This document is licensed under Creative Commons Attribution 4.0 International (CC BY 4.0). (https://creativecommons.org/licenses/by/4.0/)

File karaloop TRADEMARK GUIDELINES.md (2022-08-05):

## Introduction

This document, the "Policy," outlines the ***karaloop*** project's (the "Project") policy for the use of its trademarks. While the Project uses open source licenses, the copyright license does not include an implied right or license to use its trademarks. 

The role of trademarks is to provide assurance about the origin of the products or services with which the trademark is associated, enabling the public to identify the entity from which the goods or services "come from", but because an open source license allows your unrestricted modification of the copyrighted materials (the "Materials", e.g. illustrations, source files, code, designs, schematics, documentation), we cannot be sure that your modifications to the Project's Materials are ones that will not be misleading if distributed under the same name. Instead, this Policy describes the circumstances under which you may use the Project's trademarks.

Through this Policy we are not trying to limit the lawful use of the Project's trademarks, but rather describe for you what we consider the parameters of lawful use to be. Trademark law can be ambiguous, so we hope to provide enough clarity for you to understand whether or not we will consider your use licensed or non-infringing.

The sections that follow describe what trademarks are covered by this Policy, as well as uses of the trademarks that are allowed without additional permission. 
If you want to use the Project's trademarks in ways that are not described in this Policy, please send an email to karaloop@protonmail.com with *Trademark Use* in the subject. We are reasonable and can work almost anything out provided we get a request in advance. Any use that does not comply with this Policy or for which we have not separately provided written permission is not a use that we have approved, so you must decide for yourself whether the use is nevertheless lawful.

## Our commitment to open source principles

We want to encourage and facilitate the use of our trademarks by the community, but do so in a way that still ensures that the trademarks are meaningful as a source and quality indicator for our Materials and the associated goods and services and continue to embody the high reputation of the Materials and the community associated with it. This Policy therefore tries to strike the proper balance between: 1) our need to ensure that the Project's trademarks remain reliable indicators of the qualities that they are meant to preserve and 2) our community members' desire to be full participants in the Project.

## Trademarks subject to the guidelines

### The Project's trademarks

This policy covers:

1. The Project's registered word trademarks and service marks (the "Word Marks"): "KARALOOP" (whether or not in capital letters)
2. The registered logo (the "Logo"): 

<p align="center">
		
</p>

3. And the unique visual styling of our online media and packaging (the "Trade Dress").

This Policy encompasses all trademarks and service marks, whether Word Marks, Logos or Trade Dress, which are collectively referred to as the “Marks.” Some Marks may not be registered, but registration does not equal ownership of trademarks. This Policy covers our Marks whether they are registered or not.

## Universal consideration for all uses

Whenever you use one of the Marks, you must always do so in a way that does not mislead anyone, either directly or by omission, about exactly what they are getting and from whom. The law reflects this requirement in two major ways described in more detail below: it prohibits creating a "likelihood of confusion" but allows for "nominative use." For example, you cannot say you are distributing ***karaloop*** Materials when you're distributing a modified version of them, because people would be confused when they are not getting the same features and functionality they would get if they downloaded the Materials directly from us. You also cannot use our logo on your website in a way that suggests that your website is an official website or that we endorse your website. You can, though, say you like the ***karaloop*** project, that you participate in the ***karaloop*** community, that you are providing an unmodified version of ***karaloop*** Materials, or that you wrote a book describing how to make a ***karaloop*** prototype.

This fundamental requirement, that it is always clear to people what they are getting and from whom, is reflected throughout this Policy. It should also serve as your guide if you are not sure about how you are using the Marks.

In addition, for a correct use of the Project's Marks and to avoid any misuse, the below conditions are compulsory:

1. You may not use the Marks in association with the use or distribution of the ***karaloop*** Materials if you are also not in compliance with their copyright license.

2. You may not use or register, in whole or in part, the Marks as part of your own trademark, service mark, domain name, company name, trade name, product name or service name. You should never incorporate our Marks into your company's logos or designs, or in any other material, irrespective of its support, online or offline (i.e. on posters, brochures, magazines, newsletters, websites, or other marketing materials to promote your events, products or services) without our prior written consent.

3. You may not use any similar sign or denomination in any way that could give rise to confusion or association with our Marks. For the avoidance of doubt, you may not use any variation of any of our Marks or any phonetic equivalent, foreign language equivalent, take-off, or any sign that replicates the “look and feel” of our Marks. By way of example, we would consider the following denomination too similar to one of our Marks: "Any mark ending with the letters KARALOOP or CARALUP" and "Any mark beginning with the letters KARALOOP or CARALUP". We are not bound by these examples, they are only provided for clarity.

4. You may not use the Mark:
	* as a verb or noun (instead it should be used only as an adjective followed by the generic name/noun), 
	* in its plural or possessive form
	* as an abbreviation or a similar or compatible form
	* combined with any other mark
	* more prominently than the name of your own company, product or service.
	* in a way aimed to show false advertising, misleading information/ promotional materials, etc.).

5. You agree that you will not acquire any rights in the Marks and that any goodwill generated by your use of the Marks inures solely to our benefit.

We reserve all rights to act against any infringing acts, either resulting from the violation of the Policy terms as mentioned above or from the rights stipulated by the provisions of the Trademark Law, and to bring such infringing acts to the attention of the competent legal bodies in order to restore our rights and seek compensation for any damages.

## General Information
### Trademark marking and legends
The first or most prominent mention of a Mark on a webpage, document, packaging, or documentation should be accompanied by a symbol indicating whether the mark is a registered trademark ("®") or an unregistered trademark ("™"). See our Trademark List for the correct symbol to use.

### What to do when you see abuse
If you are aware of any confusing use or misuse of the Marks in any way, we would appreciate you bringing this to our attention. Please contact us as described below so that we can investigate it further.

### Where to get further information
If you have any questions about this Policy, would like to speak with us about the use of our Marks in ways not described in the Policy, or see any abuse of our Marks, please email us to karaloop@protonmail.com with *Trademark Use* in the subject.

These guidelines are based on the Model Trademark Guidelines, available at http://www.modeltrademarkguidelines.org., used under a Creative Commons Attribution 3.0 Unported license: https://creativecommons.org/licenses/by/3.0/deed.en_US

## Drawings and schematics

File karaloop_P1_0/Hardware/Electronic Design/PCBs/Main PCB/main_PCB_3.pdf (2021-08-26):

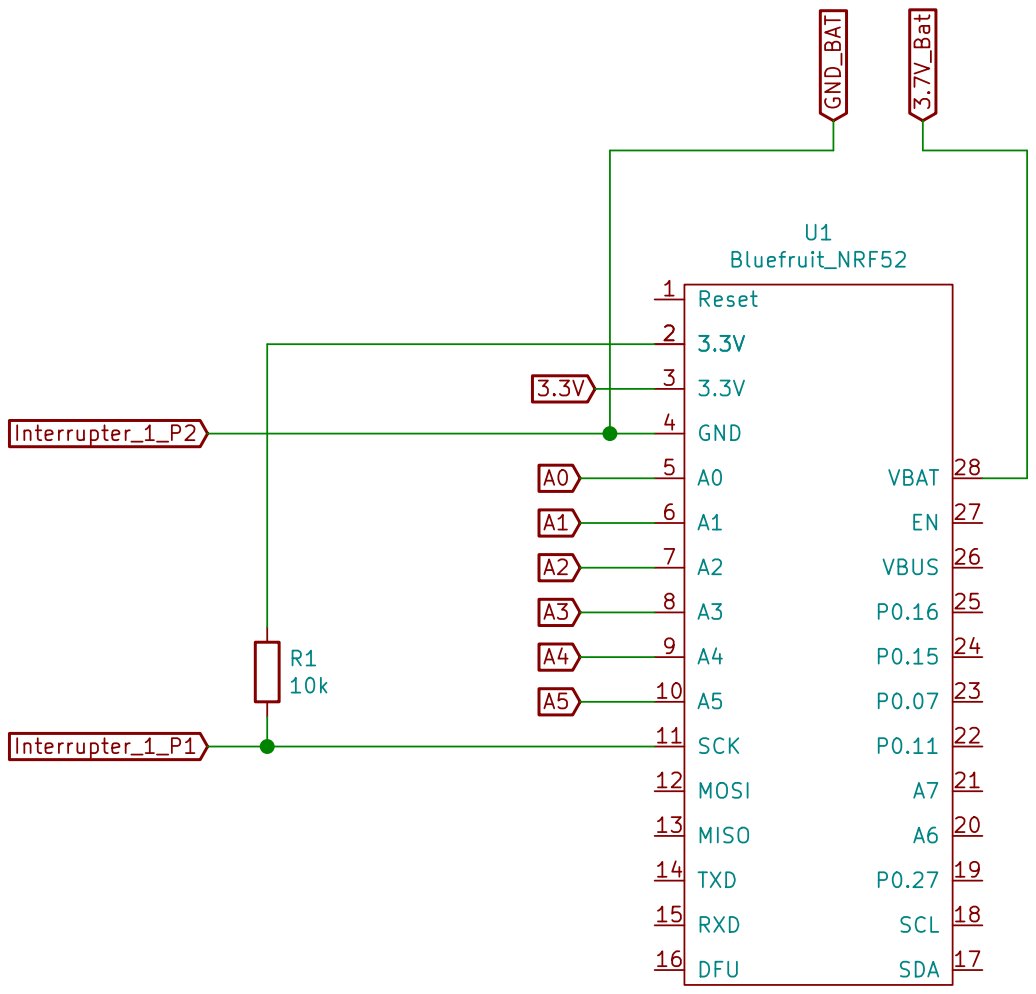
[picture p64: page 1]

Designed by Ahmad Jaafar Belt PCB - Main PCB

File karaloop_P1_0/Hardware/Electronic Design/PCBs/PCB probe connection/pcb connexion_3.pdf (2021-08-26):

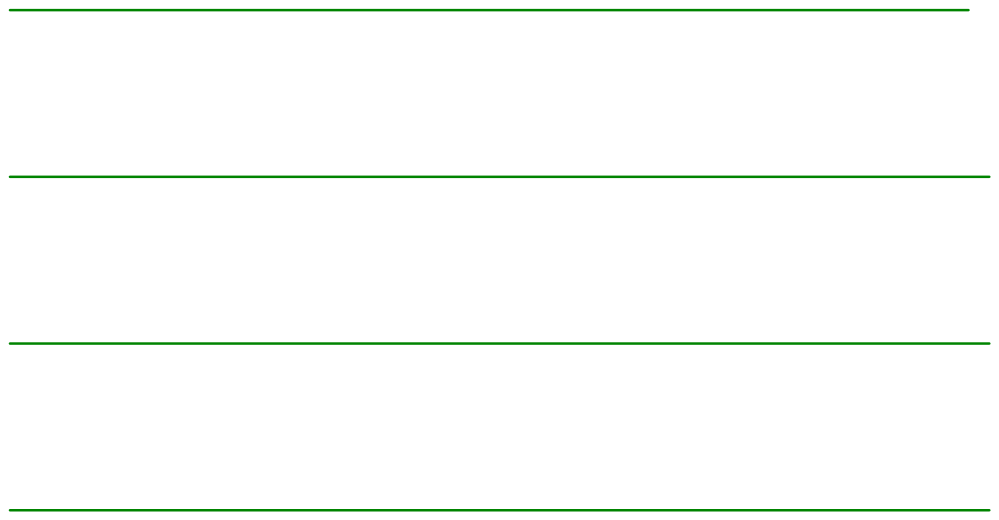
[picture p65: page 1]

File: pcb connexion_3.sch Sheet: / xMotion Project - P1

Designed by Ahmad Jaafar PCB de connexion 3

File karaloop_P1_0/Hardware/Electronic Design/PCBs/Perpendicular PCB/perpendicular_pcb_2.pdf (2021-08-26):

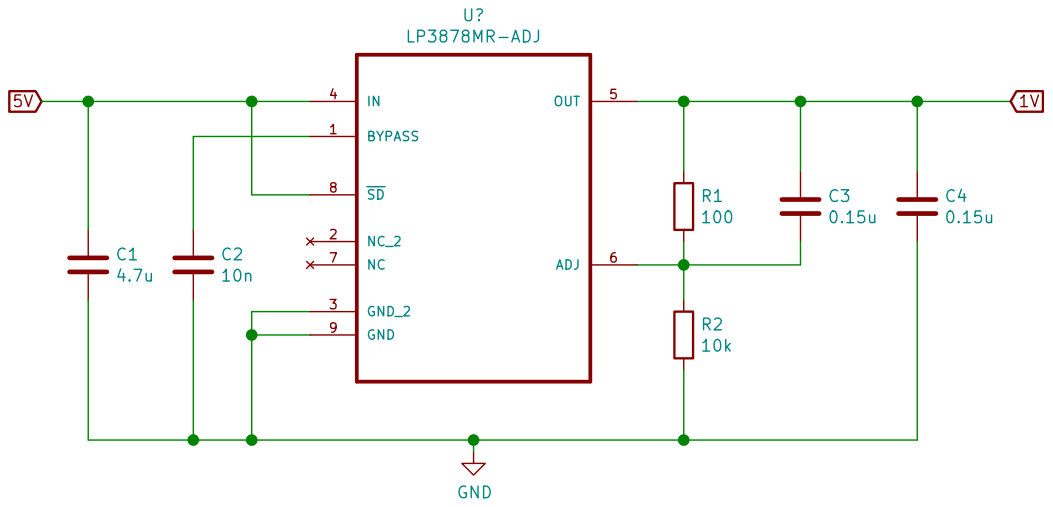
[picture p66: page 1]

Designed by Ahmad Jaafar

Perpendiculare PCB

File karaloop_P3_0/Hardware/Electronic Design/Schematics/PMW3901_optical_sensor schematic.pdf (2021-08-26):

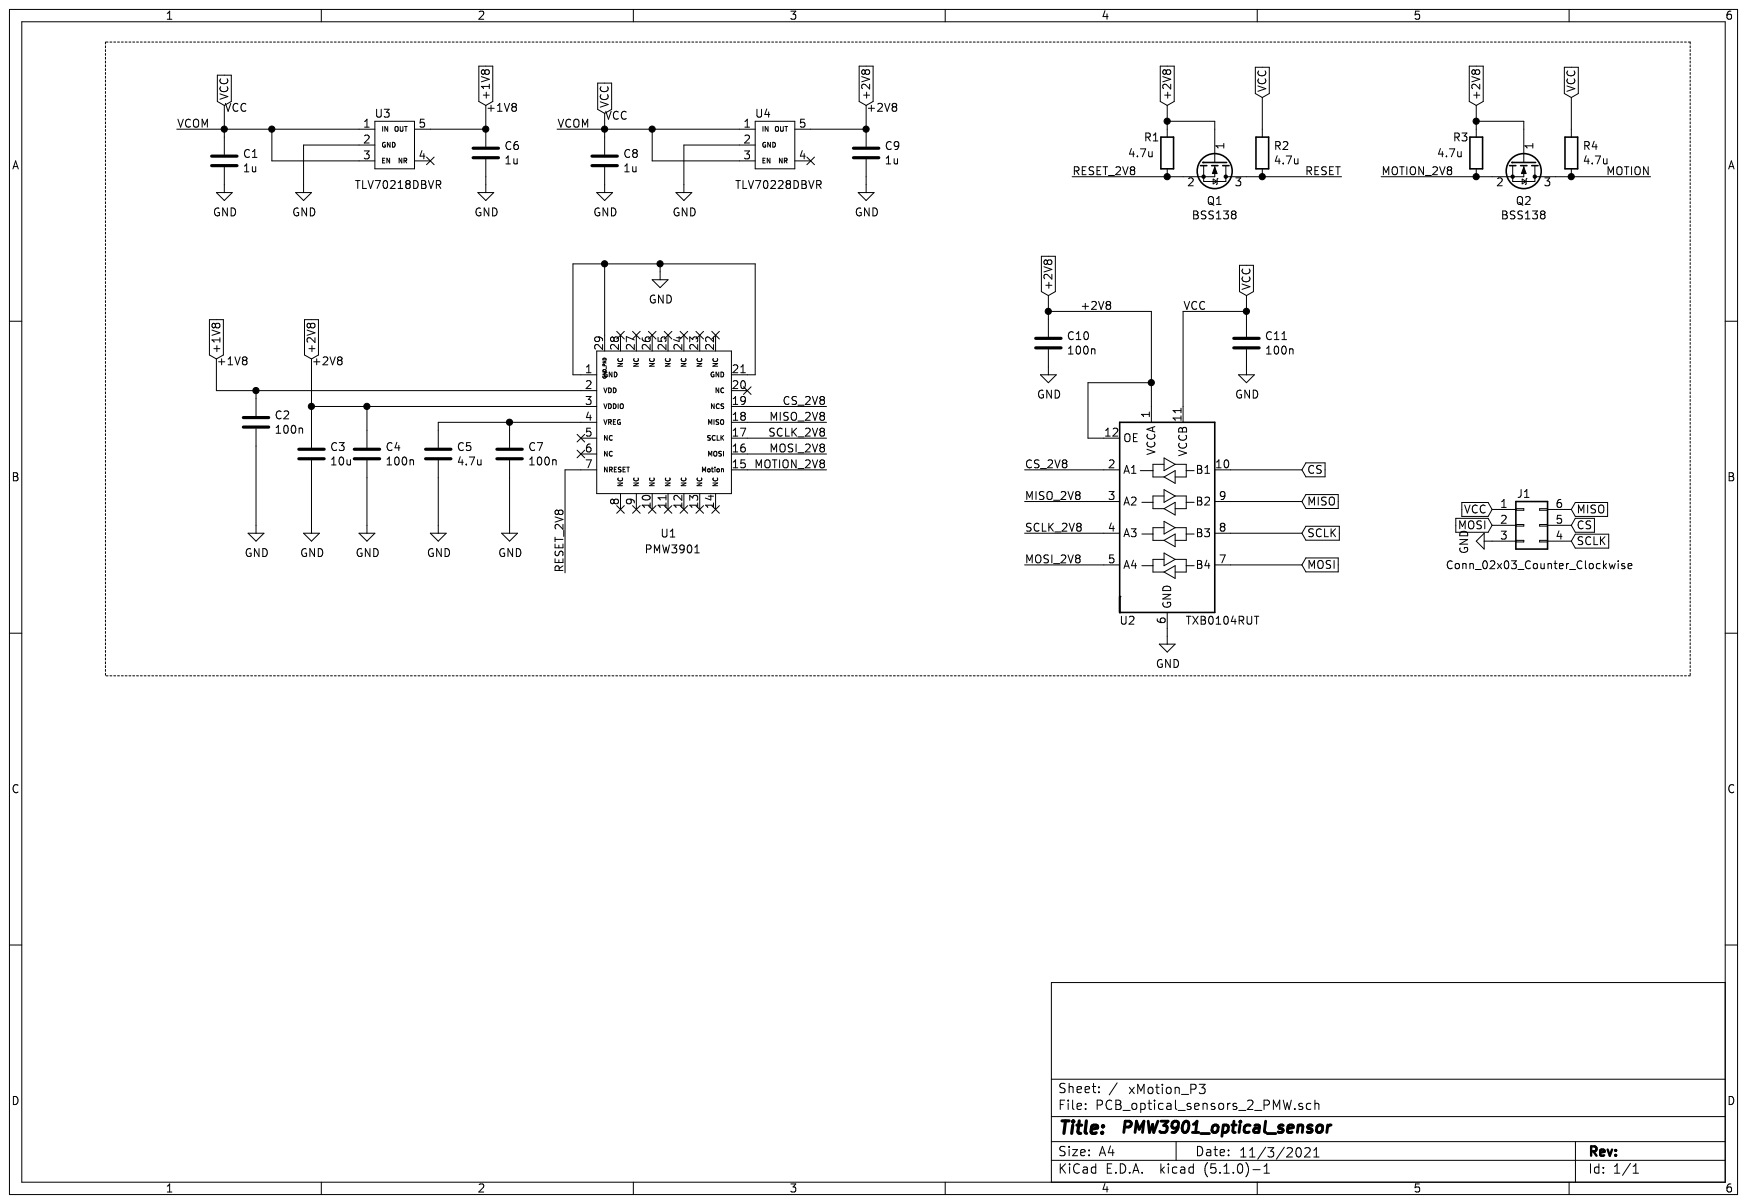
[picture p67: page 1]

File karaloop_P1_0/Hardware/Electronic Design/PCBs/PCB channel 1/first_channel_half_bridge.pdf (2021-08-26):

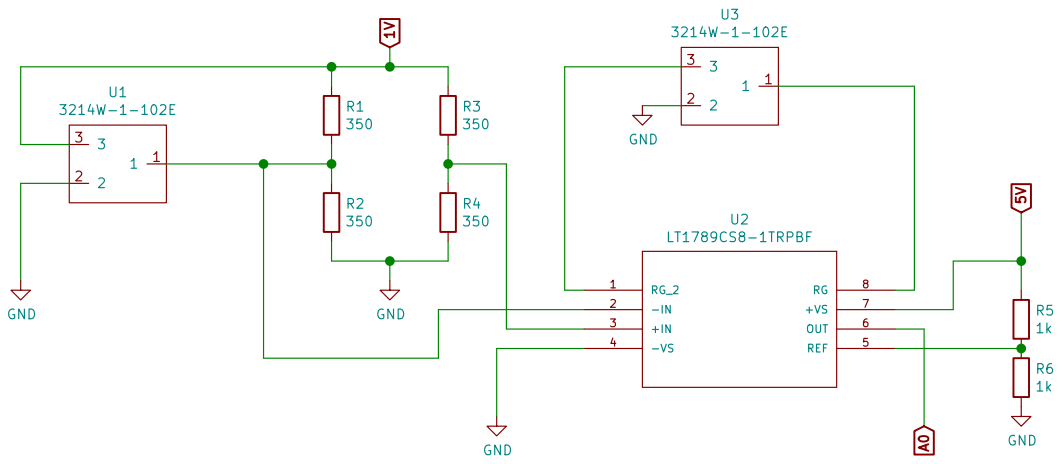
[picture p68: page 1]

16.01.2020 Designed by Ahmad Jaafar

First Channel wheatstone half bridge

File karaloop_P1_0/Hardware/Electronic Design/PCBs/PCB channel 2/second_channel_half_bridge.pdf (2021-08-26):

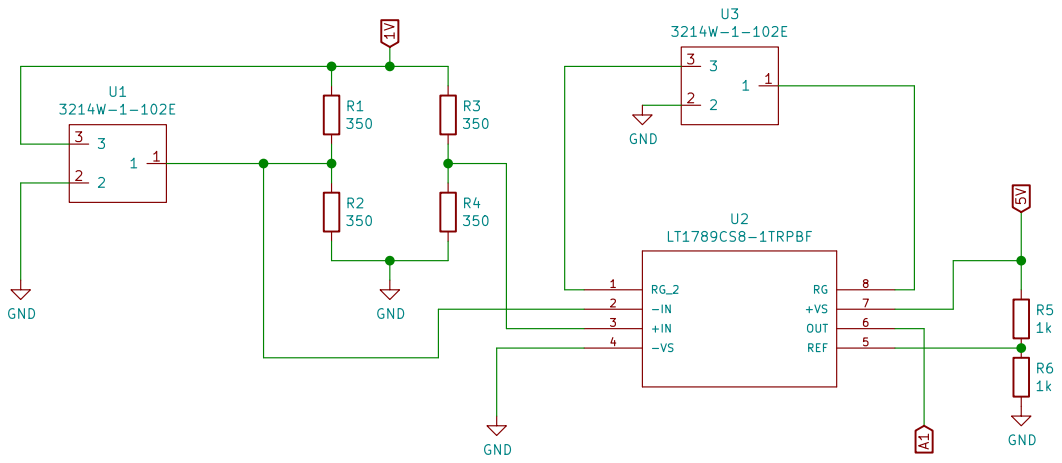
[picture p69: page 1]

Designed by Ahmad Jaafar

Second Channel wheatstone half bridge

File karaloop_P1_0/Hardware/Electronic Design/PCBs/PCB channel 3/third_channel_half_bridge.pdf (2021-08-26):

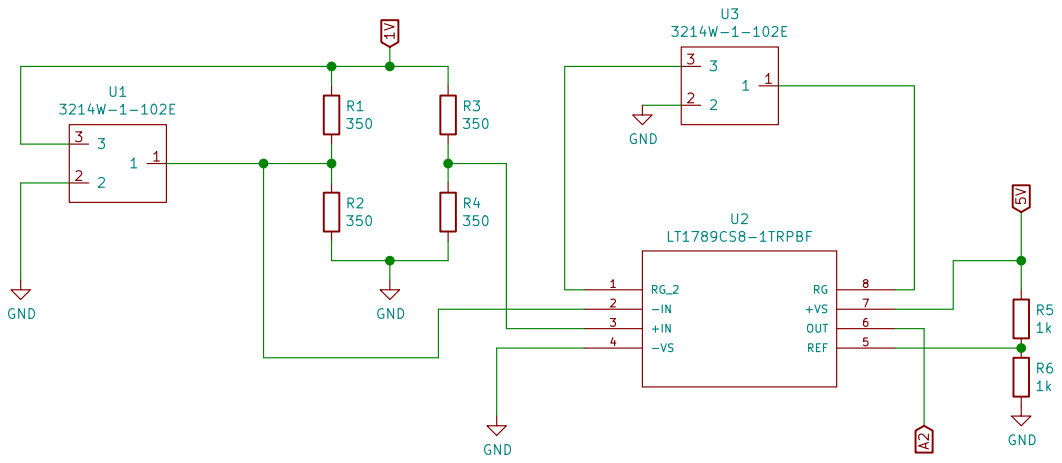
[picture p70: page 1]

Designed by Ahmad Jaafar

Third Channel wheatstone half bridge

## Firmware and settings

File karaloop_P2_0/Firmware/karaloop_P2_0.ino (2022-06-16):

// The prototype development work of karaloop P1.0, P2.0 and P3.0 was partially
// sponsored by Fondation Privée des HUG and Wyss Center through grants awarded
// to Ferran Galán at University of Geneva.

// Quentin Praz, Ahmad Jaafar, Spiros Schoinas and Philippe Passeraub from HEPIA,
// and Ferran Galán from University of Geneva contributed to the conception and
// development of karaloop P1.0, P2.0 and P3.0.


// Licensed under the Apache License, Version 2.0 (the "License");
// you may not use this file except in compliance with the License.
// You may obtain a copy of the License at

//    http://www.apache.org/licenses/LICENSE-2.0

// Unless required by applicable law or agreed to in writing, software
// distributed under the License is distributed on an "AS IS" BASIS,
// WITHOUT WARRANTIES OR CONDITIONS OF ANY KIND, either express or implied.
// See the License for the specific language governing permissions and
// limitations under the License.

// Librairies
#include <bluefruit.h>
#define MOVE_STEP 10

// Defining input
const int Wheel_left = A1;
const int Wheel_right = A0;
const int switch_left = 15;
const int switch_right = 16;
const int ledPin_left =  17;
const int ledPin_right =  19;

// Global variables
const int numReadings = 10;
int readingsA0[numReadings];      // the readings from the analog input
int readingsA1[numReadings];      // the readings from the analog input
int readIndex = 0;              // the index of the current reading
int IndexOffset = 0;
int totalA0 = 0;                  // the running total
int totalA1 = 0;                  // the running total
int averageA0 = 0;                // the average
int averageA1 = 0;                // the average

float EMA_a = 0;    //initialization of EMA alpha
int EMA_A0 = 0;
int EMA_A1 = 0;

int highpass0 = 0;
int highpass1 = 0;
int highpass0_cut = 0;
int highpass1_cut = 0;
int Tlim = 0;

unsigned int  MemTimeSerial;
unsigned int  tempTime = 0;

int VThigh = 0;
int VTlow = 0;
int HPthreshold = 0;
int Th_EMAhigh = 0;
int Th_EMAlow = 0;

float periode_pos_right = 0.0;
int periode_neg_right = 0;
int wheel_dir_right = 0;
boolean zero_right = true;
int OuptutWheel_right = 0;
int OuptutWheel_right_old = 0;

int periode_pos_left = 0;
int periode_neg_left = 0;
int wheel_dir_left = 0;
boolean zero_left = true;
int OuptutWheel_left = 0;
int OuptutWheel_left_old = 0;

int periode_value_right = 1;
int periode_value_left = 1;

int ValidState_right = 0;
int ValidState_left = 0;

boolean state = false;
boolean stateDelay = false;
unsigned int  MemTimeDelay;
unsigned int  delayTime = 0;

int switchState_left = 0;
int switchState_right = 0;

int counter = 0;

// Objects
BLEDis bledis;
BLEHidAdafruit blehid;

void setup() {
  Serial.begin(115200);
  Init();
}

// ----------------------------------------------------------------------------------------
// Init Bluefruit
// ----------------------------------------------------------------------------------------
void Init()
{
  Bluefruit.begin();
  // HID Device can have a min connection interval of 9*1.25 = 11.25 ms
  Bluefruit.Periph.setConnInterval(9, 16); // min = 9*1.25=11.25 ms, max = 16*1.25=20ms
  Bluefruit.setTxPower(4);    // Check bluefruit.h for supported values
  Bluefruit.setName("xMotionP2");

  // Configure and Start Device Information Service
  bledis.setManufacturer("xMotion");
  bledis.setModel("xMotion P2");
  bledis.begin();

  // BLE HID
  blehid.begin();

  // Set up and start advertising
  startAdv();

  // Initialize all the readings to 0:
  for (int thisReadingA0 = 0; thisReadingA0 < numReadings; thisReadingA0++) {
    readingsA0[thisReadingA0] = 0;
  }
  for (int thisReadingA1 = 0; thisReadingA1 < numReadings; thisReadingA1++) {
    readingsA0[thisReadingA1] = 0;
  }

  //Set input/output
  pinMode(ledPin_left, OUTPUT);
  pinMode(ledPin_right, OUTPUT);
  pinMode(switch_left, INPUT);
  pinMode(switch_right, INPUT);
}

// ----------------------------------------------------------------------------------------
// BT Advertising
// ----------------------------------------------------------------------------------------
void startAdv(void)
{
  // Advertising packet
  Bluefruit.Advertising.addFlags(BLE_GAP_ADV_FLAGS_LE_ONLY_GENERAL_DISC_MODE);
  Bluefruit.Advertising.addTxPower();
  Bluefruit.Advertising.addAppearance(BLE_APPEARANCE_HID_MOUSE);

  // Include BLE HID service
  Bluefruit.Advertising.addService(blehid);

  // There is enough room for 'Name' in the advertising packet
  Bluefruit.Advertising.addName();

  /* Start Advertising
     - Enable auto advertising if disconnected
     - Interval:  fast mode = 20 ms, slow mode = 152.5 ms
     - Timeout for fast mode is 30 seconds
     - Start(timeout) with timeout = 0 will advertise forever (until connected)

     For recommended advertising interval
     https://developer.apple.com/library/content/qa/qa1931/_index.html
  */
  Bluefruit.Advertising.restartOnDisconnect(true);
  Bluefruit.Advertising.setInterval(32, 244);    // in unit of 0.625 ms
  Bluefruit.Advertising.setFastTimeout(30);      // number of seconds in fast mode
  Bluefruit.Advertising.start(0);                // 0 = Don't stop advertising after n seconds
}

// ----------------------------------------------------------------------------------------
// Smooth potentiometers readings
// ----------------------------------------------------------------------------------------

void Potentiometers_Smooth()
{

  // Subtract the last reading:
  totalA0 = totalA0 - readingsA0[readIndex];
  totalA1 = totalA1 - readingsA1[readIndex];

  // Read from the sensor:
  readingsA0[readIndex] = analogRead(Wheel_left);
  readingsA1[readIndex] = analogRead(Wheel_right);

  // Add the reading to the total:
  totalA0 = totalA0 + readingsA0[readIndex];
  totalA1 = totalA1 + readingsA1[readIndex];

  // Advance to the next position in the array:
  readIndex = readIndex + 1;

  // If we're at the end of the array...
  if (readIndex >= numReadings) {
    // ...wrap around to the beginning:
    readIndex = 0;
  }

  // Calculate the average and remove the offset to center around 0:
  averageA0 = (totalA0 / numReadings);
  averageA1 = (totalA1 / numReadings);

}
// ----------------------------------------------------------------------------------------
// Potentiomerters HP filter
// ----------------------------------------------------------------------------------------
void Potentiometers_HPfilter()
{

  // Coefficient to modifiy the hp filter
  EMA_a = 0.3;

  EMA_A0 = (EMA_a * averageA0) + ((1 - EMA_a) * EMA_A0); //run the EMA
  EMA_A1 = (EMA_a * averageA1) + ((1 - EMA_a) * EMA_A1); //run the EMA

  highpass0 = averageA0 - EMA_A0;                   //calculate the high-pass signal
  highpass1 = averageA1 - EMA_A1;                   //calculate the high-pass signal

  // Removing noise around 0 when doing no movement
  Tlim = 4;

  if (highpass0 < Tlim && highpass0 > -Tlim ) {
    highpass0_cut = 0;
  }
  else {
    highpass0_cut = highpass0;
  }
  if (highpass1 < Tlim && highpass1 > -Tlim ) {
    highpass1_cut = 0;
  }
  else {
    highpass1_cut = highpass1;
  }
}

// ----------------------------------------------------------------------------------------
// Detecting wheel movements
// ----------------------------------------------------------------------------------------
void Potentiometers_Detection()
{
  HPthreshold = Tlim;

  // Thresholds for detecting wheel movements
  VThigh = Tlim + 1 ;
  VTlow = -VThigh;

  // No detection Right
  if ((highpass0_cut < VThigh) && (ValidState_right == 0) && (highpass0_cut > VTlow) && (zero_right == true)) {
    periode_pos_right = 0 ;
    periode_neg_right = 0 ;
    OuptutWheel_right = 0;
    ValidState_right = 1;
  }

  // No detection Left
  if ((highpass1_cut < VThigh) && (ValidState_left == 0) && (highpass1_cut > VTlow) && (zero_left == true)) {
    periode_pos_left = 0 ;
    periode_neg_left = 0 ;
    OuptutWheel_left = 0;
    ValidState_left = 1;
  }

  // Positive direction Right
  if ((highpass0_cut > VThigh) && (ValidState_right == 1) && (zero_right == true) && (periode_neg_right == 0)) {
    periode_pos_right = periode_value_right ;
    wheel_dir_right = 1;
    OuptutWheel_right = periode_pos_right * wheel_dir_right;
    zero_right = false;
  }

  if ((highpass0_cut < VThigh) && (ValidState_right == 1) && (highpass0_cut > VTlow) && (periode_pos_right == periode_value_right) && (periode_neg_right == 0)) {
    OuptutWheel_right = periode_pos_right * wheel_dir_right;
//    OuputWheel_right = 0;
    zero_right = false;
  }

  if ((highpass0_cut < VTlow) && (ValidState_right == 1) && (periode_pos_right == periode_value_right) && (periode_neg_right == 0)) {
    OuptutWheel_right = 0;
    zero_right = true;
    ValidState_right = 0;
  }

  // Negative direction Right
  if ((highpass0_cut < VTlow) && (ValidState_right == 1) && (zero_right == true) && (periode_pos_right == 0)) {
    periode_neg_right = periode_value_right ;
    wheel_dir_right = -1;
    OuptutWheel_right = periode_neg_right * wheel_dir_right;
    zero_right = false;
  }

  if ((highpass0_cut < VThigh) && (ValidState_right == 1) && (highpass0_cut > VTlow) && (periode_neg_right == periode_value_right) && (periode_pos_right == 0)) {
    OuptutWheel_right = periode_neg_right * wheel_dir_right;
//    OuptutWheel_right = 0;
    zero_right = false;
  }

  if ((highpass0_cut > VThigh) && (ValidState_right == 1) && (periode_neg_right == periode_value_right) && (periode_pos_right == 0)) {
//        OuptutWheel_right = periode_neg_right * wheel_dir_right;
    OuptutWheel_right = 0;
    zero_right = true;
    ValidState_right = 0;
  }

  // Positive direction Left
  if ((highpass1_cut > VThigh) && (ValidState_left == 1) && (zero_left == true) && (periode_neg_left == 0)) {
    periode_pos_left = periode_value_left ;
    wheel_dir_left = 1;
    OuptutWheel_left = periode_pos_left * wheel_dir_left;
    zero_left = false;
  }

  if ((highpass1_cut < VThigh) && (ValidState_left == 1) && (highpass1_cut > VTlow) && (periode_pos_left == periode_value_left) && (periode_neg_left == 0)) {
    OuptutWheel_left = periode_pos_left * wheel_dir_left;
//    OuptutWheel_left = 0;
    zero_left = false;
  }

  if ((highpass1_cut < VTlow) && (ValidState_left == 1) && (periode_pos_left == periode_value_left) && (periode_neg_left == 0)) {
//    OuptutWheel_left = periode_pos_left * wheel_dir_left;
    OuptutWheel_left = 0;
    zero_left = true;
    ValidState_left = 0;
  }

  // Negative direction Left
  if ((highpass1_cut < VTlow) && (ValidState_left == 1) && (zero_left == true) && (periode_pos_left == 0)) {
    periode_neg_left = periode_value_left;
    wheel_dir_left = -1;
    OuptutWheel_left = periode_neg_left * wheel_dir_left;
    zero_left = false;
  }

  if ((highpass1_cut < VThigh) && (ValidState_left == 1) && (highpass1_cut > VTlow) && (periode_neg_left == periode_value_left) && (periode_pos_left == 0)) {
    OuptutWheel_left = periode_neg_left * wheel_dir_left;
//    OuptutWheel_left = 0;
    zero_left = false;
  }

  if ((highpass1_cut > VThigh) && (ValidState_left == 1) && (periode_neg_left == periode_value_left) && (periode_pos_left == 0)) {
//    OuptutWheel_left = periode_neg_left * wheel_dir_left;
    OuptutWheel_left = 0;
    zero_left = true;
    ValidState_left = 0;
  }
}

// ----------------------------------------------------------------------------------------
// Mapping potentiometers to mouse translational function
// ----------------------------------------------------------------------------------------
void Potentiometers_classification()
{
//  int delayValue = 50;
//  delayTime = millis();
//
//  //Changing state detection
//  if (OuptutWheel_left != OuptutWheel_left_old || OuptutWheel_right != OuptutWheel_right_old)
//  {
//    state = true;
//    stateDelay = false;
//    MemTimeDelay = delayTime;
//  }
//
//  // Waiting a delay if both movements are not synchronized
//  if ((delayTime - MemTimeDelay > delayValue) && state == true)
//  {
//    state = false;
//    stateDelay = true;
//  }

  // Lower Lips right --> Mouse X+
  if (OuptutWheel_left == 1 && OuptutWheel_right == 0)// && stateDelay == true)
  {
      blehid.mouseMove(-MOVE_STEP, 0);
  }

  // Lower Lips left  --> Mouse X-
  if (OuptutWheel_left == 0 && OuptutWheel_right == -1)// && stateDelay == true)
  {
    blehid.mouseMove(MOVE_STEP, 0);
  }

  // Pursing Lips     --> Mouse Y+
  if (OuptutWheel_left == 1 && OuptutWheel_right == -1)// && stateDelay == true)
  {
    blehid.mouseMove(0, MOVE_STEP);
  }

  // Compression Lips --> Mouse Y-
  if (OuptutWheel_left == -1 && OuptutWheel_right == 1)// && stateDelay == true)
  {
    blehid.mouseMove(0, -MOVE_STEP);
  }

}

// ----------------------------------------------------------------------------------------
// Mapping switches to mouse wheel function
// ----------------------------------------------------------------------------------------
void Switches()
{
  switchState_left = digitalRead(switch_left);
  switchState_right = digitalRead(switch_right);

  if (switchState_left == LOW) {
    digitalWrite(ledPin_left, HIGH);
    //    blehid.mouseScroll(-MOVE_STEP);
  }

  if (switchState_left == HIGH) {
    digitalWrite(ledPin_left, LOW);
    blehid.mouseScroll(0);
  }

  if (switchState_right == LOW) {
    digitalWrite(ledPin_right, HIGH);
    //    blehid.mouseScroll(MOVE_STEP);
  }

  if (switchState_right == HIGH) {
    digitalWrite(ledPin_right, LOW);
    blehid.mouseScroll(0);
  }
}

// ----------------------------------------------------------------------------------------
// Main loop
// ----------------------------------------------------------------------------------------
void loop() {

  tempTime = millis();

  if ((tempTime - MemTimeSerial) > 20)
  {
    MemTimeSerial = tempTime;

    OuptutWheel_right_old = OuptutWheel_right;
    OuptutWheel_left_old = OuptutWheel_left;

    Potentiometers_Smooth();
    Potentiometers_HPfilter();
    Potentiometers_Detection();
    Potentiometers_classification();
    Switches();

    // Show signals

//    Serial.print(OuptutWheel_left);
//    Serial.print("\t");
//    Serial.print(OuptutWheel_right);
//    Serial.println("\t");
//    Serial.print(counter);
//    Serial.print("\t");
//    Serial.println(displacement);
//    Serial.print("\t");
//    Serial.println(averageA1);
//    Serial.print("\t");
//    Serial.println(EMA_A0);
//    Serial.print("\t");
//    Serial.println(EMA_A1);
//    Serial.print(highpass0);
//    Serial.print("\t");
//    Serial.println(highpass1);
//    Serial.print("\t");
//    Serial.print(highpass1_cut);
//    Serial.print("\t");
//    Serial.println(highpass0_cut);

    delay(3);        // delay in between reads for stability
  }
}

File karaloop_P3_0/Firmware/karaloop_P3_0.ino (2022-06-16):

// The prototype development work of karaloop P1.0, P2.0 and P3.0 was partially
// sponsored by Fondation Privée des HUG and Wyss Center through grants awarded
// to Ferran Galán at University of Geneva.

// Quentin Praz, Ahmad Jaafar, Spiros Schoinas and Philippe Passeraub from HEPIA,
// and Ferran Galán from University of Geneva contributed to the conception and
// development of karaloop P1.0, P2.0 and P3.0.


// Licensed under the Apache License, Version 2.0 (the "License");
// you may not use this file except in compliance with the License.
// You may obtain a copy of the License at

//    http://www.apache.org/licenses/LICENSE-2.0

// Unless required by applicable law or agreed to in writing, software
// distributed under the License is distributed on an "AS IS" BASIS,
// WITHOUT WARRANTIES OR CONDITIONS OF ANY KIND, either express or implied.
// See the License for the specific language governing permissions and
// limitations under the License.

// Librairies
#include <Wire.h>
#include <MLX90393.h>
#include <stdlib.h>
#include <math.h>
#include <bluefruit.h>
#include <SPI.h>
#include "Bitcraze_PMW3901.h"

// Inputs / Outputs
const int L1 = 11;
const int MagSwitchButton =  30;
const int MouseSwitchButton =  27;
const int ledPin =  17;
const int chipSelectPin = 7;    //Chip Select Pin
const int dataINPin = 14;       //MISO
const int dataOUTPin = 13;      //MOSI
const int serialClockPin = 12;  //CSK
#define Led_Mag_right   A0
#define Led_Mag_left    A1

// Objects
MLX90393 mlx_left, mlx_right;
MLX90393::txyz data_left, data_right;
BLEDis bledis;
BLEHidAdafruit blehid;
Bitcraze_PMW3901 flow(chipSelectPin);

// Global variables
// Buttons
int reading_MouseSwitch;
int reading_MagSwitch;
bool ButtonMagState  = false;
bool ButtonMouseState  = false;
bool oldStatusMag  = false;
bool oldStatusMouse  = false;
unsigned long lastDebounceTimeMag  = 0;
unsigned long lastDebounceTimeMouse  = 0;
unsigned long debounceDelay  = 50;
bool SwitchMouseON = true;
bool SwitchMagON = true;

double current_value_right;
double current_value_left;
int valueStateRight;
int valueStateLeft;
int OldvalueStateRight;
int OldvalueStateLeft;
int current_state_right;
int current_state_left;
int old_state_right;
int old_state_left;
int highpassRight = 0;
int highpassLeft = 0;

boolean DispMag = false;
boolean DispBoth = false;
boolean ChangeSpeed = false;
boolean Callonce = false;
boolean MouseToKeyboard = true;

boolean MouseMove = false;
int MOVE_STEP = 10;
int MoveMax = 5;

float init_mlx_left;
float init_mlx_right;

int16_t deltaX, deltaY;

//Threshold Mag
int Tmin = 2000;
int Tmax = 7000;
int Ttolerance = 1000;
int Toffset = 600;
int Tinit_min;
int Tinit_max;

//Right Threshold
float max_T1_right = 0;
float max_T2_right = 0;

//Left Threshold
float max_T3_left = 0;
float max_T4_left = 0;

void Init_BLE(void);
void Init_mlx(void);
void Init_optical(void);
void OpticalSensor(void);
float ExponentialSpeedMouse(float currentValue, boolean Direction, int speedMax);
void FrontButtons(void);


//--------------------------------------------------------------------------------------//
void setup(void)
{
  DispMag = true;           //DispMag = True --> Activate Magnetometer and Disactivate Optical ; DispMag = false --> Disactivate Magnetometer and Activate Optical
  DispBoth = true;
  Wire.begin();             // join i2c bus (address optional for master)

  Serial.begin(115200);

  while ( !Serial ) delay(10);   // for nrf52840 with native usb

  // set the input & output:
  pinMode(MouseSwitchButton, INPUT_PULLUP);
  pinMode(MagSwitchButton, INPUT_PULLUP);
  pinMode(ledPin, OUTPUT);
  pinMode(L1, OUTPUT);
  pinMode(dataINPin, INPUT);
  pinMode(dataOUTPin, OUTPUT);
  pinMode(chipSelectPin, OUTPUT);
  pinMode(serialClockPin, OUTPUT);
  pinMode(Led_Mag_right, OUTPUT);
  pinMode(Led_Mag_left, OUTPUT);


  analogWrite(L1, 100);

  Init_BLE();

  if (DispBoth == true) {
    Init_mlx();
    Init_optical();
  }
  else
  {
    if (DispMag == true) {
      Init_mlx();
    }
    else {
      Init_optical();
    }
  }
}

//--------------------------------------------------------------------------------------//
// Button 1 (UP) : Magnetometer mode
// ON : Adjustement on the central position --> LED ON when magnetometer is inside the
// tolerance (switchMode = true)
// OFF : Visual verficication of the mouse --> LED ON when magnetometer is hiting extremity
// of the guide (switchMode = false)
// Push more than one seconde : change mode between MOUSE and KEYBOARD
//--------------------------------------------------------------------------------------//
void MagSwitch() {

  reading_MagSwitch = digitalRead(MagSwitchButton);
  static boolean mode = false;

  if (reading_MagSwitch != oldStatusMag) {
    lastDebounceTimeMag = millis();
    mode = true;
  }
  if ((millis() - lastDebounceTimeMag) >= debounceDelay) {
    if (reading_MagSwitch != ButtonMagState) {
      ButtonMagState = reading_MagSwitch;
      if (ButtonMagState == false) {
        SwitchMagON = ! SwitchMagON;
      }
    }
  }
  // Change mode between MOUSE and KEYBOARD
  if (((millis() - lastDebounceTimeMag) >= 1000) && reading_MagSwitch == 0 && mode == true) {
    MouseToKeyboard = !MouseToKeyboard;
    //Serial.println("test");
    mode = false;
  }
  oldStatusMag = reading_MagSwitch;
  //Serial.println(reading_MagSwitch);
}

//--------------------------------------------------------------------------------------//
// Button 2 (DOWN) : Mouse ON/OFF
// ON : Activate the mouse function
// OFF : Deactivate the mouse function
//--------------------------------------------------------------------------------------//
void MouseSwitch() {

  reading_MouseSwitch = digitalRead(MouseSwitchButton);

  if (reading_MouseSwitch != oldStatusMouse) {
    lastDebounceTimeMouse = millis();
  }
  if ((millis() - lastDebounceTimeMouse) >= debounceDelay) {
    if (reading_MouseSwitch != ButtonMouseState) {
      ButtonMouseState = reading_MouseSwitch;
      if (ButtonMouseState == false) {
        SwitchMouseON = ! SwitchMouseON;
      }
    }
  }
  oldStatusMouse = reading_MouseSwitch;
}

//--------------------------------------------------------------------------------------//
// Display signals on the serial plotter such as magnetic signals and thresholds
//--------------------------------------------------------------------------------------//
void DisplayMag(void)
{
  Serial.print(current_value_right);
  Serial.print(" ");
  Serial.print(current_value_left);
  Serial.print(" ");
  Serial.print(Tmin);
  Serial.print(" ");
  Serial.print(Tmax);
  Serial.print(" ");
  Serial.print(Tinit_min);
  Serial.print(" ");
  Serial.println(Tinit_max);
}
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

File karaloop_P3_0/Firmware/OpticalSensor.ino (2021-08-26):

unsigned int  delayTime_optique = 0;
unsigned int  MemTimeDelay_optique;
const int optical_threshold = 10;
const int delay_relaxation = 500;
float time_passed;

// Reference : https://github.com/bitcraze/Bitcraze_PMW3901/blob/master/examples/flow/flow.ino
//--------------------------------------------------------------------------------------//
//
//--------------------------------------------------------------------------------------//
void OpticalSensor()
{
  static int delayValue_optique = 20;
  delayTime_optique = millis();

  // Waiting a delay if both movements are not synchronized
  if (((delayTime_optique - MemTimeDelay_optique) > delayValue_optique))
  {
    // Get motion count since last call
    flow.readMotionCount(&deltaX, &deltaY);
    //        Serial.print(deltaX);
    //        Serial.print(" ");
    //        Serial.println(deltaY);
    time_passed = millis();
    MemTimeDelay_optique = delayTime_optique;


    if (deltaY < -optical_threshold && MouseMove == false) {



      while (millis() < time_passed + delay_relaxation) {
        delay(20);
        flow.readMotionCount(&deltaX, &deltaY);
        //      Serial.print(deltaX);
        //      Serial.print(" ");
        //      Serial.println(deltaY);
        if (deltaY > optical_threshold) {
          blehid.mouseButtonPress(MOUSE_BUTTON_LEFT);
          delay(1);
          blehid.mouseButtonRelease();
          break;
        }
      }

      while (millis() > time_passed + delay_relaxation && millis() < time_passed + 2 * delay_relaxation) {
        //      Serial.print(deltaX);
        //      Serial.print(" ");
        //      Serial.println(deltaY);
        delay(20);
        flow.readMotionCount(&deltaX, &deltaY);

        if (deltaY > optical_threshold) {
          blehid.mouseButtonPress(MOUSE_BUTTON_RIGHT);
          delay(1);
          blehid.mouseButtonRelease();
          break;
        }
      }


    while (millis() > time_passed + 2 * delay_relaxation) {
      blehid.mouseButtonPress(MOUSE_BUTTON_LEFT);
      break;
    }

    if (deltaY < -optical_threshold)
    {
      blehid.mouseButtonRelease();
      }



    }

  }

}

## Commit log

2021-08-26 Renaming files
    [potentiometric_wheel.stl, probe_holder.stl]
2021-09-14 Renaming folders
    [Battery.step, Button.stp, Feather.step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]
2021-11-16 Curating assembly guides, CAD, STL files
    [Battery.step, Button.stp, Feather.step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]
2021-11-16 Curate assembly guide hyperlinks
2022-06-13 Curating files
    [attach_ear.stl, attache_1.stl, bluefruit.step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]
2022-06-14 Create ~$raloop P2 - General and Assembly description.docx
2022-06-16 Update karaloop P2 - General and Assembly description.pdf
2022-07-05 Curating Assembly guides
    [xMotion P1.xlsx]
2022-07-11 Curating P1 Mech files
    [attach_ear.stl, attache_1.stl, ball_joint_connector_12.stl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]
2022-07-11 Update files
    [hub_cover_box_left.stl, hub_cover_box_right.stl]
2022-08-05 Update assembly guides
